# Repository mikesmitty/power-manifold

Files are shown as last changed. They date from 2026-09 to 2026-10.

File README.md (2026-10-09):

# Power Manifold

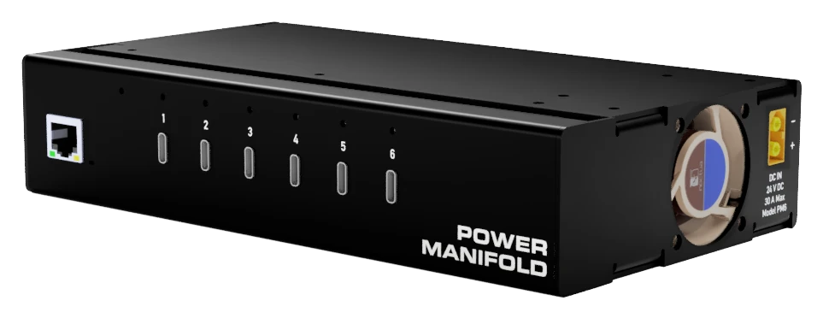
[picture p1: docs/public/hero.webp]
Power Manifold chassis from the front right


A six-port USB-C power supply: up to 100 W per port from one 24 V supply,
with per-port control, priority-based power sharing and Home Assistant
support. This repository holds the hardware (KiCad), the firmware and the
documentation site.

**Documentation:** <https://docs.powermanifold.io/>

- [First-time setup](https://docs.powermanifold.io/setup/first-time-setup/)
- [User guide](https://docs.powermanifold.io/guide/front-panel/)
- [Integrations](https://docs.powermanifold.io/integrations/mqtt/): MQTT,
  Home Assistant and the HTTP API
- [Hardware architecture](https://docs.powermanifold.io/developers/architecture/)

## Repository layout

| Path | Contents |
| --- | --- |
| `hardware/backplane` | Backplane KiCad project |
| `hardware/backplane-backer` | Insulating FR4 backer plate between the backplane and the rear wall |
| `hardware/charger-module` | Charger blade KiCad project |
| `hardware/controller` | Management controller card KiCad project |
| `hardware/left-side-plate` | Left chassis side plate, fabricated as a bare PCB |
| `hardware/pcie-breakout` | Pico 2 W development carrier for the management slot |
| `hardware/status-strip` | Front-panel status LED strip |
| `hardware/libraries` | Shared KiCad symbols and footprints |
| `hardware/CAD` | STEP exports of the boards |
| `firmware/controller` | Management controller firmware (RP2350) and its host tests |
| `firmware/charger-module` | Charger blade firmware (STM32G071) and its host tests |
| `firmware/update-proxy` | Cloudflare Worker that serves controller update images |
| `docs` | The documentation site (Astro and Starlight) |

Each firmware directory has a short README with build commands. Its full
developer documentation is in its `docs/` directory and is published on the
documentation site.

CI exports KiCad fabrication outputs when a board changes, and
release-please cuts a release for each component.

## License

Copyright 2024-2026 Michael Smith.

| Part | License |
| --- | --- |
| Hardware designs in `hardware/` | CERN-OHL-P-2.0 ([LICENSE-hardware](LICENSE-hardware)) |
| Documentation: Markdown files (`.md`, `.mdx`), the screenshots in `docs/src/assets/` and the site icon `docs/public/favicon.svg` | CC BY 4.0 ([LICENSE-docs](LICENSE-docs)) |
| Product renders: the images in `img/` and `docs/public/hero.webp` | None, all rights reserved |
| Everything else, including the firmware, the web page, the tools and the code of the documentation site | MIT ([LICENSE](LICENSE)) |

Third-party material keeps its own terms:

- `hardware/libraries/`: symbols, footprints and 3D models, most of them
  from the KiCad libraries, EasyEDA and part makers.
- Third-party 3D models inside the board exports in `hardware/CAD/`.
- `firmware/controller/lib/monocypher/`: CC0 or BSD-2-Clause, see its
  `LICENCE.md`.

Libraries that the firmware builds download, such as the Pico SDK and ST's
USB-PD stack, are not part of this repository. Each firmware release lists them and
their licenses in its SBOM (`.cdx.json`).

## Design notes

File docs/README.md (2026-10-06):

# Power Manifold docs

Documentation site for Power Manifold, built with [Astro](https://astro.build)
and [Starlight](https://starlight.astro.build). Published to
<https://docs.powermanifold.io/> by the `Docs` GitHub Actions
workflow on every push to `main` that touches `docs/` or `firmware/*/docs/`.

```sh
npm install
npm run dev      # http://localhost:4321/
npm run build    # static output in dist/
```

## Where pages come from

- **User guide** (`setup/`, `guide/`, `integrations/`) and the hardware
  architecture (`developers/architecture.md`) are written here, under
  `src/content/docs/`. Every page needs a `title` in its frontmatter.
- **Firmware developer pages** are written next to the firmware, in
  `firmware/controller/docs/` and `firmware/charger-module/docs/`, as plain
  GitHub Markdown. `scripts/sync-firmware-docs.mjs` copies them into
  `src/content/docs/developers/` before every `dev` and `build` (`npm run
  sync` on its own). Those copies are ignored by git; edit the source files.
  A new file needs an entry in the script's `PAGES` list.

The sidebar is generated from the directories (see `astro.config.mjs`).

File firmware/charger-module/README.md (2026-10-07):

# Power Manifold Charger Module Firmware

Firmware for the STM32G071 on the gen-3 charger blade (`hardware/charger-module`
from release 0.15.0 on). It runs the blade's USB-C port with ST's USB-PD
stack, a TPS55288 converter and a TCPP02-M18 port protector, and serves a
register file to the controller over the backplane.

## Quick start

```sh
cmake -S . -B build -G Ninja
ninja -C build                      # build/charger-module.elf, .bin, .hex
```

```sh
cmake -S test -B test/build && cmake --build test/build
ctest --test-dir test/build --output-on-failure
```

The controller's build bundles `build/charger-module.bin` and programs blades
with it over the backplane.

## Documentation

Developer documentation lives in [`docs/`](docs/) and is published on the
[documentation site](https://docs.powermanifold.io/) under
*For developers*:

- [Overview](docs/overview.md): what the blade is, its protection, how the
  port runs, pin map, source layout, ST's stack and its license, building,
  flashing and the console.
- [Register map and updates](docs/register-map.md): the backplane register
  map and how the controller programs the blade through the ROM bootloader.

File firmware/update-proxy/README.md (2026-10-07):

# Update proxy

A Cloudflare Worker that serves the controller's signed release images over
plain HTTP. The controller's update pull has no TLS, and GitHub release
downloads are HTTPS-only behind a redirect; this sits between the two.

| Path | Answer |
|---|---|
| `/controller/<x.y.z>/<board>/controller.signed.bin` | the signed image of release `controller-firmware-v<x.y.z>` for a board: `pwrman_controller_card`, or `pico2_w` while that stand-in is still built |
| `/controller/<board>/latest.json` | `{"version":"x.y.z","url":"http://fw.powermanifold.io/controller/<x.y.z>/<board>/controller.signed.bin"}`: the newest release, once its signed image for the board exists |

Nothing else is served. The newest version is read from this repository's
`.release-please-manifest.json`; images are fetched from GitHub once and
answered from Cloudflare's cache after that, the pointer for ten minutes at a
time. The Worker does not need to be trusted: a controller installs an image
only when its signature checks out and it is no older than what it runs (see
"Signed updates" in the controller README).

## Deploying

1. The hostname is `fw.powermanifold.io` (`routes` in `wrangler.toml`); the
   `powermanifold.io` zone has to be in the Cloudflare account that deploys.
2. Let plain HTTP through for that hostname: a Configuration Rule that turns
   **Always Use HTTPS** off for it. Otherwise Cloudflare answers port 80 with
   a redirect, which the controller cannot follow.
3. `npx wrangler deploy`
4. Check what a controller will see — a `200` with a `Content-Length`, over
   HTTP:

   ```
   curl -si http://fw.powermanifold.io/controller/pwrman_controller_card/latest.json
   curl -sI http://fw.powermanifold.io/controller/<x.y.z>/pwrman_controller_card/controller.signed.bin
   ```

A firewall rule in front of the Worker has to let both path shapes through:
those under `/controller/` ending in `/controller.signed.bin` or
`/latest.json`.

On the Workers Free plan the Worker stops answering past the daily request
limit rather than billing; updates are then unavailable until the limit
resets.

## Using it

A controller asks `latest.json` once a day by itself (its `update_url`
setting is this host by default) and offers the release it names in Home
Assistant and on its console, where `update latest` installs it. A specific
release can be pulled by URL:

```
update http://fw.powermanifold.io/controller/0.12.0/pwrman_controller_card/controller.signed.bin
```

The controller's limits on the URL: 63 characters of host, 159 of path.

## Local run

`npx wrangler dev`, then `curl -si http://127.0.0.1:8787/controller/pwrman_controller_card/latest.json`.

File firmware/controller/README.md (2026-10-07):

# Power Manifold Controller Firmware

Native pico-sdk firmware for the management controller: an RP2350 that
supervises up to six charger blades through the backplane's I2C mux and GPIO
expander, shares the chassis power budget between them, drives the port
lights, and serves the web page, the HTTP API, MQTT with Home Assistant
discovery, and a serial console.

The production target is the `hardware/controller` card in the backplane's
management socket: an RP2350A with a WIZnet W6100 for wired Ethernet and a
Raspberry Pi RM2 for Wi-Fi.

## Quick start

```sh
export PICO_SDK_PATH=~/.pico-sdk/sdk/2.2.0   # with lib/btstack and lib/mbedtls checked out
cmake -B build -G Ninja
ninja -C build
```

```sh
cmake -S test -B test/build && cmake --build test/build
ctest --test-dir test/build --output-on-failure
```

## Documentation

Developer documentation lives in [`docs/`](docs/) and is published on the
[documentation site](https://docs.powermanifold.io/) under
*For developers*:

- [Building](docs/building.md): toolchain, board targets, network options,
  the fake-blade simulator, host tests.
- [Internals](docs/internals.md): the two cores, GPIO map, blade
  generations, warm starts and keeping ports powered, bus voltage, wired
  Ethernet, the UPS link, the fan and the logs.
- [Flash layout and updates](docs/flash-and-updates.md): partitions, first
  programming, OTA, signed images, try-before-you-buy and blade firmware
  updates.
- [Serial console](docs/console.md): every console command.

What an owner sees (setup, the web page, port settings, Home Assistant, the
MQTT topics and the HTTP API) is in the
[user guide](https://docs.powermanifold.io/).

Signing keys are covered in [`keys/README.md`](keys/README.md).

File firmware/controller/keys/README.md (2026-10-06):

# Update signing keys

Every `*.pem` in this directory is an Ed25519 **public** key that the
firmware trusts: an image installs over the network only when one of them
signed it (see "Signed updates" in the controller README). The build turns
them into `update_keys.h` (`tools/update_keys.py`); with no keys here, a
build accepts unsigned images and says so.

Private keys never belong in this repository.

## Adding a key

Export the public key as PEM (`-----BEGIN PUBLIC KEY-----`) and commit it
under a name that says where the private half lives:

```
gcloud kms keys versions get-public-key <version> --key <key> \
    --keyring <keyring> --location <location> --output-file keys/kms-primary.pem
```

```
ykman piv keys generate --algorithm ed25519 --pin-policy always \
    --touch-policy always 9c keys/yubikey-backup.pem
```

Keep two: the one the release workflow signs with, and an offline backup
used only to sign the release that replaces a lost or leaked primary.

## Retiring a key

Delete its file and release. That release has to be signed by a key the
fielded firmware still trusts, which is what the backup is for. A controller
that never takes the release keeps trusting the old key.

## Signing

The release workflow signs both released builds (the Pico 2 W's
`controller.bin` and the controller card's) with Cloud KMS
(`.github/workflows/release-please.yml`) and checks the result against the
keys here before publishing it. It reads two variables from the
`firmware-signing` environment:

| Variable | Value |
|---|---|
| `UPDATE_SIGNING_KMS_KEY` | `projects/…/locations/…/keyRings/…/cryptoKeys/…/cryptoKeyVersions/…` |
| `GCP_WORKLOAD_IDENTITY_PROVIDER` | `projects/…/locations/global/workloadIdentityPools/…/providers/…` |

There is no service account and no stored credential. The provider accepts
GitHub's OIDC tokens for this repository only (by repository ID), and the
key's `roles/cloudkms.signer` is granted to the pool's
`attribute.environment/firmware-signing` principal set: a job signs only by
running in that environment, so the environment's protection rules are what
guard the key.

Until `UPDATE_SIGNING_KMS_KEY` is set, releases are published unsigned.

With the backup key, which lives in a YubiKey's PIV signature slot (9c,
generated on the key, PIN and touch required for every signature) and has no
copy anywhere else:

```
tools/sign_image.py sign build/controller.bin --board pwrman_controller_card --yubikey
test/build/verify_image build/controller.signed.bin pwrman_controller_card
```

That needs YubiKey Manager (`ykman`) and firmware 5.7 or later on the key.

By hand, with any other signer that produces a plain (not prehashed) Ed25519
signature:

```
tools/sign_image.py tbs build/controller.bin --board pwrman_controller_card      # -> controller.tbs, 112 bytes
<sign controller.tbs, giving a 64-byte signature, raw or base64>
tools/sign_image.py attach build/controller.bin --board pwrman_controller_card --signature controller.sig
test/build/verify_image build/controller.signed.bin pwrman_controller_card       # the firmware's check, these keys
```

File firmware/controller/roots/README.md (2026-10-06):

# Let's Encrypt roots

The CA certificates in this directory are built into the controller image by
`tools/letsencrypt_roots.py`, which CMake runs for every build. A verified TLS
link to a broker configured by name trusts them when no certificate is
installed in the settings; a broker configured by address, or one whose
certificate did not come from Let's Encrypt, needs its certificate installed
instead. The TLS section of the controller README has the whole rule.

They are the four roots published at <https://letsencrypt.org/certificates/>
as of 2026-10-04: the two current ones and the two of the next generation,
which Let's Encrypt cross-signs from the current ones until the root programs
carry them.

| File | Subject | Key | Valid to | SHA-256 fingerprint |
| --- | --- | --- | --- | --- |
| `isrg-root-x1.pem` | ISRG Root X1 | RSA 4096 | 2035-06-04 | `96:BC:EC:06:26:49:76:F3:74:60:77:9A:CF:28:C5:A7:CF:E8:A3:C0:AA:E1:1A:8F:FC:EE:05:C0:BD:DF:08:C6` |
| `isrg-root-x2.pem` | ISRG Root X2 | ECDSA P-384 | 2040-09-17 | `69:72:9B:8E:15:A8:6E:FC:17:7A:57:AF:B7:17:1D:FC:64:AD:D2:8C:2F:CA:8C:F1:50:7E:34:45:3C:CB:14:70` |
| `isrg-root-ye.pem` | Root YE | ECDSA P-384 | 2045-09-02 | `E1:4F:FC:AD:5B:00:25:73:10:06:CA:A4:3A:12:1A:22:D8:E9:70:0F:4F:B9:CF:85:2F:02:A7:08:AA:5D:56:66` |
| `isrg-root-yr.pem` | Root YR | RSA 4096 | 2045-09-02 | `E5:7B:7E:6F:15:0C:41:91:02:E8:D5:C0:55:72:9F:F9:67:B9:D1:A8:29:BF:00:CE:C8:9C:A6:04:EB:F4:A8:6F` |

Limit this directory to the roots the firmware should trust by default.
Anyone can get a certificate from a public CA for a name they control, so
every root here widens who could stand in for a broker whose name they also
control. Let's Encrypt is included because it issued the certificates of
most brokers that have one. To add or replace a root, download its
PEM from the page above, check the fingerprint printed by

```sh
openssl x509 -in roots/<file>.pem -noout -fingerprint -sha256
```

against the page, drop the file here and rebuild. An expired root uses only
flash space and can be removed at the next cleanup.

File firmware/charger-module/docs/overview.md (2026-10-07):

# Charger blade firmware

Firmware for the gen-3 charger blade (`hardware/charger-module` from release
0.15.0 on): an STM32G071C8 as the USB-PD source controller, in place of the
MPQ4242 that negotiated on its own in the gen-2 blade.

## What the blade is

| Part | Role | Bus |
| --- | --- | --- |
| U1 STM32G071C8T6 | PD controller (UCPD1), supervisor, backplane I2C slave | |
| U3 TPS55288 | buck-boost converter, 0.8–21 V in 20 mV steps, current limit in 50 mA steps | private I2C, 0x74 |
| U5 TCPP02-M18 | CC switches and protection, VCONN switch, VBUS switch gate driver (Q3/Q4), over-current trip across R27, VBUS discharge, current monitor | private I2C, 0x34 |
| U4 TLV7022 | VBUS over-voltage comparators on TCPP_EN | |
| U2 LP2985A-33 | 3.3 V from the slot's 5 V, always on | |

The MCU runs from the slot's 5 V rail, so it runs and answers the
controller whenever the blade is seated. The slot's EN line is the
TPS55288's EN/UVLO pin: with EN low the converter is in shutdown whatever the
firmware does, and its registers return to their defaults.

### Protection that does not depend on the firmware

- **Over-voltage:** comparator half A trips at the DAC-set threshold
  (`ovp.h`, 1.2 × the contract voltage), half B at a fixed 23.0 V. Either
  pulls TCPP_EN low, which puts the TCPP02 in its OFF state and opens the
  VBUS switch.
- **Over-current:** the TCPP02 trips at 42 mV across R27 (7 mΩ), about 6 A,
  and latches until the firmware writes its control register again.
- **Reset state:** PA15 does not drive TCPP_EN and R9 holds it low; the DAC
  pin floats and R2 holds the threshold at 0 V. A blank, halted or crashed
  MCU leaves the switch open. The watchdog restarts a stuck one.

The firmware's share is the order of operations (`power.c`):

- the threshold covers the higher of the two voltages for as long as the
  output moves between them: up, the threshold goes first; down, it follows
  once VBUS has arrived;
- the converter's output is enabled only behind the closed VBUS switch, and
  ramps VBUS up from 0 V;
- the converter runs forced PWM while its output has to come down. The board
  straps it for PFM (R22 75k), where it blocks reverse current and cannot
  pull its own output down: an unloaded 20 V would stay 20 V. The mode
  register overrides the strap for the duration, in one write that keeps VCC
  on the slot's 5 V;
- after any fault TCPP_EN is taken low, and everything is set up afresh when
  the controller clears the fault.

## How the port runs

The port is **armed** while the slot's EN is high and the converter has
answered since it rose, the controller has enabled the port and given it a
current ceiling, and no fault that pulls ALERT# is latched. Otherwise it is
dark: the TCPP02 in hibernate with its CC switches open, so a sink sees no
source at all.

Armed, ST's stack detects the sink, reads the cable's e-marker, advertises
the table `pdo.c` builds from the controller's limits and the cable, and
hands each accepted request to the power path. New limits from the
controller reach an attached sink as fresh Source_Capabilities.

Any of these latches a fault, takes the port down and pulls ALERT#:

| Fault | Source |
| --- | --- |
| `OVP` | TCPP_EN went low against the drive, however briefly |
| `OCP_VBUS`, `OCP_VCONN`, `OVP_CC`, `OTP_PORT` | TCPP02 flags |
| `CONV_SCP`, `CONV_OVP` | TPS55288 status |
| `OT_CONV`, `OT_PLUG` | an NTC past its limit (100 °C / 70 °C) for 50 ms, or reading open or shorted |
| `BUS` | TPS55288 or TCPP02 not answering |
| `VBUS` | VBUS did not reach vSafe5V or vSafe0V in time |
| `PD` | the stack did not start |

Below the two temperature trips sit two warning levels, 85 °C at the
converter and 60 °C at the receptacle. When a reading stays at or above a
warning level for 50 ms, the blade sends the sink one PD Alert with the
over-temperature bit (PD 3 sinks only; PD 2 has no Alert message). Its
Get_Status reply then reports *Warning* with the over-temperature event
flag until the reading falls 5 °C below the level. It reports *Over
temperature* once a trip has latched, and *Normal* otherwise. The port
keeps running on a warning. The specification only requires the sink to
fetch Status in response. All four temperatures are provisional until
the blade has been measured in the closed chassis.

## Pin map

From the KiCad netlist of release 0.16.1; `src/board.h` carries the same
table with the component references.

| Pin | Net | Function |
| --- | --- | --- |
| PA0 | VBUS_SENSE | ADC_IN0, receptacle VBUS through 100k / 10k |
| PA1 | IANA | ADC_IN1, TCPP02 current monitor, 294 mV/A |
| PA2 / PA3 | USART_TX / USART_RX | USART2 console on test pads J1 / J6 |
| PA4 | OVP_REF | DAC_OUT1, tracking over-voltage threshold |
| PA8 / PB15 | UCPD_CC1 / UCPD_CC2 | UCPD1, through the TCPP02 |
| PA9, PA10 | GND | UCPD1 dead-battery pins, grounded for a source |
| PA13 / PA14 | SWDIO / SWCLK | Tag-Connect J2 |
| PA15 | TCPP_EN drive | through 4.7k; the comparators can pull the line low |
| PB0 / PB2 | NTC_CONV / NTC_PLUG | ADC_IN8 / ADC_IN10, 10k B3380 under 10k |
| PB1 | VOUT_SENSE | ADC_IN9, converter output through 100k / 10k |
| PB3 | LED | green, low = lit |
| PB4 | TCPP_EN sense | low while an over-voltage comparator holds the line |
| PB5 | ALERT# | slot B15, open drain |
| PB6 / PB7 | SCL / SDA | I2C1 slave, slot A14 / B14 |
| PB8 | EN | slot B16, input |
| PB10 / PB11 | USB_SCL / USB_SDA | I2C2 master, private bus |
| PB12 | CONVERTER_FLT | TPS55288 FB/INT, low = fault |
| PB13 | FLG# | TCPP02 FLGn, low = fault |

No crystal: HSI16 runs the core, and the UCPD is clocked from it by design.

## Source layout

Everything outside `src/hw/` and `src/usbpd/` is hardware-free and runs in
the host tests.

| File | What it holds |
| --- | --- |
| `include/blade_regs.h` | the backplane register map, shared with the controller's driver |
| `src/board.h` | pin map, addresses, analog scaling |
| `src/supervisor.c` | the blade's loop: EN, the controller's registers, faults, telemetry, arming |
| `src/port.c` | what the port offers and what it has agreed to |
| `src/power.c` | the power path and the order it is operated in |
| `src/pdo.c` | Source_Capabilities table from the limits; Request checking |
| `src/regmap.c` | the register file behind the I2C slave |
| `src/ovp.c` | over-voltage threshold and its DAC code |
| `src/sense.c` | ADC counts to mV, mA and degrees |
| `src/tps55288.c`, `src/tcpp02.c` | part drivers over `src/bus.h` |
| `src/usbpd/` | the glue ST's stack expects, under ST's file and function names: settings, policy callbacks, power interface, board power functions |
| `src/hw/` | pins, tick, watchdog, ADC, DAC, console, both I2C peripherals; register level on the CMSIS device header |
| `src/main.c` | start-up; hands the main loop to the stack |

### ST's stack

Fetched at configure time, none of it kept in this repository
(`cmake/st_usbpd.cmake`), at the versions X-CUBE-TCPP 4.2.0 ships together:

| Component | Version | License |
| --- | --- | --- |
| `stm32-mw-usbpd-core`, the policy engine and protocol layer, a binary library | 5.3.0, `PD3_CONFIG_SPR` | SLA0044: ST microcontrollers only |
| `stm32-mw-usbpd-device-g0`, the UCPD device layer | 3.5.2 | SLA0044 |
| `stm32g0xx_hal_driver`, of which only the LL drivers are built | 1.4.5 | BSD-3-Clause |

`PD3_CONFIG_SPR` is the smallest build of the core with both PPS and the
structured VDMs that read a cable's e-marker. The stack runs without an RTOS:
`USBPD_DPM_Run` is the main loop and calls the supervisor once per turn.
It uses UCPD1, DMA1 channels 2 and 4, and TIM1.

The stack identifies itself with vendor ID 0xFFFF, the value the
specification gives to vendors without one from the USB-IF.

A built image contains ST's library. SLA0044 allows passing it on in binary
form for ST microcontrollers, with ST's copyright notice, conditions and
disclaimer in what accompanies it.

## Building

Needs CMake 3.18, Ninja and the GNU Arm toolchain (`arm-none-eabi-gcc`) on
the path, and network access at configure time for the CMSIS headers and
ST's stack.

```sh
cmake -S . -B build -G Ninja
ninja -C build
```

produces `build/charger-module.elf`, `.bin` and `.hex`: 44 KB of the 64 KB
of flash. `-DBLADE_WATCHDOG=OFF` builds without the independent watchdog.
The controller's build picks `build/charger-module.bin` up from here as the
image it bundles (its `BLADE_IMAGE` option).

### Host tests

```sh
cmake -S test -B test/build && cmake --build test/build
ctest --test-dir test/build --output-on-failure
```

## Flashing

SWD on the Tag-Connect footprint J2 (TC2030: 1 = 3.3 V, 2 = SWDIO, 3 = NRST,
4 = SWCLK, 5 = GND), with any CMSIS-DAP probe. The blade needs its 5 V: seat
it in a powered backplane, or feed 5 V to the slot's 5 V fingers.

```sh
openocd -f interface/cmsis-dap.cfg -f target/stm32g0x.cfg \
    -c "program build/charger-module.elf verify reset exit"
```

A factory-fresh chip starts its ROM bootloader until it has been programmed
and power-cycled once — or, seated in a chassis whose controller carries an
image, until the controller programs it over the backplane.

## Console

USART2 on the test pads J1 (TX) and J6 (RX), 115200 8N1, 3.3 V. Transmit
only. One line a second, and a line for every change of EN and of the
controller's configuration:

```
en=1 armed=1 st=8b vdda=3301 vout=9012 vbus=8987 iout=1480 contract=9000/2000 conv=41.8 plug=33.1 fault=0000
```

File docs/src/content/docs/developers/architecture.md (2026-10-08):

---
title: Hardware architecture
description: "Architecture of the six-blade managed USB-PD chassis, its interconnects, and the supervisory firmware model."
sidebar:
  order: 1
---

Power Manifold is a six-port managed USB Power Delivery (USB-PD) power supply. Six charger blades and a management card plug into a backplane. Each blade runs its own USB-C port. A Raspberry Pi RP2350 on the management card supervises all six through an I2C multiplexer, divides the chassis power budget between them by priority, drives the status lights, and serves the network interfaces.

The [user guide](/guide/web-interface/) and [integrations](/integrations/http-api/) pages are the reference for every operator-facing surface. [Controller internals](/developers/controller/internals/) and the [charger blade firmware](/developers/charger-module/overview/) pages cover the firmware in more depth.

## 1. Overview

> * **Measurement at the point of load:** Every blade meters its own port and reports numbers over I2C. No analog sense line crosses the backplane. The blade's STM32G071 measures VBUS, the port current and three temperatures and serves them from a register file.
> * **One I2C segment per blade:** An 8-channel I2C switch (TCA9548A) on the backplane gives every blade its own bus segment. This isolates the trace capacitance and lets identical blades share one address (0x3A). Six channels serve the blades; two are spare.
> * **A fixed-function controller on each blade:** The blade's STM32G071 runs ST's USB-PD stack over a TPS55288 buck-boost converter and a TCPP02-M18 port protector. An over-voltage comparator and an over-current trip open the port's VBUS switch independently of the firmware. The blade MCU carries no network, settings or user interface; the management controller configures it over the backplane.
> * **Central supervision:** A single dual-core RP2350 supervises all six ports, enforces the chassis power budget and drives the status lights. The production controller is the `hardware/controller` card: an RP2350A with a WIZnet W6100 wired-Ethernet controller and a Raspberry Pi RM2 radio (§4.3). For development, a Raspberry Pi Pico 2 W can sit in the same slot on a breakout carrier (§4.2).
> * **Status lights on a separate strip:** The status lights are one serial chain of addressable LEDs on a strip behind the faceplate, fed from the backplane. Lights stay with their slots whether or not a blade is seated, and no LED data line runs through a blade's card edge.

## 2. Component selection

| Subsystem / Function | IC / Part | Location | Key Features & Justification |
| :---- | :---- | :---- | :---- |
| **PD Controller & Supervisor** | ST STM32G071C8 | Charger Blade (x6) | Cortex-M0+ with the UCPD PD PHY, running ST's USB-PD stack as the port's policy engine plus the blade's supervisor, power sequencing and the backplane register file (I2C target at 0x3A, [map](/developers/charger-module/register-map/#backplane-register-map)). Runs from the slot's 5 V, so it answers with EN low; its watchdog restarts a stuck port. |
| **Buck-Boost Converter** | TI TPS55288 | Charger Blade (x6) | 0.8–21 V output in 20 mV steps and a current limit in 50 mA steps over the blade's private I2C. The slot's EN line is its EN/UVLO pin, so EN low is shutdown whatever the firmware does. Forced PWM while the output has to come down. |
| **Port Protector** | ST TCPP02-M18 + TI TLV7022 | Charger Blade (x6) | CC over-voltage/ESD protection, VCONN switch, VBUS N-FET gate driver with a fixed-threshold over-current trip (≈6 A across 7 mΩ), VBUS discharge and a current monitor for the MCU's ADC. The dual comparator opens the switch above 1.2 × the contract voltage (DAC-set) or a fixed 23 V, independently of the firmware; a blank or crashed MCU leaves the switch open. |
| **I2C Multiplexer** | TI TCA9548A | Backplane | 8-channel bidirectional I2C switch with hardware reset (MUX_RST#). Isolates bus capacitance and allows identical I2C addresses on all blades. Channel N carries slot N+1; channels 6–7 spare. 4.7 kΩ pull-up pairs per downstream segment. |
| **GPIO Expander** | TI TCA9539 | Backplane | 16-bit I2C GPIO expander with interrupt output and hardware reset (EXP_RST#). P00–P05 = blade EN1–6 (active high), P06 = fan switch, P10–P15 = PRES#1–6 (active low); P07/P16/P17 grounded spares. All pins through 330 Ω series networks. |
| **Main Supervisor MCU** | Raspberry Pi RP2350 | Management slot | Dual Cortex-M33 @ 150 MHz, 520 KB SRAM, PIO state machines. Production: RP2350A on the controller card (§4.3). Development: Pico 2 W (adds the CYW43439 radio) on the pcie-breakout carrier (§4.2). |
| **Ethernet Controller** | WIZnet W6100-L | Controller card (§4.3) | Hardwired dual-stack IPv4/IPv6 TCP/IP + 10/100 MAC/PHY over SPI, into a MagJack whose link and activity LEDs it drives directly. SPI0 GP16–19 + RSTn GP20 + INTn GP21, matching WIZnet's EVB-Pico2 boards. |
| **Radio Module** | Raspberry Pi RM2 | Controller card (§4.3) | CYW43439, the same silicon as the Pico 2 W, on the same GPIOs (GP23 power enable, GP24 data, GP25 CS, GP29 clock), so one WiFi stack and Improv Wi-Fi setup serve both boards. |
| **Status Lights** | WS2812C-2020-V6 | Status strip (x7) | Addressable RGB LEDs in a single serial chain behind the faceplate: D1 is the chassis light, D2–D7 are ports 1–6. The strip plugs into the backplane at J9 (to its J1), which carries the backplane's 5 V rail and LED_DATA from the management socket through the 220 Ω series resistor R1; DIN comes from the controller's 3.3 V GPIO. |
| **Backplane Power Path** | LM74800-Q1 + 2 × BSC014N06NS, 40 A SMD fuse (Reomax STS2400, 63 V DC), SMCJ33CA | Backplane | Back-to-back FETs in common drain behind the fuse at the XT60 input. The first is the ideal diode for reverse-polarity and reverse-current blocking. The second is a load switch that cuts the bus above ≈34 V (100 kΩ / 3.74 kΩ on OV, fed through the SW disconnect so the ladder draws nothing in shutdown) and below ≈17.7 V (100 kΩ / 6.81 kΩ on EN/UVLO from the common-drain mid-point, re-closing at ≈19.3 V, §7.4), and ramps the bus up at power-on (1 kΩ + 220 nF on HGATE, ≈0.5 A inrush). TVS-clamped (§7.4). The clamp's 33 V stand-off and the ≈34 V cut-off set the bus ceiling. The cut-off disconnects the bus; it does not clamp it. Everything ahead of the second FET (U2, Q1/Q2, the OV ladder, the raw-side capacitors) is protected by its own 60–100 V ratings. |
| **Logic Rail** | TI TPS16416 eFuse + Diodes AP64352 | Backplane | VIN → TPS16416 eFuse (0.40 A active current limit, ≈11.2 W ceiling at 28 V, UL 2367 recognized and IEC 62368-1 CB certified) → 5 V buck (5.6 µH, 2 × 22 µF out) feeding the mux and expander, every pull-up, the LED chain, the fan and the 5 V fingers of all seven slots. The eFuse makes the buck and the whole 5 V domain a PS1 circuit (§7.4). The buck's enable divider (100 kΩ / 7.5 kΩ from the eFuse output: on ≈16.8 V, off ≈15.1 V) is the low-bus backstop behind the LM74800's cut-out. The blades run their logic from it and the controller card regulates its own 3.3 V from it; there is no 3.3 V rail on the backplane. |
| **Fan Switch** | AO3400A | Backplane | Low-side MOSFET driven from expander P06 (100 kΩ gate pull-down, SS34 flyback across the fan). The fan runs from the 5 V rail, which keeps the 30 V part off the bus. |

## 3. Blade card edge (slots 1–6)

The standard 36-pin PCIe x1 card-edge form factor provides high current capacity, mechanical keying, and staggered presence-detection pins (a seating check; the system is not serviced live, see §7.5). The high-current DC rails (pins 1–11) and the low-voltage digital signals (pins 12–18) sit on opposite sides of the key notch.

| Pin | Side A (Component Side) | Side B (Solder Side) | Pin | Functional Description & Electrical Requirements |
| :---: | :---- | :---- | :---: | :---- |
| **A1** | **PRSNT1#** *(Short Pin)* | **PGND** | **B1** | Presence sense loop lead (A1, short pin; see §7.5). B1 joins the main power return and serves as the pin-1-end sacrificial ground. |
| **A2** | **VIN** | **PGND** | **B2** | Main DC input (24 V nominal, +20 %/−15 %; the hardware tolerates 32 V, with the clamp and the LM74800 cut-off setting that ceiling under the TPS55288's 36 V input limit) and high-current power return; fused again on the blade. The opposed pairs keep the inductive loop area small. Total 6-pin continuous capacity: ~6.6 A; worst-case draw ~5.3 A at 100 W from a 20 V bus. |
| **A3** | **VIN** | **PGND** | **B3** |  |
| **A4** | **VIN** | **PGND** | **B4** |  |
| **A5** | **VIN** | **PGND** | **B5** |  |
| **A6** | **VIN** | **PGND** | **B6** |  |
| **A7** | **VIN** | **PGND** | **B7** |  |
| **A8** | **PGND** | **PGND** | **B8** | Power ground plane extension and thermal dissipation fingers. |
| **A9** | **PGND** | **PGND** | **B9** | (B9 carries EXP_RST# at the management slot only; grounded at charger slots.) |
| **A10** | **PGND** | **GND** | **B10** | Power-to-signal ground transition boundary. (B10 carries LED_DATA at the management slot only.) |
| **A11** | **GND** *(Shield Guard)* | **GND** *(Shield Guard)* | **B11** | Guard pins flanking the key notch. |
| **--- MECHANICAL KEY / POLARIZING NOTCH ---** |  |  |  |  |
| **A12** | **5V** | **5V** | **B12** | Regulated 5 V logic supply from the backplane's AP64352 buck, powering the STM32 and the TCPP02 through an LP2985 3.3 V regulator. The blade carries no I2C or ALERT# pull-ups: the segment I2C pull-ups are on the backplane, the ALERT# pull-up on the controller. |
| **A13** | **GND** | **GND** | **B13** | Dedicated quiet logic ground reference plane. |
| **A14** | **SCL** | **SDA** | **B14** | I2C clock (A14) and data (B14) from the TCA9548A mux channel. SDA/SCL pull-ups to the 5 V rail are on the backplane (one 4.7 kΩ pair per downstream segment). |
| **A15** | **GND** *(Shield Guard)* | **ALERT#** | **B15** | Active-low open-drain line, held low by the STM32 while a fault is latched, wire-OR'd across all blades into GLOBAL_ALERT#; shielded by A15. Neither the blades nor the backplane pull it up; the controller does. |
| **A16** | **GND** | **EN** | **B16** | Hardware enable driven by the backplane GPIO expander; a 100 kΩ pull-down on the blade holds it off. It is the TPS55288's EN/UVLO, while the STM32 stays up on the 5 V finger and reports the line's state. |
| **A17** | **GND** *(Shield Guard)* | **PRSNT2#** *(Short Pin)* | **B17** | Presence sense loop return (B17). The shorter pin asserts PRSNT# only at full seating. |
| **A18** | **GND** *(End Guard)* | **GND** *(End Guard)* | **B18** | Outer edge ESD guard and termination reference. |

### 3.1. Slot numbering

Ports are numbered 1–6 by the backplane silkscreen, and every per-slot resource follows that number: the firmware's port index *n*−1 selects TCA9548A channel *n*−1, drives EN from expander pin P0(*n*−1), reads PRSNT# on P1(*n*−1) and renders pixel *n* of the light chain, whose pixel 0 is the chassis light ahead of port 1. The socket reference designators do not run in slot order, hence the table.

| Slot | Socket | I²C segment | Mux channel (pins) | EN | PRSNT# | Pixel | Position |
| :---: | :---: | :---: | :---: | :---: | :---: | :---: | :---- |
| 1 | J3 | SCL1/SDA1 | 0 (SC0/SD0) | P00 | P10 | D2 (after the chassis light D1) | leftmost, next to the management socket J2 |
| 2 | J5 | SCL2/SDA2 | 1 | P01 | P11 | D3 | |
| 3 | J7 | SCL3/SDA3 | 2 | P02 | P12 | D4 | |
| 4 | J4 | SCL4/SDA4 | 3 | P03 | P13 | D5 | |
| 5 | J6 | SCL5/SDA5 | 4 | P04 | P14 | D6 | |
| 6 | J8 | SCL6/SDA6 | 5 | P05 | P15 | D7 (last) | rightmost, at the fuse and XT60 end |

EN and PRSNT# reach the expander through 330 Ω arrays (RN4/RN5 and RN6/RN7) whose elements are pinned 1–8, 2–7, 3–6, 4–5; the fan sits on P06 through RN5's third element. Seen from the front, the backplane has the management socket at the left, the six charger sockets 17.75 mm apart to its right, and the power input at the far right. Facing the faceplate, port 1 is on the left and port 6 on the right. The status strip puts each port's light above it and the chassis light to the left of port 1. The power-up sweep runs left to right, chassis light first.

## 4. Management slot

The controller rides a card in a seventh card-edge socket on the backplane, beside the six charger slots. There are no internal cables, the card uses the same guides as the blades, and the connector family is the same.

### 4.1. Management slot pinout

The management socket reuses the blade connector and pin geography: power half before the key notch, logic half after it. Management-only signals occupy pins that are grounded at the charger slots, so the two socket types stay drop-in compatible at the PCB level.

| Pin | Side A (Component Side) | Side B (Solder Side) | Pin | Management Slot Functionality |
| :---: | :---- | :---- | :---: | :---- |
| **A1** | **GND** | **GND** | **B1** | No presence circuit on the management slot (see §7.5). |
| **A2–A7** | **VIN** | **PGND** | **B2–B7** | Main DC bus, available to the management card for its own regulation if needed; neither controller board uses it. |
| **A8–A9** | **PGND** | **PGND / EXP_RST#** | **B8–B9** | B9 = TCA9539 hardware reset line, 10 kΩ to the 5 V rail on the backplane; the controller pulls it low open-drain. |
| **A10** | **PGND** | **LED_DATA** | **B10** | Single-wire WS2812C chain data into the backplane (220 Ω series). |
| **A11** | **GND** *(Shield Guard)* | **GND** *(Shield Guard)* | **B11** | Notch guard ground shield. |
| **--- MECHANICAL KEY / POLARIZING NOTCH ---** |  |  |  |  |
| **A12** | **5V** | **5V** | **B12** | Backplane-sourced 5 V (AP64352). The controller card makes its own 3.3 V from it (§4.3); the dev carrier leaves it unused. |
| **A13** | **GND** | **GND** | **B13** | Quiet digital ground plane reference. |
| **A14** | **SCL** | **SDA** | **B14** | Upstream I2C bus to the TCA9548A mux and TCA9539 expander. |
| **A15** | **EXP_INT#** | **GLOBAL_ALERT#** | **B15** | Expander interrupt (blade insertion/removal) and the wire-OR'd blade ALERT# line. Both open-drain with no backplane pull-up; the controller pulls them up to its 3.3 V. |
| **A16** | **GND** | **MUX_RST#** | **B16** | TCA9548A hardware reset, which clears a hung downstream I2C segment without a power cycle. 10 kΩ to the 5 V rail on the backplane; the controller pulls it low open-drain. |
| **A17** | **GND** | **GND** | **B17** | Grounded (no presence loop). |
| **A18** | **GND** *(End Guard)* | **GND** *(End Guard)* | **B18** | Outer edge ESD ground guard. |

Cross-insertion: the sockets are mechanically identical. A charger blade seated in the management slot stays dark, because its port never arms until a controller has configured it, and nothing on the management slot's bus will.

### 4.2. Development carrier: pcie-breakout + Pico 2 W

`hardware/pcie-breakout` is a passive adapter from the management-slot card edge to a 2.54 mm 1x10 header, wired point-to-point to a Raspberry Pi Pico 2 W per the firmware's GPIO map for that board:

| Header Pin | Signal | Pico 2 W GPIO |
| :---: | :---- | :---- |
| 1 | VIN | — (unused) |
| 2 | 5V | — (unused; the Pico is USB-powered) |
| 3 | GND | GND |
| 4 | SCL | GP5 (I2C0) |
| 5 | SDA | GP4 (I2C0) |
| 6 | EXP_INT# | GP6 |
| 7 | EXP_RST# | GP8 |
| 8 | MUX_RST# | GP7 |
| 9 | LED_DATA | GP2 (PIO) |
| 10 | GLOBAL_ALERT# | GP3 |

GP16–21 stay reserved for the wired-Ethernet path (W6100 per the EVB-Pico2 mapping), matching the controller card.

### 4.3. Controller card: hardware/controller

`hardware/controller` is the production management card. It carries an RP2350A (QFN-60, 12 MHz crystal) with the flash described below; a WIZnet W6100-L on SPI0 (GP16–19, RSTn GP20, INTn GP21, the EVB-Pico2 map) with its own 25 MHz crystal and a Hanrun HR913550A MagJack whose link and activity LEDs the W6100 drives directly; and a Raspberry Pi RM2 radio module on the Pico 2 W's CYW43439 pin map (GP23 power enable, GP24 data, GP25 CS, GP29 clock). An AP7361C LDO makes the card's 3.3 V from the 5 V rail, which the slot fingers feed in the chassis and the unpopulated USB header feeds on the bench. SWD is on a 3-pin JST-SH header; BOOTSEL and RUN are push buttons; a 3-pin JST SH header (J5) carries a 3.3 V UART (UART0 on GP12/GP13, 1 kΩ series) for a Mean Well LAD-xxxBU UPS supply, whose serial ground is its V−, common with the chassis VIN−.

The backplane signals land on GP1 (EXP_RST#) and GP8 (MUX_RST#) through 2N7002 open-drain drivers working against the backplane's 10 kΩ pull-ups, GP2 (LED_DATA), GP4/GP5 (SDA/SCL, 4.7 kΩ to 3.3 V on the card), GP6 (EXP_INT#, internal pull-up only) and GP7 (ALERT#, 4.7 kΩ to 3.3 V). ALERT# and both resets sit on different pins than the dev carrier's §4.2 map, and the FET drivers invert the resets (GPIO high asserts reset), so the firmware carries a board header for the card (`firmware/controller/boards/pwrman_controller_card.h`, built with `PICO_BOARD=pwrman_controller_card`) that selects the card's pin map, the inverted reset drive, the 16 MB flash and its partition layout. The front-panel button is on GP22, and a 120 kΩ / 10 kΩ divider brings VIN to GP28/ADC2 for bus-voltage measurement. GPIO 3, 9–15, 26 and 27 are free. Because the mux and expander run from the backplane's 5 V, the card drives the two reset lines through N-channel FETs (the backplane's 10 kΩ pull-ups set the high level, and the RP2350's boot-time pull-down leaves the FETs off, so a controller reboot never resets the expander) and pulls EXP_INT# and GLOBAL_ALERT# up to 3.3 V itself.

**Flash: RP2350A + external W25Q128 (16 MB) on the primary QSPI chip-select.** The RP2354's 2 MB in-package flash would leave about 960 KB per image slot under A/B updates, and the CYW43439 WiFi firmware alone takes 220 KB of that; in-package flash cannot be enlarged. A second chip on QMI CS1 beside an RP2354 does not help either: the RP2354 shares its QSPI pads with the stacked die, the SDK has no CS1 flash driver, and the image slots stay capped at 2 MB. Because the RP2350A and RP2354A share the QFN-60 footprint, the layout keeps a lean assembly variant open: populate the RP2354A and leave the external flash unpopulated (never both: they share a chip-select). QMI CS1 (GPIO0 on this package) stays free for possible PSRAM.

## 5. Mechanical and thermal

> * **Status lights:** The status strip sits behind the faceplate with each port's light above its USB-C port, so a slot's light shows whether or not a blade is seated.
> * **Management card at the faceplate:** The controller card's RJ45 MagJack aligns flush with the front faceplate to the left of ports 1–6.
> * **Ethernet grounding and ESD:** The RJ45 shield bonds to the chassis through its EMI spring fingers; the magnetics' center taps terminate Bob-Smith style into the chassis-bonded ground region (§7.3).
> * **Thermal distribution:** Each blade uses copper pours with thermal via arrays under the TPS55288 and the output FET's drain to carry heat into the card-edge ground planes (PGND pins A8–A10, B2–B9). Two NTCs, at the converter and at the receptacle, are read out by the controller, and the blade trips its own port on them (100 °C / 70 °C, held for 50 ms).

## 6. Firmware architecture and supervisory state machine

Implemented in `firmware/controller` (native pico-sdk C).

### 6.1. Dual-core RP2350 execution model

The firmware runs on two cores. **Only core 1 accesses the backplane.**

> * **Core 1, engine (real-time power supervision):**
>   * 100 Hz supervisory tick: round-robins the TCA9548A channels reading each blade's register file in one burst read, runs the per-port state machine and the budget arbiter.
>   * Sole owner of the I2C bus and the TCA9539 (blade EN, presence, fan). Presence is re-read every 100 ms and on EXP_INT#.
>   * Services GLOBAL_ALERT# (edge interrupt + level check every tick): sweeps powered ports and switches off offenders via EN.
>   * Renders the WS2812C chain via PIO and publishes a seqlock telemetry snapshot plus a heartbeat.
> * **Core 0, management plane:**
>   * lwIP over CYW43 WiFi and/or the W6100 wired netif (DHCP or static addressing; the wired link holds the default route when both are up): MQTT client (optionally over TLS) with Home Assistant discovery and LWT availability, mDNS, SNTP, embedded web UI + JSON REST API (optionally over HTTPS), Prometheus `/metrics`, a console log ring with UDP syslog forwarding, USB CDC (and RTT) maintenance CLI, Improv Wi-Fi setup over the same CYW43 radio.
>   * Owns settings (ping-pong flash sectors, CRC-protected) and feeds the hardware watchdog, but only while the core-1 heartbeat stays fresh, so either core stalling reboots the system.
> * **Between them:** a command queue (core 0 → 1), an event queue (1 → 0), and the telemetry seqlock. Every management surface is a thin transport over the same command/telemetry interface.

### 6.2. Per-port state machine

The blade negotiates PD contracts on its own, so there is no in-line "negotiating" state: the engine constrains the advertised PDO set ahead of time (a current ceiling and a voltage cap) and reacts to the contracts it observes.

| State | Entry Condition / Trigger | Actions & Hardware Control | LED Indication | Next State Transitions |
| :---- | :---- | :---- | :---- | :---- |
| **ABSENT** | PRES# high (no blade in slot). | EN low, mux channel unused, budget released. | Dim Amber | → PROBE on PRES# low (→ DISABLED if administratively off). |
| **PROBE** | Blade seated (at boot, the seated blades are released into PROBE one at a time, 250 ms apart, in priority order). | One attempt per tick: select the mux channel, read the blade's register file at 0x3A, clear its latched faults, write the current ceiling and voltage cap, enable the port, assert EN. 3 failures → FAULT. | Blinking Cyan (2 Hz) | → IDLE on success. → FAULT on repeated probe failure. |
| **IDLE** | Powered, advertising, no sink. | 15 W base budget reservation held. Poll the blade each tick. | Solid White | → ACTIVE on sink attach. → ABSENT on removal. |
| **ACTIVE** | Sink attached, contract in place. | Full contract wattage reserved. Telemetry at tick rate; contract changes tracked against the budget. Measured draw under `charged_mw` for `charged_min` marks the port *charged* (a like period of draw clears it again); the *off when charged* policy and the per-port sleep timer end in DISABLED from here. | Solid Green (<11 V) / Solid Blue (≥11 V); Solid White, as IDLE, once *charged* | → IDLE on detach. → THROTTLED on budget denial. → FAULT on alert. → DISABLED by auto-off. |
| **THROTTLED** | Contract would exceed the chassis budget. | Advertisement clamped to the granted wattage (never below 15 W); the refused ask is remembered for recovery (§6.3). | Pulsing (1 Hz) in the port's active color (Solid White once *charged*) | → ACTIVE when freed budget covers the original ask. → IDLE on detach. → FAULT on alert. |
| **FAULT** | Any fault the blade latched: its own OVP/OCP trips, converter faults, an NTC over its limit, a part or the PD stack failing. | EN low immediately, budget released, fault latched for diagnostics, 5 s cooldown; the blade is told the fault has been recorded so its latch (and ALERT#) clear. | Blinking Red (5 Hz) | → PROBE after cooldown (auto-retry; a fault whose cause persists comes straight back and repeats the cycle). → ABSENT on removal. |
| **DISABLED** | Administrative off (CLI/MQTT/REST/web), an auto-off policy, or a power-up policy of `off` (or `last` with the port last switched off). | EN low, budget released. | Off | → PROBE on enable. → ABSENT on removal. |

> * **Chassis light and chain-wide indications:** the chassis light, first in the chain and left of port 1, blinks red at 5 Hz while the DC bus is past its low (19 V) or high (29 V) flag, the same as a faulted port, and keeps blinking at the fault floor when the lights are at 0. Otherwise it breathes on a 2 s cycle while a management condition needs attention: blue while the Wi-Fi setup window is open, amber while settings are open for first-time setup, red while no link holds an address (slower than the bus-fault blink, so the two red states differ by speed). For the first 15 s after power-up (`NET_START_GRACE_MS`) having no address is not shown and does not open Wi-Fi setup, so a boot that is still waiting for DHCP or a Wi-Fi join flashes neither red nor blue. With nothing to report it glows green at the master brightness capped at 32, so it is dim on a bright chain and dims no further than the other lights on a dimmed one. The power-up sweep lights all seven pixels in chain order, chassis light first (white or rainbow, `led boot`), and doubles as a chain-order check. Improv *identify* alternates every other pixel in blue at 2 Hz and outranks everything. Master brightness (`led`, the web *Settings* panel, or the Home Assistant number) scales all of it; at 0 the chain is dark except a faulted port, which keeps blinking at a floor level. Two schedules dim the whole chain to `led_dim` (default 4): a night window in local time (SNTP plus a fixed `tz` offset) and idle dimming after a period with no port event; any port event restores full brightness.

### 6.3. Power budget and priority allocation

To stay within a fixed supply rating (default budget 360 W, i.e. 15 A at 24 V; six 100 W ports = 600 W aggregate peak capacity), the supervisor accounts for power by contract:

> * **Reserved budget, not measured draw:** When a device negotiates a contract, the supervisor reserves the full contract wattage; measured draw is telemetry, not accounting. Every powered port also holds a 15 W base reservation (5 V @ 3 A):
>   P_headroom = P_chassis_max − SUM(P_reserved[i])
> * **Priority shedding:** Each port carries a priority (0 = highest; default = port number; `port <n> priority` in the CLI). When a new contract would exceed the budget, strictly lower-priority powered ports are renegotiated downward first (worst priority first, largest reservation breaking ties, never below the 15 W floor) by lowering the blade's current ceiling, after which the blade re-advertises without dropping VBUS. Equal priority is never shed: first come, first served among peers.
> * **Warm start:** A gen-3 blade with a sink attached keeps the limits it holds when they are within the settings, including a ceiling the budget had lowered (that port carries on throttled). Its contract is then reserved like any new one and is clamped only if it does not fit. Recovery waits until every adopted port's sink is in the budget.
> * **Hard-reset reporting:** A gen-3 blade counts the PD hard resets it sends and receives (HR_SENT / HR_RECEIVED). The controller turns each new count into an `EVT_PD_RESET` fault-log record and MQTT event, with the milliseconds since the sink was last sent new capabilities.
> * **Self-clamp fallback:** If shedding lower-priority ports cannot free enough, the requesting port itself is clamped to whatever headroom remains.
> * **Recovery:** A throttled port remembers the ask that was refused. When the whole refused amount fits the freed budget (detach, renegotiation, shed elsewhere), the reservation is claimed first, then the full advertisement is restored and the sink renegotiates upward. When only part of it fits, the clamp steps up by the available headroom in ≥5 W increments, at most one step per second per port, so partially freed power is allocated immediately. Freed headroom is allocated in priority order: a lower-priority throttled port waits while any higher-priority throttled port exists, since that port can also take headroom partially (EVT_THROTTLE codes: 0 clamped, 1 restored, 2 partial step).

### 6.4. Implementation notes

> * **Blade interface:** The blade's register file (`firmware/charger-module/include/blade_regs.h`, shared verbatim with the blade firmware and versioned by a `PROTO` register) is a snapshot the controller reads in one burst (status flags, the PD contract, VBUS, port current, converter output and three temperatures), plus a control register, a command register (re-advertise, hard reset, clear faults) and the two limits. Configuration writes take effect together at the end of the transfer, limits ahead of the enable, so the port never arms on limits it has not been given. Out of reset the port is off until configured; a blade whose MCU restarts (watchdog, a brown-out on the slot's 5 V) reports its configuration gone, and the port goes back through PROBE with no EN cut and no fault recorded. Faults latch on the blade with ALERT# low until the controller clears them, so nothing is missed while the controller is away; the controller maps them onto its port fault codes, and the blade's raw word travels with the fault event. The converter and receptacle temperatures surface in the status table, the JSON, `/metrics` and two Home Assistant sensors per port, and feed the fan policy.
> * **Blade firmware:** The controller manages the blade's firmware. The STM32G0 ROM bootloader answers on the same bus at 0x51, the controller image carries the blade firmware it was built with, and a blade found in its bootloader (blank, reset into it, or set to boot through it, the option the controller programs once) is checked against that image, written when it differs and started. A running blade on another version is sent to the bootloader only when the port is not in use: before its port is first powered, after the port has had nothing attached for ten seconds, or once its device is switched off (its draw under the charged threshold for the charged time). It is never updated while its device is on (`port <n> update` overrides this) or while the controller's own image is on trial, and this cannot be turned off. While an update waits, the port's light flashes amber every 3 s, the problem list names the port, and Home Assistant shows a *Blade firmware* update whose Install runs the waiting updates at once. The blade's watch timeout (the `WATCH_S` register) recovers a blade whose firmware has stopped responding: with EN low and no controller access for that period, the blade resets into its bootloader. With EN high it never does, so the ports keep running while the controller is restarting, updating or absent.
> * **TCA9539 initialization order (critical):** The expander's Output Port registers power up as **0xFF (all high)** while every pin defaults to input (hi-Z); the blades' 100 kΩ EN pull-downs hold all ports off in that state. Firmware MUST write the Output Port registers to **0x0000 first**, and only then write the Configuration registers (P0 = 0x80: EN1–6 + fan as outputs, P07 input; P1 = 0xFF: all inputs) to make the EN pins outputs. Reversing the order drives every EN high the instant the config write lands, enabling all blades at once and bypassing the per-port probe/budget sequence. The same rule applies after any EXP_RST# assertion or brown-out re-init.
> * **Expander/bus failure recovery:** Five consecutive expander read failures trigger a MUX_RST# hardware reset (frees a hung downstream segment) and a TCA9539 re-init, which drops every EN. This fails safe: the ports re-probe and renegotiate from scratch.
> * **Flash layout (partition table):** An RP2350 partition table (per-board JSON in `partitions/`, compiled to `partition_table.uf2` and flashed once) divides the flash into A/B image slots plus a `data` partition; the 16 MB production map adds an `assets` partition, and the 4 MB Pico 2 W map has 2 × 1536 KB slots and 1016 KB of data. The firmware never hardcodes offsets: partitions are located **by 64-bit ID** through the bootrom at boot, so one binary spans every layout, and raw-offset reads go through the untranslated XIP alias (0x1C000000) so they stay correct when the bootrom maps slot B at the XIP base. Each image carries an IMAGE_DEF version derived from FW_VERSION (major, minor×256+patch), so the bootrom boots the newer slot and BOOTSEL drag-drop updates land in the inactive slot. A TBYB-flagged image boots as a *trial* and self-commits (bootrom explicit-buy) only after 10 s of an unbroken engine heartbeat and, with WiFi configured, once the network has come up at least once since boot. Otherwise any reboot, watchdog reset, or the 10-minute deadline reverts to the previous image.
> * **OTA:** `POST /api/v1/update` streams a firmware image (the signed .bin; a UF2 or an unsigned .bin only from the console, auto-detected; picotool's E10 marker block skipped) into the A/B slot the running image did not boot from. (The bootrom's `rom_pick_ab_partition_during_update` is not used: it refuses whenever slot B holds no image, which is how a board programmed with the factory image starts.) Writes go sector-by-sector through `flash_safe_execute`; the image's first sector, the only place the bootrom looks for an IMAGE_DEF, is erased up front and written last with the TBYB flag patched in (refused for hashed/signed images, which the flag edit would invalidate), so an interrupted transfer never leaves a bootable half-image. After CRC/read-back verification the controller reboots via a bootrom flash-update boot (the only path that boots a TBYB image), handing off to the trial/commit flow above. One transfer at a time; a stalled client is dropped after 30 s; an uncommitted trial refuses updates so the known-good fallback slot is never overwritten. Before the first sector is written the image must carry a valid Ed25519 signature from one of the public keys built into the firmware (a 176-byte trailer on the raw .bin: length, board, SHA-512, signature), be built for this board, and be no older than the running image; only the console's `update --unsigned` / `--downgrade` waive those, since reaching it takes the USB header or a debug probe. The controller also checks for a newer release itself: shortly after the network comes up and daily after that it fetches a version pointer from the update source (a setting; `http://fw.powermanifold.io` by default, a plain-HTTP proxy in front of the GitHub releases; empty turns the check off). A newer release is reported to Home Assistant's update entity and on the console. It installs when requested, or by itself 1 to 7 days (random per controller) after it is first seen, between 03:00 and 05:00 local time, unless the `update_auto` setting is off, the owner postponed automatic installs or skipped that version, or that version was rolled back before.
> * **Settings:** Ping-pong pair of 4 KB sectors with sequence numbers and CRC32 (a power failure mid-write leaves the previous copy intact), in the first two sectors of the `data` partition. Records carry a layout version; an older record loads with explicit defaults for the fields it predates, so a firmware update never wipes settings. `GET /api/v1/settings/export` and `POST /api/v1/settings` round-trip the whole set as JSON for backup and restore.
> * **Boot reason:** deliberate reboots and the HardFault handler stamp the watchdog scratch registers before resetting, every boot leaves a sentinel there, and the rest comes from the chip's reset-cause bits (which a SYSRESETREQ does not update, hence the sentinel). The banner, `info`, the status JSON, Home Assistant and a fault-log record name the cause of every start: power-on, brown-out, RUN pin, debugger, watchdog, requested reboot, firmware update, trial revert, warm reset, or a HardFault with core, PC, LR and CFSR.
> * **Warm start:** a controller reboot (update, requested, watchdog, HardFault) never cuts port power. The expander runs from the backplane's 5 V and neither controller board asserts its reset when the RP2350 resets, so it keeps its registers. The engine reads the expander before touching it: one still holding this firmware's configuration is adopted as it stands (a *warm start*); only the power-on state (a *cold start*) gets the reset-and-configure sequence, outputs low first. Powered blades are then re-supervised in priority order without an EN cut: identify the blade, treat any fault latched meanwhile as a fault now, and rewrite the blade's limits only where what it holds differs from the settings. The boot policy still switches off what it would at a cold boot. A powered blade that does not answer, then or later, keeps its power: it is shown as silent and polled until it does, and only a fault, a removal or the operator takes a port down. There is no budget arbitration or firmware fault response for the seconds the controller is away; the blades' own limits cover that window.

### 6.5. Management plane

Every surface is a thin transport over the same command queue and telemetry snapshot. The [HTTP API](/integrations/http-api/), [MQTT](/integrations/mqtt/) and [Home Assistant](/guide/home-assistant/) pages carry the full reference (endpoint, topic, entity and console tables); this section is the architectural summary.

> * **MQTT (primary remote surface):** `pwrman/<name>/status` (retained chassis status) and `.../port/<n>/telemetry` at 1 Hz, engine events on `.../event` (each with a `kind` in Home Assistant's event vocabulary and a human-readable `text` for faults and auto-off), availability via LWT. Commands: `.../port/<n>/set` (ON/OFF/hard_reset/src_cap) plus per-port `priority`, `limit`, `volt`, `boot`, `autooff` and `sleep` setters, chassis `budget`, `fan` (auto/on/off), `led`, `charged_mw`/`charged_min`, `improv` (open a Wi-Fi setup window), `update` (install the retained `.../update/latest` pointer) and `blades` (update the blades whose update is waiting, now). Settings changed remotely persist via a debounced save.
> * **Home Assistant discovery**, per port: power/voltage/current/state/energy sensors (energy `total_increasing`, usable in the energy dashboard; the state sensor carries the last fault as attributes), converter and receptacle temperatures, an enable switch, hard-reset/re-announce buttons, priority and current-limit numbers, a voltage-cap select (5–20 V), a power-up select (on/off/last), an off-when-charged switch and a sleep-timer number, a *charging* binary sensor, and an *events* entity fed from the event topic. Chassis: power/headroom/energy sensors, budget and LED-brightness numbers, the fan select, charge-complete threshold numbers, diagnostic sensors for boot reason and LED mode, a *Problem* binary sensor, an *Open Wi-Fi setup* button, a firmware `update` entity whose Install pulls the pointer's URL over plain HTTP into the OTA core, an *Automatic updates* switch, *Postpone update 7 days* / *Skip this update* buttons, and a *Blade firmware* `update` entity that shows an update while a blade's update waits on a port in use, its Install running those updates at once. Entity names carry the port's label; ids stay put across renames.
> * **Web UI + REST:** broker-independent local surface: live status page with per-port graphs, fault-log and console panels, and a settings panel covering every setting (unlocked by the API token, or, while no token exists, for ten minutes after Improv provisioning succeeds or for the first hour after power-up for a request arriving over Ethernet, an hour a short button press restarts). `GET /api/v1/status`, `/faults`, `/log`, `/settings`, `/settings/export`; `POST /api/v1/settings` (import), `/port/<n>`, `/fan`, `/budget`, `/faults/clear`, `/reboot`, `/update` (OTA push), `/update/check`, `/update/latest` (OTA pull of the known release), `/update/postpone`, `/update/skip`, `/improv`, `/tls` and `/tls/remove` (the HTTPS certificate, with `GET /api/v1/tls`), and `/console` with `GET /api/v1/console` for the page's console; `GET /metrics` for Prometheus. With the `https` setting on and a certificate installed, the same server listens on 443 and port 80 only redirects; see [controller internals](/developers/controller/internals/#https). Changes take a Bearer token; with none stored they are refused until first-time setup saves one. Every request must name the controller in `Host` (its address, its name, `<name>.local` or the `hostnames` setting) against DNS rebinding, and a settings POST through a setup door must be `application/json` against cross-site form posts; see [controller internals](/developers/controller/internals/#web-server-request-checks).
> * **USB CLI:** provisioning (WiFi/MQTT credentials, device name, token, addressing, DNS, syslog), status/info, budget, per-port control/priority/name/limit/power-up policy/auto-off/sleep, charge thresholds, fan policy, LED brightness and schedule, timezone, fault log, settings export, `update <http-url>` OTA pull, `sim` fault injection on fake-blade builds, `bootsel`. The same commands run from the web page behind the API token, except `token`, `defaults`, `bootsel`, unsigned or older updates, `vin cal`, and the bench tools `stack`, `i2c`, `sim` and `button`.
> * **Addressing:** DHCP on every link by default; a static address goes on the wired link when a W6100 is present, else on WiFi (never both). A configured DNS server always wins over DHCP's.
> * **Console log:** everything printed is mirrored into a 4 KB ring, readable over the API and the page, and optionally forwarded line by line to a UDP syslog host as RFC 5424, including the boot messages printed before the network came up. Each console command is logged once with its passwords and token masked.
> * **Health:** an aggregate *problem* flag (any port faulted, engine stalled, trial firmware uncommitted, wired link down while WiFi carries the traffic) with a text description, on every surface. The MQTT client drops and reconnects a link that stops acknowledging publishes, so a stalled broker path cannot hold lwIP's buffers.
> * **Fan policy:** auto mode (default) follows total chassis power with hysteresis (settings `fan_on_w`/`fan_off_w`, defaults 80/60 W) and a 30 s anti-flap hold. It also runs while any port holds a contract over `fan_on_ma` (default 3 A), and while any blade's converter reads 65 °C or more or any receptacle 55 °C or more, until every converter reads below 55 °C and every receptacle below 45 °C. Manual on/off overrides from any surface drop it out of auto; manual off still runs the fan for the temperature rule.
> * **Fault log:** faults, probe failures and boot reasons persist in the data partition right after the settings pair: a 64 KB ring of one-record 256 B flash pages (~256 records, oldest sector recycled), each carrying event, port power/contract at that instant, uptime and SNTP wall-clock time. CLI `faults` / `faults clear`, `GET /api/v1/faults`, the page's panel, and the newest per port as Home Assistant attributes.
> * **Provisioning:** an unprovisioned controller (or one off the network for five minutes) advertises the Improv Wi-Fi setup service; the hosted provisioner on this site, the Home Assistant app or any Improv client hands it credentials, and the settings then stay open for an hour so any phone or computer can set the first token (the Home Assistant app's own Improv prompt does not open the redirect link); a wired-only controller instead has its settings open for the first hour after power-up. The chassis light breathing amber shows that settings are open. Outside a window the radio's setup link is powered down.

### 6.6. Verification

The engine core (state machine + budget arbiter) is hardware-free and runs host-side against simulated drivers (`test/`, in CI on every firmware change): probe/fault/recovery paths, contract accounting, priority shedding and recovery ordering, power-up policy and staggering, charge-complete and auto-off, plus the hardware-free management pieces: the settings JSON round trip, the log ring, LED scheduling, event naming, IPv4 text, and the W6100 driver against an emulated chip. The same simulated backplane compiles into the firmware (`-DFAKE_BLADES=ON`) and loops a scripted demo (attaches, budget contention, an over-current fault), so the full management plane runs on a bare board with no backplane. The console's `sim` command pauses the script and injects seats, attaches, loads, blade faults and restarts, pinned thermometer readings, silent chips and mux/expander failures by hand, so the fault log, problem sensor and event entities can be exercised end to end. See [Building](/developers/controller/building/#fake-blade-mode-no-backplane-needed).

## 7. Grounding, chassis bonding and ESD protection

### 7.1. Two-tier grounding model

A three-domain, star-grounded topology is not physically realizable in this architecture: every blade and the backplane's buck regulator join the logic-rail return to the DC bus return, so the system contains seven or more domain ties and no single star point can exist. Splitting copper planes anyway would force every I2C, EN, ALERT#, and PRSNT# trace to cross a plane slit with a broken return path. The design therefore uses two tiers:

* **Circuit Ground (GND):** One electrically continuous ground net per board and across the card-edge interconnect. "PGND" is layout geography (named copper zones that confine high-current switching returns to defined regions, §7.2), not a separate net. All GND and PGND card-edge fingers land on the same net.
* **Chassis (CHGND):** The metal enclosure, faceplate, card guides, and connector shells, deliberately multipoint-bonded to circuit ground (§7.3). Chassis is an ESD/EMI spreading structure, never an intentional current path.

Measurement integrity comes from the architecture rather than plane splits: each blade measures its own port locally and reports numbers over I2C, so ground offset between boards never enters a measurement, and I2C noise margins are far larger than any achievable inter-board ground offset.

### 7.2. Board-level ground-zone layout

**Charger blade (4-layer, 1 oz outer / 0.5 oz inner):**

* **L2: solid, unbroken ground plane.** No slots, no splits. It is the power return, the logic reference, and the thermal spreader that carries converter heat to the card-edge fingers (§5). Every ground via from every zone lands on it. L3 carries the 5 V and 3.3 V logic pours.
* **L1 power spine ("PGND" zone):** VIN entry from fingers A2–A7/B2–B7 → input filter and capacitors → TPS55288 power stage and inductor → output capacitors → current-sense shunt → VBUS switch → USB-C receptacle. Both hot loops (input-capacitor and output-capacitor) are minimum-area and strictly local.
* **L1 logic ("GND" zones):** Logic routing from the logic-half fingers (5V, SCL/SDA, ALERT#, EN) stays off the power spine. No logic trace passes under the inductor or switch-node copper.
* **Kelvin sense routing:** Shunt sense lines run as a tight differential pair over solid ground, laterally clear of the inductor and switch node.

Zones are drawn as separate outlines on the *same net* (multiple zones, one net). They connect through the L2 plane rather than by touching on L1, so pours cannot silently merge across the geographic boundary, and a stray trace over the wrong zone keeps its return path.

**Backplane:** One solid ground plane under the entire board; all seven sockets' GND and PGND fingers land on it. VIN distributes on dedicated copper pours on the outer layers only (4-layer, 2 oz outer / 0.5 oz inner; the VIN corridor is pour-based). The DC input (−) terminal lands on the plane next to a chassis-bonded mounting hole, so the heavy-current corridor runs between the DC entry and the slots' power-half fingers; the TCA9548A / TCA9539 / LED / management-slot region is placed outside that corridor. I2C, EN, ALERT#, and PRSNT# route over the unbroken plane, with no split for them to cross.

### 7.3. Chassis bonding and enclosure

The chassis and circuit ground form one deliberately multipoint-bonded ground system (the PC-chassis model):

* **Bonded standoffs:** Plated, unmasked mounting holes (annular ring stitched with vias) on the backplane, fastened with star washers into conductive metal standoffs.
* **USB-C shells:** Each receptacle's four through-hole shell tabs solder into the blade ground pour with multiple vias; shell contact with the faceplate cutouts provides additional chassis bonds by design.
* **RJ45 MagJack (controller card):** 360° EMI spring fingers against the enclosure cutout are the shield's chassis bond. The magnetics' center taps terminate Bob-Smith style: 75 Ω per pair into a common node, then 1 nF / 2 kV into the chassis-bonded ground region at the jack.
* **DC entry:** The input (−) terminal, a bonded standoff, and the ground plane meet in one corner of the backplane, so the highest-current cable entry references chassis at its point of entry.
* **No isolation barrier:** With shells, spring fingers, and card guides bonding the chassis at many points, a capacitive CHGND-to-GND barrier could not exist in practice, so the design has none. An ESD strike to any shell or panel spreads through the chassis and returns via many bonds, with only a small fraction crossing any single board.

### 7.4. Port ESD and DC input transient suppression

* **CC lines (each blade):** The TCPP02-M18 provides CC over-voltage and ESD protection at the receptacle.
* **Data line (each blade):** A USBLC6-2SC6 array on the receptacle's data line.
* **VBUS clamp (each blade):** An ESDA25P35-1U1M TVS between VBUS and ground at the connector. USB cables are hot-plugged, and abrupt disconnection of a 100 W load produces an inductive load dump.
* **DC bus clamp (backplane input):** Bidirectional SMCJ33CA TVS across VIN and ground, behind the 40 A fuse and ahead of the LM74800 FET stage: 33 V stand-off above the 28.8 V declared maximum (the hardware tolerates 32 V), breakdown from ~36.7 V. It is bidirectional so a reversed cord meets the ideal diode's block rather than a forward-biased clamp behind the fuse. The 32 V hardware ceiling above the declared range is this stand-off and the LM74800's ≈34 V over-voltage cut-off (the 40 A SMD fuse is rated 63 V DC, so it does not set the limit); the fan switch is on the 5 V rail, so its 30 V MOSFET is off the bus. The TPS55288's 36 V input limit is the hard constraint that keeps the bus in the 24 V class (48 V operation is not feasible), so the clamp's job is holding realistic supply-side transients within the converter's absolute-maximum headroom: connection ring when the DC cord meets ~2 mF of aggregate chassis capacitance, and inductive kick if the cord or supply drops out under load. Switch the external supply on *after* the DC cord is connected (or fit an anti-spark/NTC element at the entry) to limit connection inrush.
* **DC bus undervoltage cut-out (backplane input stage):** The LM74800's EN/UVLO pin sits on a 100 kΩ / 6.81 kΩ divider (R7 / R8) from the common-drain mid-point of the FET pair. Below ≈17.7 V falling (16.8–18.5 V over the 1.091–1.159 V reference spread and 1 % resistors) it opens the second FET and disconnects the entire bus from the input; above ≈19.3 V rising (18.4–20.25 V) it re-closes through the inrush ramp. The divider keeps the worst-case turn-on under 20.4 V, the lowest voltage at which IEC 62368-1 B.2.3 tests a 24 V DC mains input. Because the whole bus goes, not just the logic rail, the blades lose VIN outright, the bulk capacitors stop being topped up, and the draw on a sagging supply falls to the LM74800's 2.87 µA shutdown current plus the divider (≈0.2 mA; the OV ladder hangs off the SW disconnect and draws nothing). Sensing the mid-point rather than the raw input is deliberate: the bus capacitors hold the mid-point up through the second FET while the ideal diode blocks, so a brief input dropout never reaches the pin and the bus rides through it (VSNS, which only feeds the OV ladder, is on the raw input as the datasheet draws it). Behind that cut, the AP64352 buck's own EN divider (100 kΩ / 7.5 kΩ from the eFuse output: on ≈16.8 V, off ≈15.1 V, 14.3–16.0 V over tolerance) is the backstop. When the bus decays through it, the TCA9539 loses VCC and its port pins go high-impedance, and each blade's EN (B16) is held low by the blade's own 100 kΩ pull-down, which shuts the converter down. The management card reboots with the rail, and on recovery the expander powers up with its ports as inputs, so no blade re-enables until firmware applies the boot policy. This hardware cut-out, not the budget engine, is the final low-bus failsafe: a sagging supply cannot be dragged below ~17.7 V with the ports still loaded, which bounds the worst bus current at roughly 36 A (six ports at 100 W just before the cut), under the 40 A fuse and within the XT60's burst rating. A supply that cannot hold 20 V under load causes a disconnect-and-restart loop, not a hazard. The controller firmware reduces the chance of that loop: under 20 V it caps every port at 3 A (60 W, 22 A worst case at the cut), its 19 V low flag fires ahead of the cut and is written to the fault log, and a chassis that restarts on a marginal bus comes up capped and staggered.
* **Logic-rail power limit (PS1, backplane):** A TI TPS16416 eFuse (U5) sits between VIN and the AP64352's input. Its active current limit is set to ≈0.40 A (24.9 kΩ on ILIM), so the power it can deliver is ≈11.2 W at 28 V (≈12 W with the limit at its tolerance ceiling, ≈13.8 W if the bus were run at the 32 V hardware limit) and ≈8.6 W at 20 V, under the 15 W that IEC 62368-1 clause 6.2.2 allows a PS1 source measured 3 s after the worst-case load. The part is UL 2367 recognized (file E169910) and IEC 62368-1 CB certified, so it is evaluated as the overcurrent protective device rather than faulted internally, and every programming pin fails toward FET-off: ILIM or IOCP open or shorted turns the FET off, OVP is tied to ground, the enable pin sits on a 1 MΩ / 120 kΩ divider from VIN, IDLY is open so the limit engages without blanking, and 10 nF on dVdT holds start-up inrush into the buck's 10 µF input capacitor to ≈0.1 A. IOCP is 0.80 A (20.5 kΩ); a sustained overload is limited for 155 ms and then auto-retried after 620 ms. Everything downstream of its OUT pin (the buck, the 5 V fingers of all seven slots, each blade's logic, the pixel chain and the fan) is therefore a PS1 circuit; the buck's enable divider is referenced to the eFuse output so the buck waits for its input before it starts switching.

### 7.5. Card-edge guarding and presence detection

The system is **not hot-pluggable**: installed USB-C cables prevent removing the front plate in service, so blades are only inserted or removed with the chassis de-energized. The presence circuit is therefore a population and seating check, not a hot-swap mechanism. It needs no precharge path, no extra finger stagger beyond the standard PCIe scheme, and no extraction-race firmware.

* **Finger heights:** Standard PCIe CEM two-length geometry. All power, ground, and signal fingers are full height; only A1 and B17 are short (CEM short-pin height per the connector drawing). Because the loop closes last, PRSNT# asserts only at *full* seating; a half-inserted blade reads absent and is never enabled.
* **Presence loop (A1 → B17):** The blade connects A1 to B17 with a plain trace: no components, no power dependency. The backplane grounds A1 at every charger slot. The loop closes only when both ends of the connector are seated, so an angled or partial insertion cannot read as present. B17 has a 10 kΩ pull-up to the 5 V rail and enters a TCA9539 input through a 330 Ω series resistor; the expander INT output provides EXP_INT#.
* **Management slot:** No presence circuit; A1 and B17 are grounded (§4.1). The management card is installed with the chassis de-energized. The firmware, not the backplane, detects whether a controller is present.
* **Firmware use:** Presence is read at boot and re-read every 100 ms plus on EXP_INT#. Empty slots are never probed and their EN lines never assert. As a further safeguard (not a hot-plug feature), any runtime PRSNT# deassertion, from a seating or vibration fault, immediately drives that slot's EN low.
* **Edge guards:** A18/B18 remain full-height sacrificial grounds at the outer end, discharging handling static before signal fingers seat during assembly; A11/B11 guard the key notch. A16 is tied to GND (no floating reserved finger next to EN), and B1 joins the main power return, so both ends of the connector row terminate in solid ground.

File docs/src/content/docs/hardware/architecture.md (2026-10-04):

---
title: Architecture specification (V2)
description: As-built architecture of the six-blade managed USB-PD chassis, its interconnects, and the supervisory firmware model.
---

This technical specification details the architecture for a six-port managed USB Power Delivery (USB-PD) power supply. The design consolidates control from distributed per-blade microcontrollers into a centralized Raspberry Pi RP2350 management controller. The architecture incorporates localized I2C sensing on each blade, centralized I2C channel multiplexing, backplane-mounted status LEDs with front-panel light pipes, a dedicated card-edge management slot, and a dual-core firmware supervisory state machine with dynamic, priority-aware power budgeting.

*Updated 2026-09-05 to match the as-built hardware (backplane v0.8.x, charger module v0.13.x, pcie-breakout) and the implemented controller firmware (`firmware/controller`; the [firmware guide](../../firmware/controller/) is the operator-facing reference for every surface), and 2026-09-30 for the gen-3 charger blade (charger module 0.15, [its firmware](../../firmware/charger-module/)), which the controller supervises alongside the gen-2 blade described throughout. Early drafts described an 8-blade chassis; the built V2 chassis carries six charger blades plus the management slot.*

## 1. Executive Summary & Architectural Overview

The original architecture utilized an RP2040 microcontroller, dedicated QSPI flash memory, crystal oscillator, boot/reset buttons, and a NeoPixel on each individual charger blade. While functional, this introduced firmware maintenance overhead, higher per-port BOM costs, and severe signal integrity challenges when measuring analog sense signals across long PCB traces.
The consolidated V2 architecture decouples power delivery from supervisory management:

> * **Digitization at the Point of Load:** Every blade meters its own port and hands the controller numbers over I2C, never analog sense lines across the backplane. On the gen-2 blade a dedicated digital current/power monitor (INA226) measures shunt voltage and bus voltage directly via Kelvin connections; on the gen-3 blade the port's own STM32G071 meters VBUS, the port current and three temperatures and serves them from a register file.
> * **Backplane Channel Isolation:** An 8-channel I2C switch (TCA9548A) on the backplane isolates capacitive trace loading and eliminates I2C address conflicts among identical blades — every gen-2 blade answers at 0x40 / 0x61, every gen-3 blade at 0x3A. Six channels serve the blades; two are spare.
> * **Two Blade Generations, One Slot:** The gen-2 blade (charger module up to 0.14) is an MPQ4242 all-in-one buck-boost PD source that negotiates on its own, with the INA226 beside it. The gen-3 blade (0.15 on) puts a microcontroller back on the blade — an STM32G071 running ST's USB-PD stack over a TPS55288 buck-boost and a TCPP02-M18 port protector — because the all-in-one part could not meet the fault-voltage and fault-current caps of IEC 62368-3 (§5.4.1 / §5.3.2) on its own. Unlike the original per-blade MCUs, this one is a fixed-function peripheral to the controller: it carries no network, settings or user interface, and the controller tells the generations apart at seating by what answers on the slot's mux channel.
> * **Centralized Intelligence:** A single dual-core RP2350 management controller supervises all six ports, enforces dynamic chassis power budgeting, and drives the status LEDs. During development the controller is a Raspberry Pi Pico 2 W (WiFi) seated in the management slot via a breakout carrier; the production controller is the `hardware/controller` card for the same slot: an RP2350A with a WIZnet W6100 wired-Ethernet controller and a Raspberry Pi RM2 radio (§4.4).
> * **Backplane LED Array & Light Pipes:** Moving the status LEDs to the backplane converts per-port LED data lines into a single serial daisy chain, freeing card-edge pins and eliminating phantom-power risks during blade insertion.

## 2. Component Selection (As Built)

| Subsystem / Function | IC / Part | Location | Key Features & Justification |
| :---- | :---- | :---- | :---- |
| **Buck-Boost Controller (gen 2)** | MPS MPQ4242 (GVE-0000, all-OTP-defaults variant) | Charger Blade (x6) | Integrated 4-switch buck-boost with I2C programmability, 100W PD output capability, programmable current limit and VOUT. Negotiates PD autonomously; the controller constrains its advertised PDO set. |
| **Power & Current Monitor (gen 2)** | TI INA226 | Charger Blade (x6) | 16-bit ΔΣ digital power monitor with hardware alert thresholding and built-in averaging. Shares the blade's 10 mΩ shunt via Kelvin taps. |
| **PD Controller & Supervisor (gen 3)** | ST STM32G071C8 | Charger Blade (x6) | Cortex-M0+ with the UCPD PD PHY, running ST's USB-PD stack as the port's policy engine plus the blade's supervisor, power sequencing and the backplane register file (I2C slave at 0x3A, [map](../../firmware/charger-module/#backplane-register-map)). Runs from the slot's 5 V, so it answers with EN low; its watchdog restarts a stuck port. |
| **Buck-Boost Converter (gen 3)** | TI TPS55288 | Charger Blade (x6) | 0.8–21 V output in 20 mV steps and a current limit in 50 mA steps over the blade's private I2C; the slot's EN line is its EN/UVLO pin, so EN low is shutdown whatever the firmware does. Forced PWM while the output has to come down. |
| **Port Protector (gen 3)** | ST TCPP02-M18 + TI TLV7022 | Charger Blade (x6) | CC over-voltage/ESD protection, VCONN switch, VBUS N-FET gate driver with a fixed-threshold over-current trip (≈6 A across 7 mΩ), VBUS discharge and a current monitor for the MCU's ADC. The dual comparator opens the switch above 1.2 × the contract voltage (DAC-set) or a fixed 23 V, independently of the firmware; a blank or crashed MCU leaves the switch open. |
| **I2C Multiplexer** | TI TCA9548A | Backplane | 8-channel bidirectional I2C switch with hardware reset (MUX_RST#). Isolates bus capacitance and allows identical I2C addresses on all blades. Channel N carries slot N+1; channels 6–7 spare. 4.7 kΩ pull-up pairs per downstream segment. |
| **GPIO Expander** | TI TCA9539 | Backplane | 16-bit I2C GPIO expander with interrupt output and hardware reset (EXP_RST#). P00–P05 = blade EN1–6 (active high), P06 = fan switch, P10–P15 = PRES#1–6 (active low); P07/P16/P17 grounded spares. All pins through 330 Ω series networks. |
| **Main Supervisor MCU** | Raspberry Pi RP2350 | Management slot | Dual Cortex-M33 @ 150 MHz, 520 KB SRAM, PIO state machines. Dev vehicle: Pico 2 W (adds CYW43439 WiFi/BT) on the pcie-breakout carrier; production: RP2350A on the controller card (§4.4). |
| **Ethernet Controller** | WIZnet W6100-L | Controller card (§4.4) | Hardwired dual-stack IPv4/IPv6 TCP/IP + 10/100 MAC/PHY over SPI, into a MagJack whose link and activity LEDs it drives directly. SPI0 GP16–19 + RSTn GP20 + INTn GP21, matching WIZnet's EVB-Pico2 boards so firmware carries over unchanged. |
| **Radio Module** | Raspberry Pi RM2 | Controller card (§4.4) | CYW43439 — the same silicon as the Pico 2 W, on the same GPIOs (GP23 WL_ON/BT_ON, GP24 data, GP25 CS, GP29 clock) — so the WiFi stack and Improv BLE provisioning carry over unchanged. |
| **Port Status Indicator** | WS2812C-2020-V6 | Backplane (x6) | Addressable RGB LEDs in a single serial chain (220 Ω series into the first pixel), paired with front-panel rigid light pipes. Powered from the backplane's 5 V rail; DIN comes from the controller's 3.3 V GPIO through the series resistor. |
| **Backplane Power Path** | LM74800-Q1 + 2 × BSC014N06NS, 40 A SMD fuse (Reomax STS2400, 63 V DC), SMCJ33CA | Backplane | Back-to-back FETs in common drain behind the fuse at the XT60 input (committed 2026-09-16): the first is the ideal diode for reverse-polarity and reverse-current blocking, the second is a load switch that cuts the bus above ≈34 V (100 kΩ / 3.74 kΩ on OV, fed through the SW disconnect so the ladder draws nothing in shutdown) and below ≈17.7 V (100 kΩ / 6.81 kΩ on EN/UVLO from the common-drain mid-point, re-closing at ≈19.3 V, §8.4), and ramps it up at power-on (1 kΩ + 220 nF on HGATE, ≈0.5 A inrush). TVS-clamped (§8.4). The clamp's 33 V stand-off and the ≈34 V cut-off set the bus ceiling; the cut-off disconnects the bus rather than clamping it, and everything ahead of the second FET (U2, Q1/Q2, the OV ladder, the raw-side capacitors) rides on its own 60–100 V ratings. |
| **Logic Rail** | TI TPS16416 eFuse + Diodes AP64352 | Backplane | VIN → TPS16416 eFuse (0.40 A active current limit, ≈11.2 W ceiling at 28 V, UL 2367 recognised and IEC 62368-1 CB certified) → 5 V buck (5.6 µH, 2 × 22 µF out) feeding the mux and expander, every pull-up, the LED chain, and the 5 V fingers of all seven slots. The eFuse makes the buck and the whole 5 V domain a PS1 circuit (§8.4). The buck's enable divider (100 kΩ / 7.5 kΩ from the eFuse output: on ≈16.8 V, off ≈15.1 V) is the low-bus backstop behind the LM74800's cut-out. The blades run their INA226 from it and the controller card regulates its own 3.3 V from it; there is no 3.3 V rail on the backplane. |
| **Fan Switch** | AO3400A | Backplane | Low-side MOSFET driven from expander P06 (100 kΩ gate pull-down, SS34 flyback across the fan). The fan runs from the 5 V rail (moved off VIN 2026-09-09), which keeps the 30 V part well clear of the bus. |

## 3. PCIe x1 Card-Edge Interconnect Pinout (Charger Blades 1–6)

The standard 36-pin PCIe x1 card-edge form factor provides high current capacity, mechanical key isolation, and staggered presence-detection pins (a seating check — the system is not serviced live; see §8.5). The layout places high-current DC rails (Pins 1–11) and low-voltage digital signals (Pins 12–18) on opposite sides of the mechanical key notch.

| Pin | Side A (Component Side) | Side B (Solder Side) | Pin | Functional Description & Electrical Requirements |
| :---: | :---- | :---- | :---: | :---- |
| **A1** | **PRSNT1#** *(Short Pin)* | **PGND** | **B1** | Presence sense loop lead (A1, short pin; see §8.5). B1 joins the main power return and serves as the pin-1-end sacrificial ground. |
| **A2** | **VIN** | **PGND** | **B2** | Main DC input power rail (24V nominal, 20V–28V declared operating range; the hardware tolerates 32V, with the clamp and the LM74800 cut-off setting that ceiling under the MPQ4242's 36V VIN limit) and high-current power return; fused again on the blade. Parallel opposed pair placement minimizes inductive loop area (EMI reduction). Total 6-pin continuous capacity: ~6.6A; worst-case draw ~5.3A at 100W from the 20V floor. |
| **A3** | **VIN** | **PGND** | **B3** |  |
| **A4** | **VIN** | **PGND** | **B4** |  |
| **A5** | **VIN** | **PGND** | **B5** |  |
| **A6** | **VIN** | **PGND** | **B6** |  |
| **A7** | **VIN** | **PGND** | **B7** |  |
| **A8** | **PGND** | **PGND** | **B8** | Power ground plane extension and thermal dissipation fingers. |
| **A9** | **PGND** | **PGND** | **B9** | (B9 carries EXP_RST# at the management slot only; grounded at charger slots.) |
| **A10** | **PGND** | **GND** | **B10** | Power-to-signal ground transition boundary. (B10 carries LED_DATA at the management slot only.) |
| **A11** | **GND** *(Shield Guard)* | **GND** *(Shield Guard)* | **B11** | High-isolation guard pins flanking the mechanical key notch. |
| **--- MECHANICAL KEY / POLARIZING NOTCH ---** |  |  |  |  |
| **A12** | **5V** | **5V** | **B12** | Regulated 5 V logic supply from the backplane's AP64352 buck, powering the INA226 on a gen-2 blade (the MPQ4242 biases its own logic from VIN) and, through an LP2985 3.3 V regulator, the STM32 and the TCPP02 on a gen-3 one. The blade carries no I2C or ALERT# pull-ups: the segment I2C pull-ups are on the backplane, the ALERT# pull-up on the controller. |
| **A13** | **GND** | **GND** | **B13** | Dedicated quiet logic ground reference plane. |
| **A14** | **SCL** | **SDA** | **B14** | Dedicated I2C Clock (A14) and Data (B14) from the TCA9548A mux channel. SDA/SCL pull-ups to the 5 V rail reside on the backplane (one 4.7 kΩ pair per downstream segment); blades carry no I2C pull-ups. |
| **A15** | **GND** *(Shield Guard)* | **ALERT#** | **B15** | Active-low open-drain fault/interrupt line — from the INA226 and MPQ4242 on a gen-2 blade, from the STM32 while a fault is latched on a gen-3 one — wire-OR'd across all blades into GLOBAL_ALERT#; shielded by A15. Neither the blades nor the backplane pull it up; the controller does. |
| **A16** | **GND** | **EN** | **B16** | Hardware enable/shutdown signal (B16) driven by the backplane GPIO expander; 100 kΩ pull-down on the blade holds it off. On a gen-2 blade it is the MPQ4242's EN; on a gen-3 blade the TPS55288's EN/UVLO, while the STM32 stays up on the 5 V finger and reports the line's state. |
| **A17** | **GND** *(Shield Guard)* | **PRSNT2#** *(Short Pin)* | **B17** | Presence sense loop return (B17). Shorter pin length ensures PRSNT# asserts only at full seating. |
| **A18** | **GND** *(End Guard)* | **GND** *(End Guard)* | **B18** | Outer edge ESD guard and termination reference. |

### 3.1. Slot Numbering (Verified Against the Netlist, 2026-09-09)

Ports are numbered 1–6 by the backplane silkscreen, and every per-slot resource follows that number in step: the firmware's port index *n*−1 selects TCA9548A channel *n*−1, drives EN from expander pin P0(*n*−1), reads PRSNT# on P1(*n*−1) and renders WS2812 pixel *n*−1. The sockets were re-annotated so the refs no longer run in slot order, hence the table.

| Slot | Socket | I²C segment | Mux channel (pins) | EN | PRSNT# | Pixel | Position |
| :---: | :---: | :---: | :---: | :---: | :---: | :---: | :---- |
| 1 | J3 | SCL1/SDA1 | 0 (SC0/SD0) | P00 | P10 | D4 (first in the chain) | leftmost, next to the management socket J2 |
| 2 | J5 | SCL2/SDA2 | 1 | P01 | P11 | D5 | |
| 3 | J7 | SCL3/SDA3 | 2 | P02 | P12 | D6 | |
| 4 | J4 | SCL4/SDA4 | 3 | P03 | P13 | D7 | |
| 5 | J6 | SCL5/SDA5 | 4 | P04 | P14 | D8 | |
| 6 | J8 | SCL6/SDA6 | 5 | P05 | P15 | D9 (last) | rightmost, at the fuse and XT60 end |

EN and PRSNT# reach the expander through 330 Ω arrays (RN4/RN5 and RN6/RN7 after the 2026-09-15 re-annotation) whose elements are pinned 1–8, 2–7, 3–6, 4–5; the fan sits on P06 through RN5's third element. The backplane sits in the chassis the way the layout draws it, seen from the front: the management socket at the left, the six charger sockets 17.75 mm apart to its right, the power input at the far right. Facing the faceplate, port 1 is therefore on the left and port 6 on the right, and each slot's pixel sits 5.7 mm to the blade's component side and just past its lower edge, so its light pipe reaches the faceplate below and to the right of the port. The power-up sweep runs left to right.

## 4. Management Interconnect Architecture

### 4.1. The Decision: Management Slot vs. Detached Controller

Two interconnect options were evaluated for joining the RP2350 controller to the backplane:

> * **Option A (rejected): detached controller.** The management PCB mounts to the rear/side chassis panel and a ~10-conductor ribbon or FFC carries the upstream bus (I2C, LED_DATA, GLOBAL_ALERT#, EXP_INT#, the reset lines, and power) from the backplane. Rejected: an internal cable assembly, a second mounting system, and no mechanical commonality with the blades.
> * **Option B (chosen, 2026-08-28): front-access management slot.** The controller rides a card that slides into a seventh card-edge socket on the backplane, alongside the six charger slots — the "Slot 9" of the original 8-blade draft. No internal cables, uniform card-guide alignment, and the same connector family as the blades.

The 10-signal interconnect set from Option A survives as the development carrier's breakout header (§4.3).

### 4.2. Management Slot Pinout (As Built)

The management socket reuses the blade connector and pin geography: power half before the key notch, logic half after it. Management-only signals occupy pins that are grounded at the charger slots, so the two socket types stay drop-in compatible at the PCB level. Netlist-verified:

| Pin | Side A (Component Side) | Side B (Solder Side) | Pin | Management Slot Functionality |
| :---: | :---- | :---- | :---: | :---- |
| **A1** | **GND** | **GND** | **B1** | No presence circuit on the management slot (see §8.5). |
| **A2–A7** | **VIN** | **PGND** | **B2–B7** | Main DC bus (24V nominal, 20V–28V operating) available to the management card for its own regulation if desired; the dev carrier leaves it unused. |
| **A8–A9** | **PGND** | **PGND / EXP_RST#** | **B8–B9** | B9 = TCA9539 hardware reset line, 10 kΩ to the 5 V rail on the backplane; the controller pulls it low open-drain. |
| **A10** | **PGND** | **LED_DATA** | **B10** | Single-wire WS2812C chain data into the backplane (220 Ω series). |
| **A11** | **GND** *(Shield Guard)* | **GND** *(Shield Guard)* | **B11** | Notch guard ground shield. |
| **--- MECHANICAL KEY / POLARIZING NOTCH ---** |  |  |  |  |
| **A12** | **5V** | **5V** | **B12** | Backplane-sourced 5 V (AP64352). The controller card makes its own 3.3 V from it (§4.4); the dev carrier leaves it unused. |
| **A13** | **GND** | **GND** | **B13** | Quiet digital ground plane reference. |
| **A14** | **SCL** | **SDA** | **B14** | Upstream I2C master bus to the TCA9548A mux and TCA9539 expander. |
| **A15** | **EXP_INT#** | **GLOBAL_ALERT#** | **B15** | Expander interrupt (blade insertion/removal) and the wire-OR'd blade ALERT# line. Both open-drain with no backplane pull-up (the EXP_INT# pull-up was removed 2026-09-07); the controller pulls them up to its 3.3 V. |
| **A16** | **GND** | **MUX_RST#** | **B16** | TCA9548A hardware reset — clears a hung downstream I2C segment without power cycling. 10 kΩ to the 5 V rail on the backplane; the controller pulls it low open-drain. |
| **A17** | **GND** | **GND** | **B17** | Grounded (no presence loop). |
| **A18** | **GND** *(End Guard)* | **GND** *(End Guard)* | **B18** | Outer edge ESD ground guard. |

Cross-insertion note: the sockets are mechanically identical. A gen-2 charger blade seated in the management slot finds MUX_RST# (idle high) on its EN finger and will run unmanaged on its MPQ4242 OTP defaults — not hazardous, but label the chassis so it doesn't surprise anyone. A gen-3 blade there stays dark: its port never arms until a controller has configured it, and nothing on the management slot's bus will.

### 4.3. Development Carrier: pcie-breakout + Pico 2 W

`hardware/pcie-breakout` is the current management card: a passive adapter from the management-slot card edge to a 2.54 mm 1x10 header, wired point-to-point to a Raspberry Pi Pico 2 W per the firmware GPIO map:

| Header Pin | Signal | Pico 2 W GPIO |
| :---: | :---- | :---- |
| 1 | VIN | — (unused) |
| 2 | 5V | — (unused; the Pico is USB-powered during dev) |
| 3 | GND | GND |
| 4 | SCL | GP5 (I2C0) |
| 5 | SDA | GP4 (I2C0) |
| 6 | EXP_INT# | GP6 |
| 7 | EXP_RST# | GP8 |
| 8 | MUX_RST# | GP7 |
| 9 | LED_DATA | GP2 (PIO) |
| 10 | GLOBAL_ALERT# | GP3 |

GP16–21 stay reserved for the wired-Ethernet path (W6100 per the EVB-Pico2 mapping), so the same firmware image spans the dev carrier and the controller card.

### 4.4. Controller Card: hardware/controller

`hardware/controller` is the production management card for the same slot, through its first pass of schematic and layout and not yet fabricated. It carries an RP2350A (QFN-60, 12 MHz crystal) with the flash described below; a WIZnet W6100-L on SPI0 (GP16–19, RSTn GP20, INTn GP21 — the EVB-Pico2 map the firmware already uses) with its own 25 MHz crystal and a Hanrun HR913550A MagJack whose link and activity LEDs the W6100 drives directly; and a Raspberry Pi RM2 radio module on the Pico 2 W's CYW43439 pin map (GP23 WL_ON/BT_ON, GP24 data, GP25 CS, GP29 clock), so WiFi, Bluetooth and the Improv BLE provisioning already running on the dev carrier carry over unchanged. An AP7361C LDO makes the card's 3.3 V from the 5 V rail, which the slot fingers feed in the chassis and the USB header feeds on the bench. SWD is on a 3-pin JST-SH header; BOOTSEL and RUN are push buttons; a 3-pin JST SH header (J5) carries a 3.3 V UART (UART0 on GP12/GP13, 1 kΩ series) for a Mean Well LAD-xxxU UPS supply, whose serial ground is its V−, common with the chassis VIN−. The backplane signals land on GP1 (EXP_RST#) and GP8 (MUX_RST#) through 2N7002 open-drain drivers working against the backplane's 10 kΩ pull-ups, GP2 (LED_DATA), GP4/GP5 (SDA/SCL, 4.7 kΩ to 3.3 V on the card), GP6 (EXP_INT#, internal pull-up only) and GP7 (ALERT#, 4.7 kΩ to 3.3 V). ALERT# and both resets sit on different pins than the dev carrier's §4.3 map, and the FET drivers invert the resets (GPIO high asserts reset), so the firmware carries a board header for the card (`firmware/controller/boards/pwrman_controller_card.h`, built with `PICO_BOARD=pwrman_controller_card`) that selects the card's pin map, the inverted reset drive, the 16 MB flash and its partition layout. A front-panel button is on GP22, and a 120 kΩ / 10 kΩ divider brings VIN to GP28/ADC2 for bus-voltage measurement. GPIO 3, 9–15, 26 and 27 are free. Because the mux and expander run from the backplane's 5 V, the card drives the two reset lines through N-channel FETs (the backplane's 10 kΩ pull-ups set the high level, and the RP2350's boot-time pull-down leaves the FETs off, so a controller reboot never resets the expander) and pulls EXP_INT# and GLOBAL_ALERT# up to 3.3 V itself.

**Flash (decided 2026-08-30): RP2350A + external W25Q128 (16 MB) on the primary QSPI chip-select.** The RP2354's 2 MB in-package flash was rejected: under A/B OTA it leaves ~960 KB per image slot, and the CYW43439 WiFi blob alone is 220 KB of the current 448 KB build — BLE and web-UI assets would crowd the ceiling, permanently, since in-package flash can't be upsized. A hybrid (RP2354 + second chip on QMI CS1) was also rejected: the RP2354 shares its QSPI pads with the stacked die, so a second chip puts the bus on the board anyway, while the SDK has no CS1 flash driver and the app slots stay capped at 2 MB. Because RP2350A and RP2354A share the QFN-60 footprint, the layout keeps a lean assembly variant open — populate RP2354A and DNP the external flash (never both: same chip-select). QMI CS1 (GPIO0 on this package) stays free for possible PSRAM.
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

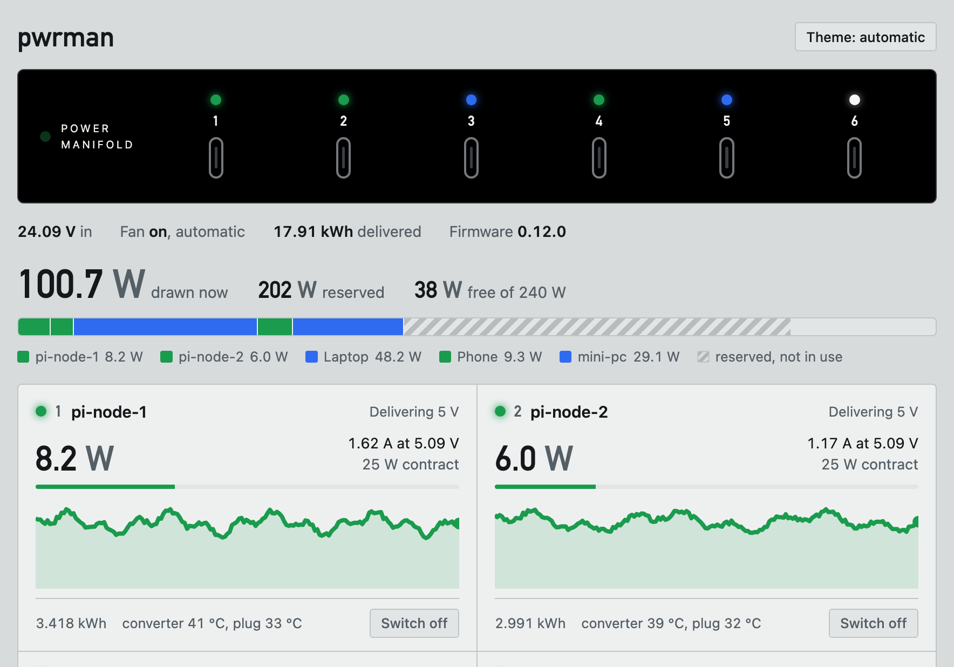
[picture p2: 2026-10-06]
docs/src/assets/web-page/overview-light.png

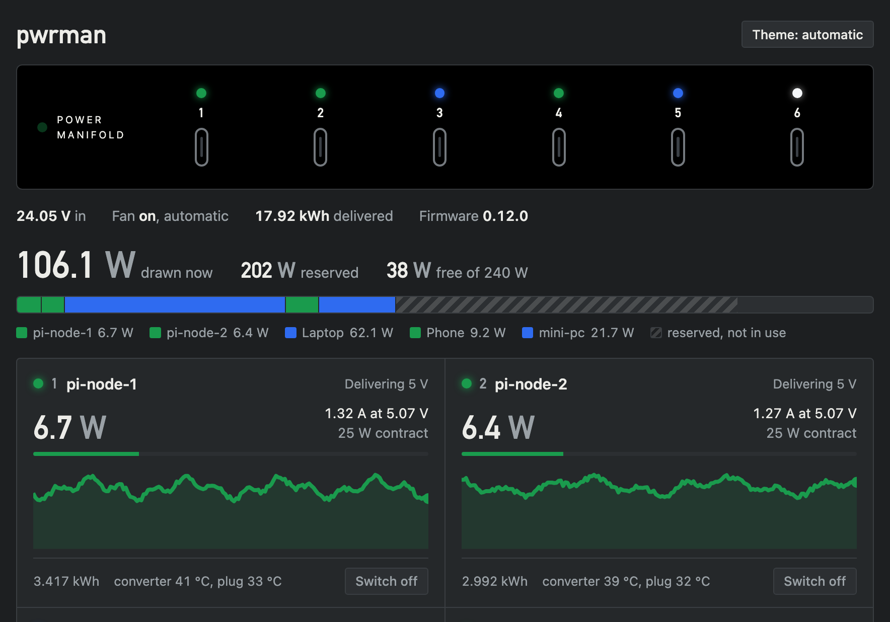
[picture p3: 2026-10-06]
docs/src/assets/web-page/overview-dark.png

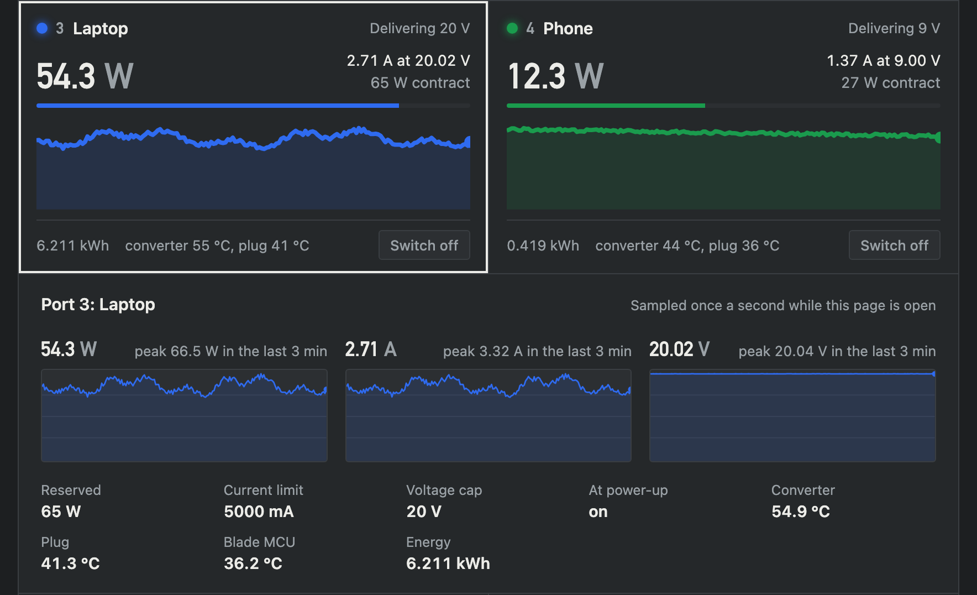
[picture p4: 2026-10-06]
docs/src/assets/web-page/port-detail-dark.png

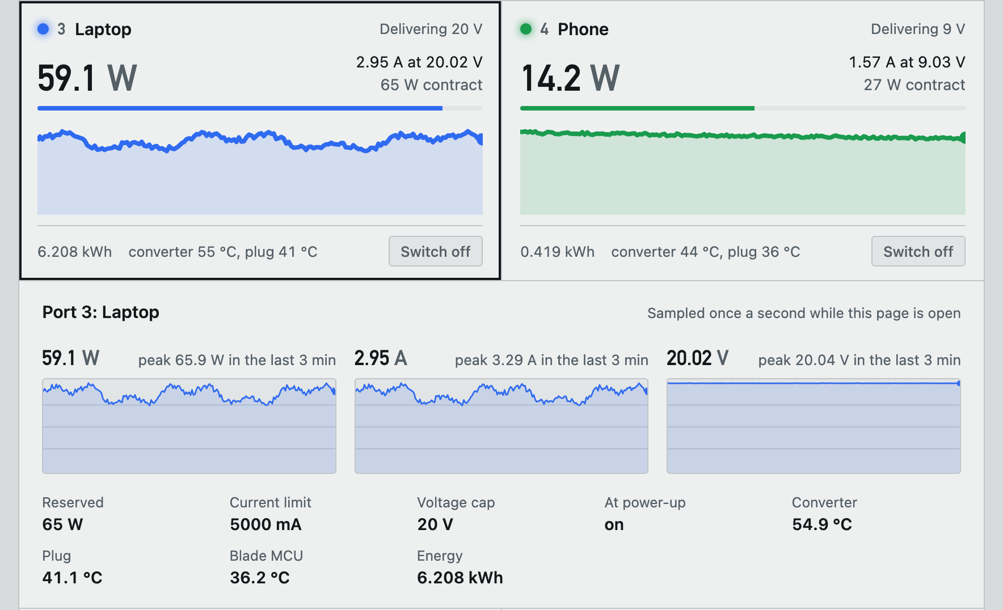
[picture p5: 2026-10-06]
docs/src/assets/web-page/port-detail-light.png

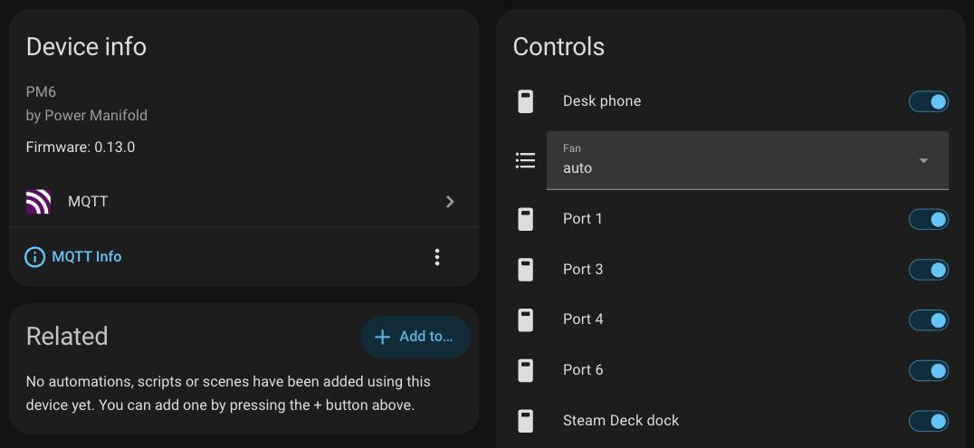
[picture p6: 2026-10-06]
docs/src/assets/home-assistant/device.png

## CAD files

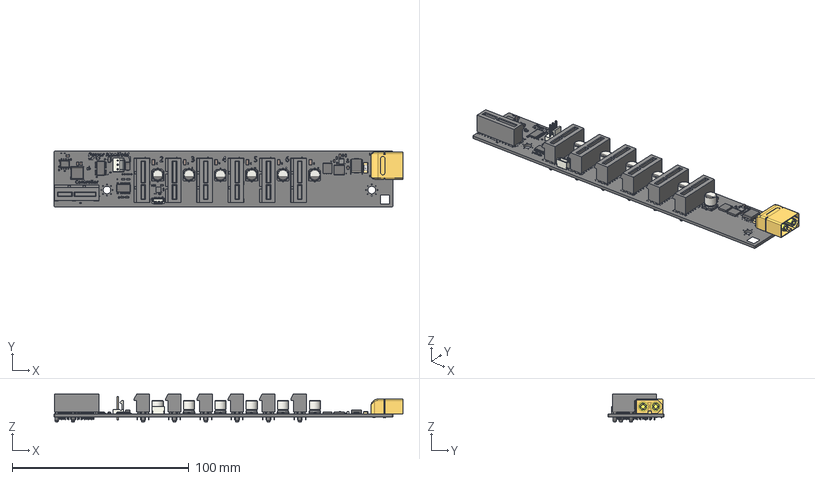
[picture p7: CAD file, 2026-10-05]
hardware/CAD/backplane.step
197.7 x 31.5 x 15.8 mm
R_0402_1005Metric x 19
WSON-12_L3.0-W3.0-P0.50-TL-EP-2
C_0402_1005Metric x 12
a71ba5e0-8551-11ed-a139-00155d22e2d7_part
a71ba716-8551-11ed-a139-00155d22e2d7_part
a71ba78e-8551-11ed-a139-00155d22e2d7_part
1001878310110TLF x 7
C_1206_3216Metric x 6
R_Array_Concave_4x0402 x 4
TSSOP-24_4.4x7.8mm_P0.65mm x 2
CP_Elec_63x77 x 6
R_0603_1608Metric x 6
XT60PW-M
Fan_Pin_Header_Straight_1x03
TDSON_8_1 x 2
LED_0603_1608Metric
D_SMA
FUSE-SMD_L6.1-W2.5-H2.5
C_0805_2012Metric x 5
SOT-23
D_SMC
SO-8_L4.9-W3.9-H1.5-LS5.9-P1.27
C_0603_1608Metric x 2
VSON-10_L3.0-W3.0-H0.6-P0.50
JST_SH_BM05B-SRSS-TB_1x05-1MP_P1.00mm_Vertical
kibot_x7yn7czr_silkscreen
kibot_x7yn7czr_PCB

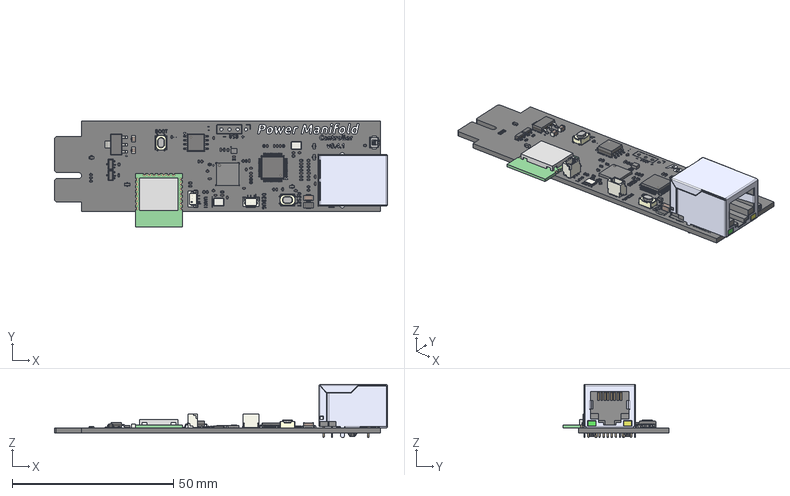
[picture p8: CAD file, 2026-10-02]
hardware/CAD/controller.step
103.3 x 32.8 x 16.6 mm
C_0402_1005Metric x 37
R_0402_1005Metric x 31
L_0603_1608Metric x 4
HR911105A_yellow_led
HR911105A_pin_001
HR911105A_pin_002
HR911105A_pin_003
HR911105A_pin_004
HR911105A_pin_005
HR911105A_pin_006
HR911105A_pin_007
HR911105A_pin_008
HR911105A_pin_009
HR911105A_pin_010
HR911105A_contact_004
HR911105A_contact_003
HR911105A_contact_002
HR911105A_contact_001
HR911105A_red_led
HR911105A_pin_011
HR911105A_pin_012
HR911105A_contact_005
HR911105A_contact_006
HR911105A_contact_007
HR911105A_contact_008
HR911105A_outer_shield
HR911105A_inner_023
JST_SH_BM03B-SRSS-TB_1x03-1MP_P1.00mm_Vertical x 2
R_0603_1608Metric
SW_SPST_B3U-3000P
SOIC-8_5.3x5.3mm_P1.27mm
C_1206_3216Metric
SOT-23 x 2
RPI-RM2-R3
C_0805_2012Metric x 2
IND-SMD_L2.0-W1.6_AOTA-B201610S3R3-101-T
Crystal_SMD_3225-4Pin_3.2x2.5mm x 2
SW-SMD_4P-L4.2-W3.2-P2.15-LS4.6 x 2
R_1206_3216Metric
LQFP-48_7x7mm_P0.5mm
SOT-223
RP2350A-QFN60
kibot_tuugralc_silkscreen x 2
kibot_tuugralc_PCB

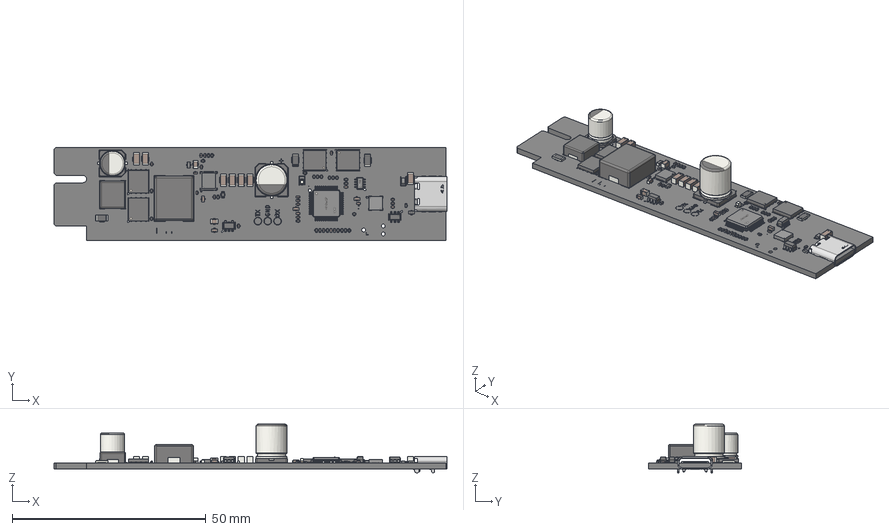
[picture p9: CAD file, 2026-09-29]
hardware/CAD/charger-module.step
101.5 x 24.0 x 12.6 mm
C_0402_1005Metric x 22
USB-C-SMD_GT-USB-7004
C_0603_1608Metric x 4
DFN1610-2_L1.6-W1.0-P1.05-RD
R_0402_1005Metric x 25
C_1206_3216Metric x 7
TDSON_8_1 x 4
SOT-23-6
a71ba5e0-8551-11ed-a139-00155d22e2d7_part
a71ba716-8551-11ed-a139-00155d22e2d7_part
a71ba78e-8551-11ed-a139-00155d22e2d7_part
SOT-23-8_L2.9-W1.6-H1.5-LS2.8-P0.65
VQFN-HR-26_L4.0-W3.5_TPS55288RPMR
CP_Elec_63x77
QFN-18_L3.5-W3.5-P0.50-TL-EP2.2
LQFP-48_L7.0-W7.0-H1.4-LS9.0-P0.50
R_1206_3216Metric x 2
C_0805_2012Metric x 2
LED_0603_1608Metric
Fuse_1206_3216Metric
L_0603_1608Metric
SOT-23-5
a75427c6-8551-11ed-a139-00155d22e2d7_part
a75428e8-8551-11ed-a139-00155d22e2d7_part
a7542960-8551-11ed-a139-00155d22e2d7_part
CP_Elec_8x10
R_0603_1608Metric x 2
kibot_qr3137r0_silkscreen x 2
kibot_qr3137r0_PCB

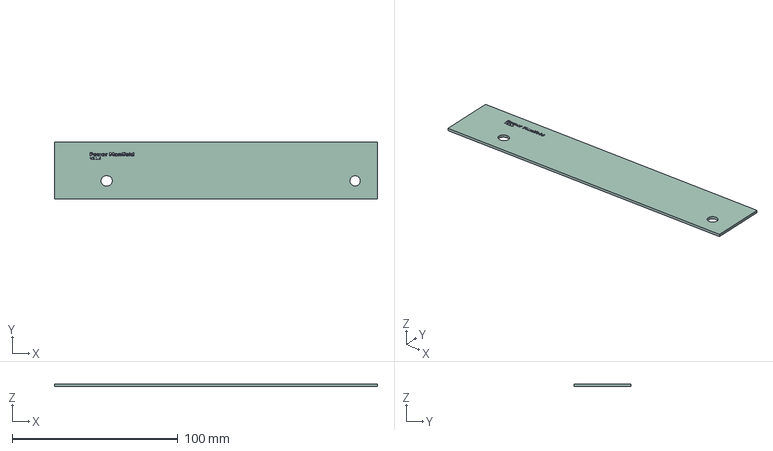
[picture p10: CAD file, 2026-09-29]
hardware/CAD/backplane-backer.step
195.0 x 34.5 x 1.58 mm
backplane-backer_silkscreen
backplane-backer_PCB

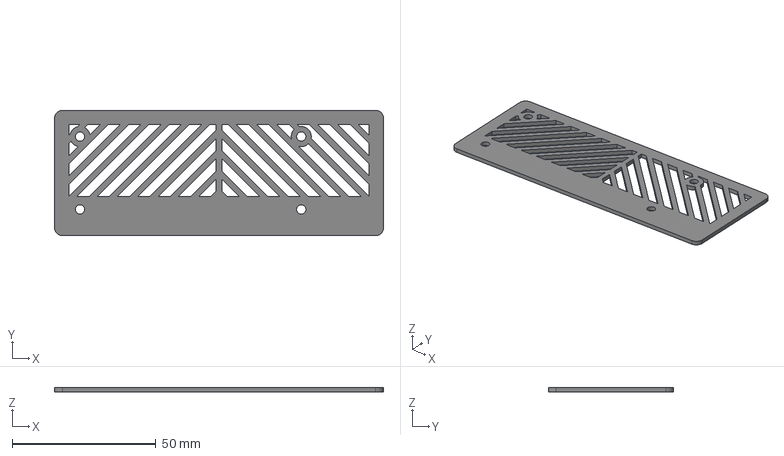
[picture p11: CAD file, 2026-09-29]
hardware/CAD/left-side-plate.step
114.5 x 43.6 x 1.63 mm
left-side-plate_silkscreen
left-side-plate_PCB

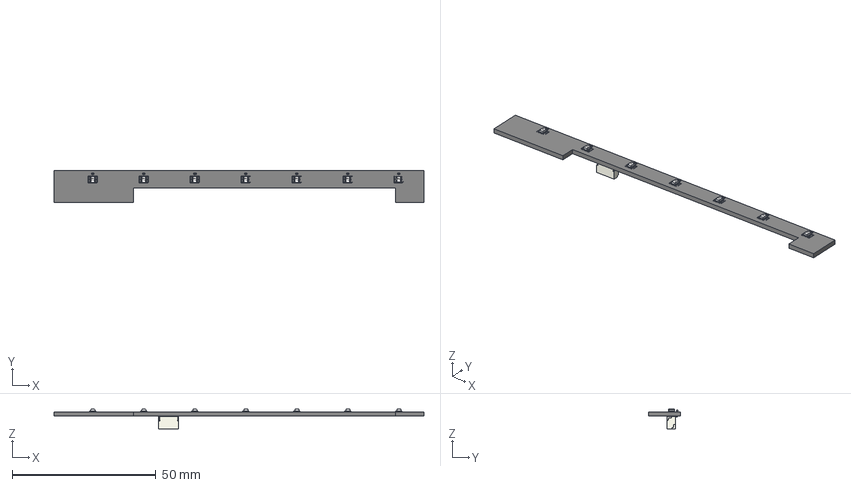
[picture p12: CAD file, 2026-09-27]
hardware/CAD/status-strip.step
128.8 x 11.0 x 6.85 mm
C_0402_1005Metric x 7
LED_WS2812_2020 v3 x 7
JST_SH_BM05B-SRSS-TB_1x05-1MP_P1.00mm_Vertical
kibot_0775n4pz_silkscreen x 2
kibot_0775n4pz_PCB

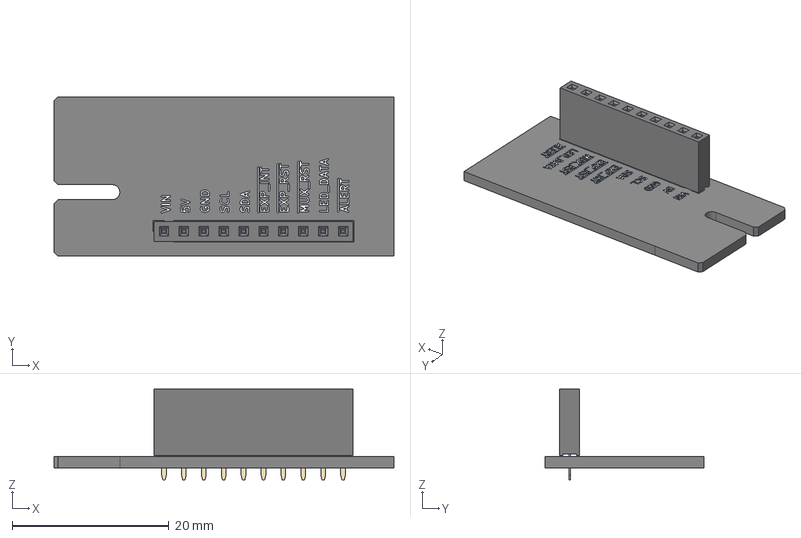
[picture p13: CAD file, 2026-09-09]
hardware/CAD/pcie-breakout.step
43.4 x 20.3 x 11.6 mm
PinSocket_1x10_P2.54mm_Vertical
kibot_1xwv2r1r_silkscreen
kibot_1xwv2r1r_PCB

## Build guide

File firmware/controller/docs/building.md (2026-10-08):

# Building the controller firmware

How to build the controller firmware for each board, run it without a backplane, and run the host-side tests. The source is in [`firmware/controller`](../).

## Building

Requires the [pico-sdk](https://github.com/raspberrypi/pico-sdk) (2.x) with
its `lib/btstack` (Wi-Fi setup) and `lib/mbedtls` (MQTT TLS) submodules
checked out, an `arm-none-eabi` toolchain, and Python 3 (BTstack's
`compile_gatt.py` turns `src/net/improv_profile.gatt` into a header at build
time).

```sh
export PICO_SDK_PATH=~/.pico-sdk/sdk/2.2.0   # or wherever the SDK lives
cmake -B build -G Ninja
ninja -C build
```

A new board takes `build/controller-factory.bin` over SWD, or
`partition_table.uf2` and `controller.uf2` over BOOTSEL: see
[First programming](flash-and-updates.md#first-programming). After that, updates go into the
inactive image slot.

The image carries the gen-3 blade firmware it programs blades with (see
[Blade firmware updates](flash-and-updates.md#blade-firmware-updates)): `-DBLADE_IMAGE=<path>`
names the `charger-module.bin` to bundle, and without it the build takes a
sibling `../charger-module/build/charger-module.bin` when one is there
(build `firmware/charger-module` first). A build with neither still starts
blades that hold a good image, but cannot program a blank one, and says so
at configure time.

## Boards

| `PICO_BOARD` | Board | Flash | Partition layout |
| --- | --- | --- | --- |
| `pwrman_controller_card` (default) | the production controller card, `hardware/controller` | 16 MB | `prod-16mb.json` |
| `pico2_w` | Pico 2 W on the pcie-breakout: a development stand-in until the card exists | 4 MB | `pico2w-4mb.json` |
| `wiznet_w6100_evb_pico2` | WIZnet W6100-EVB-Pico2 in the breakout's socket, no radio | 2 MB | none (runs unpartitioned) |

The pico-sdk knows the Pico 2 W; `boards/` carries the other two. The EVB's
header mostly exists to declare its 2 MB flash so the settings and
fault-log sectors land inside the chip. The card's header declares its
16 MB W25Q128, the RM2 radio on the Pico 2 W's CYW43 pins, and defines
`PWRMAN_CONTROLLER_CARD`, which switches `src/pins.h` to the card's
[GPIO map](internals.md#gpio-map) and the inverted reset drivers; the build picks the
16 MB partition layout for it.

```sh
cmake -B build-pico2w -G Ninja -DPICO_BOARD=pico2_w
ninja -C build-pico2w
```

Bench shortcut for the Pico 2 W carrier: `-DCARRIER_INTERNAL_PULLUPS=ON`
swaps the three 4.7 kΩ resistors the breakout needs on SDA, SCL and
ALERT# for the RP2350's own pad pull-ups (50–80 kΩ) and slows the bus to
100 kHz so their slow edges fit inside the clock's low period. Once a mux
channel is open, that blade segment's 4.7 kΩ pull-ups on the backplane
pass through the switch and stiffen the upstream bus too. It is a
one-or-two-blade bench build: at 100 kHz six powered blades' per-tick
reads no longer fit the 10 ms engine tick. Refused for the controller
card, which carries the resistors.

```sh
cmake -B build-pull -G Ninja -DPICO_BOARD=pico2_w -DCARRIER_INTERNAL_PULLUPS=ON
ninja -C build-pull
```

## Network options

| Option | Default | Effect |
| --- | --- | --- |
| `NET_WIFI` | ON | CYW43 WiFi + Improv Wi-Fi setup; needs a CYW43 board (`pico2_w`, the card) |
| `NET_ETH` | ON | W6100 wired Ethernet on SPI0 GP16–21, probed once at boot |

Both on is the production shape (RM2 radio + W6100). A Pico 2 W with nothing
on GP16–21 logs `eth: no W6100 answering` at boot and runs WiFi-only. For a
board with no radio, such as the W6100-EVB-Pico2, build a wired-only image
(no cyw43 or BTstack blobs, about 230 KB):

```sh
cmake -B build-eth -G Ninja -DPICO_BOARD=wiznet_w6100_evb_pico2 -DNET_WIFI=OFF
ninja -C build-eth
```

With 2 MB there is no room for the A/B partition layout, so the EVB runs the
image unpartitioned (`boot: slot raw`) and OTA is unavailable on it; flash it
over SWD or BOOTSEL. The W6100 needs time after reset: the driver waits
100 ms before the first register read, because the chip does not answer at
10 ms.

## Fake-blade mode (no backplane needed)

`-DFAKE_BLADES=ON` swaps the five I2C drivers for a simulated backplane
(`src/engine/sim/`) and drives it through a repeating 60-second demo script —
attaches, budget contention with priority shedding, an over-current fault and
recovery, blade insertion/removal, with gen-3 blades in ports 4 and 5 and
gen-2 ones elsewhere (a fake-blade build bundles no blade firmware: its
simulated gen-3 blades take the boot-option trip through their bootloader
and are started on what they hold). Everything above the driver seam (state
machine, budget arbiter, MQTT/HA, web UI, CLI) is the real code, so the whole
management plane can be exercised on a bare Pico 2 W:

```sh
cmake -B build-fake -G Ninja -DPICO_BOARD=pico2_w -DFAKE_BLADES=ON
ninja -C build-fake
```

The console's `sim` command drives the simulated backplane by hand, so the
fault paths — the fault log, the *Problem* sensor, events, auto-recovery,
charge-complete — can be exercised on a bare board instead of only in the
host tests. Run `sim pause` first: the demo script would otherwise
overwrite injected state within seconds. `sim` alone prints the list; on a
real-blade build the command says so and does nothing.

| Command | Effect |
| --- | --- |
| `sim pause` / `sim run` | stop the demo script; restart it from its baseline |
| `sim seat <n>` / `sim unseat <n>` | seat or pull a blade |
| `sim gen <n> 2\|3` | which blade generation the slot holds, set before seating it |
| `sim attach <n> <mV> <mA>` / `sim detach <n>` | attach a sink with that contract, or detach it |
| `sim load <n> <pct>` | measured draw as a percentage of the contract current; `sim load 3 1` with `charged 20000 1` shows a charge-complete within a minute |
| `sim fault <n> ocp` | an over-current trip: the INA226 on a gen-2 blade, the VBUS switch on a gen-3 one |
| `sim fault <n> otw1\|ntc1\|cc\|...\|clear` | MPQ4242 fault bits, sticky until cleared |
| `sim fault <n> ovp\|conv-ocp\|plug-hot\|pd\|...\|clear` | a gen-3 blade's faults, held as a condition that re-latches until cleared |
| `sim restart <n>` | a gen-3 blade's MCU restarts and loses its configuration |
| `sim temp <n> <conv> <plug>` / `sim temp <n> auto` | pin a gen-3 blade's thermometers in °C, or hand them back to the model that warms them with the load |
| `sim probe <n> ina\|mpq\|blade\|ok` | the next probes find a silent chip |
| `sim mux fail\|ok` / `sim expander fail\|ok` | bus-level failures the engine recovers from by resetting the mux and expander |

## Host-side tests

The engine core (state machine + budget arbiter) is hardware-free and runs
natively against the same simulated drivers, and so does everything else
with a seam under it (the settings store against a flash in RAM, the bus
monitor against an emulated ADC, the button, the UPS protocol):

```sh
cmake -S test -B test/build
cmake --build test/build
ctest --test-dir test/build --output-on-failure
```

The same run checks `docs/openapi.yaml` against the web server's routes and
fields (the `openapi` test; see
[API description](internals.md#api-description)). A change to the HTTP API
fails it until the description matches.

CI runs these on every push/PR touching the firmware.

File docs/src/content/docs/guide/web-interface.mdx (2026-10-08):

---
title: Web interface
description: Watch live power for every port, read the fault log, change settings, and back up or restore your configuration.
sidebar:
  order: 2
---

import { Aside } from '@astrojs/starlight/components';
import Screenshot from '../../../components/Screenshot.astro';
import overviewLight from '../../../assets/web-page/overview-light.png';
import overviewDark from '../../../assets/web-page/overview-dark.png';
import detailLight from '../../../assets/web-page/port-detail-light.png';
import detailDark from '../../../assets/web-page/port-detail-dark.png';

Every Power Manifold has its own web interface. Open `http://pwrman.local/`, or
`http://<name>.local/` if you changed the device name. If `.local` names
don't work on your network, use the IP address your router gave it.

The page works without Home Assistant and without internet access.

<Screenshot
	light={overviewLight}
	dark={overviewDark}
	alt="The top of the web interface: the front panel drawing with six port lights, a status line, the power budget bar and the first port cards with power graphs"
	caption="The top of the page, with five ports delivering power and port 6 ready for a device."
/>

## At the top

The page refreshes every second. At the top:

- **The front panel.** A drawing of the chassis front shows each port's
  light in the color it has on the real chassis, blinking or breathing the
  same way, plus the chassis light. See
  [Front panel and lights](/guide/front-panel/). Click a port
  to open its graphs.
- **A status line:** the input voltage, the fan, the energy delivered since
  the controller started, and the firmware version.
- **A red line**, only when something needs attention. It says what. See
  [Troubleshooting](/guide/troubleshooting/).
- **The power budget.** How much power the chassis is drawing now, how much
  is set aside for the ports, and how much is free. The bar below splits the
  drawn power by port, in each port's color, and hatches the part that is
  set aside but not in use. See
  [Sharing power](/guide/sharing-power/).

The page follows your device's light or dark setting. The **Theme** button
at the top right switches between automatic, light and dark. Your choice is
remembered in that browser only.

## The port cards

Each port has a card. A port that is delivering power shows:

- the power the device is drawing right now, in large type;
- the current and voltage, and the power set aside for the port (its
  *contract*), with a bar showing how much of it is in use;
- a graph of the last three minutes;
- the energy delivered since the controller last started, and the blade's
  converter and plug temperatures.

A port that isn't delivering says why: nothing plugged in, switched off,
no blade in the slot, or a fault. A port with nothing plugged in still holds
15 W for the next device, and its card says so.

A port whose [blade firmware update](/guide/updates/#blade-firmware) is
waiting says so at the top of its card, with how to let it run.

Click a card to see graphs of its power, current and voltage, with the
port's settings and temperatures. The graphs start when you open the page
and cover the last ten minutes. Home Assistant keeps the long-term history.

<Screenshot
	light={detailLight}
	dark={detailDark}
	alt="Port 3, a laptop, opened below its card: power, current and voltage graphs over three minutes, then its reserved power, current limit, voltage cap, power-up state, temperatures and energy"
	caption="A port opened to its graphs and settings."
/>

The **Switch off** button at the bottom of each card turns the port off, and
**Switch on** turns it back on. Switching off asks you to confirm on the card
first, because the device plugged into it loses power. Both need your API
token: unlock **Settings** once and the buttons work for as long as the tab
is open. A port you turn off stays off
until you turn it on again. After a restart it follows its
[power-up setting](/guide/port-settings/#on-or-off-at-power-up).

## Fault log and console log

The **Fault log** tab lists the most recent faults, newest first, with the
time and how much power the port was drawing at that moment. It also records each
restart and why it happened. It keeps about 256 entries.

The **Console** tab shows the controller's recent messages. It needs your API
token because it names your networks and servers.

Type a command in the box under the messages and press Enter to run it, or
paste several lines and run them together; Shift+Enter starts a new line,
and the up and down arrows bring back earlier commands. `help` lists them.
The reply appears under the messages. Passwords and the token show as
`********` there and in the log. A few commands are refused there:
`token`, `defaults`, `bootsel`, updates that are unsigned or older than the
running firmware, the input voltage trim `vin cal`, and the bench tools
`stack`, `i2c`, `sim` and `button`.

## Settings

Open the **Settings** tab below the port cards. Its first row, which shows
without the token, is about the unit itself: the controller firmware and the
slot it runs from, the blade firmware, how long it has been running, why it
last started, whether the lights are dimmed, whether an update is out, and
the MQTT broker connection if one is set up. **Check for updates** asks for
the newest release now, and **Install** appears when one is available.
While a release waits to install automatically, **Postpone 7 days** and
**Skip this version** appear too (see [Updates](/guide/updates/)). These
buttons need the token. Enter your API token to
unlock the rest. The settings are grouped into Device, Network, MQTT, Power and
fan, Status lights, and a Ports table with one row per port. Change what you need and press **Save**.

A new controller has no token yet. During
[first-time setup](/setup/first-time-setup/) the tab opens
by itself and asks you to choose one. Until you do, nothing can be changed
from the network, and the tab says what to do if setup has closed.

Most changes apply at once. The device name, Wi-Fi, MQTT broker and
addressing apply after you press **Reboot**. A reboot does not interrupt
power to any port.

The settings and the pages that describe them:

- **Device name** and **MQTT broker**: see
  [Home Assistant](/guide/home-assistant/).
- **Chassis budget** and **fan**: see
  [Sharing power](/guide/sharing-power/).
- **Port names, current limits, voltage caps, state at power-up, switch off
  once charged, sleep timer**: see
  [Port settings](/guide/port-settings/).
- **Status light brightness, night window, idle dimming, UTC offset**: see
  [Front panel and lights](/guide/front-panel/#brightness-and-dimming).
- **Addressing, DNS, time server, syslog, MQTT security, update source**:
  see [Network settings](/integrations/network/).
- **HTTPS** and **Install certificate…**: see [HTTPS](/integrations/https/).
  With HTTPS on, the page is at `https://` and the name on the
  certificate, and asks for the API token once more there.
- **Automatic updates**: see
  [Firmware updates](/guide/updates/#automatic-updates).

## Backing up your settings

At the bottom of **Settings**:

- **Export** downloads every setting as a JSON file. Your Wi-Fi password,
  MQTT password and API token are left out unless you tick the box to
  include them. The input voltage calibration is never included, because
  it is specific to the controller card.
  Nor are the HTTPS certificate and the HTTPS setting.
- **Import…** loads a file you exported earlier.

If the file leaves out the passwords, importing it keeps the passwords
already on the controller. You can import a file exported from an older or
newer firmware: settings it doesn't recognize are skipped. If any value in
the file is invalid, nothing is imported.

<Aside type="tip">
Export your settings before a factory reset or before moving the controller
card to another chassis.
</Aside>

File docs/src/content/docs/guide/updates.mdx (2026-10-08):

---
title: Firmware updates
description: How Power Manifold finds new firmware, how to install it, and what happens to your ports while it updates.
sidebar:
  order: 6
---

import { Aside, Steps } from '@astrojs/starlight/components';
import Flow from '../../../components/Flow.astro';
import UpdateTimeline from '../../../components/UpdateTimeline.astro';

Power Manifold checks for new firmware once a day and installs new
releases by itself. You can also install a release yourself as soon as it
is out, put automatic installs off, or turn them off.

## Automatic updates

When the controller finds a new release, it waits a random 1 to 7 days and
then installs it between 03:00 and 05:00 local time. The wait spreads each
release over a week, so a release with a problem can be withdrawn before it
reaches most controllers. Set the local time with **UTC offset** in the web
interface's **Settings**. Until the controller has the time from its time
server, it installs a release once the wait is over, at any hour.

**Your ports stay on** during an automatic update, the same as during one
you start. See [What happens during an update](#what-happens-during-an-update).

While a release is waiting, the web interface's **Settings** shows when it
will install, with two buttons:

- **Postpone 7 days** holds back automatic installs for a week. Press it
  again to postpone further.
- **Skip this version** stops this release from installing by itself. The
  next release installs as usual.

Home Assistant has the same two buttons, **Postpone update 7 days** and
**Skip this update**. **Install** works in either case. The **Skip** on
Home Assistant's update card only hides the update in Home Assistant; see
[Skipping an update](/guide/home-assistant/#skipping-an-update).

If an update fails its trial and the controller goes back to the previous
firmware, that release is not installed automatically again. You can still
install it yourself.

### Turning automatic updates off

Set **Automatic updates** to **Off** in the web interface's **Settings**, or
turn off the **Automatic updates** switch in Home Assistant. The controller
still checks once a day and shows new releases, and installs one only when
you start it. The setting is `update_auto` in the
[HTTP API](/integrations/http-api/#settings-keys), and `update auto off`
followed by `save` at the console.

## Installing an update yourself

When a new release is out, Home Assistant's **Firmware update** entity
shows *update available*. Press **Install**.

The web interface shows it too, on the status line and in the first row of
**Settings**. Press **Install** there. **Check for updates** asks right
away instead of waiting for the daily check.

You can also install with the
[HTTP API](/integrations/http-api/#installing-an-update).

## What happens during an update

<Steps>

1. **The new firmware downloads** next to the one that's running. The
   running firmware is kept.

2. **The controller restarts** into the new firmware. **Your ports stay
   on.** Devices keep their power while the controller restarts.

3. **The new firmware is on trial.** It must run properly for ten seconds
   and connect to the network. Then it becomes the installed version.

4. **If it doesn't,** the controller goes back to the previous firmware by
   itself, with your settings as they were. If it fails within ten minutes
   or restarts unexpectedly, it reverts too.

</Steps>

While the controller restarts, the blades keep running with the limits they
had and their own protection. Power sharing and fault handling resume once
the controller is back, after a few seconds. Devices that are plugged in
keep the power they had: the controller sends them no new offer unless the
budget no longer covers them.

<UpdateTimeline />

## Blade firmware

The blades have their own firmware, and the controller carries the version
that goes with it. After a controller update the controller brings each
blade up to date by itself, at a moment when its port is not in use:

- when the chassis is switched on, or the port is switched on, before the
  port powers up;
- when its port has had nothing plugged in for ten seconds;
- when the device plugged into it is switched off. The controller knows a
  device is off when it draws less than the
  [**Charged below**](/guide/port-settings/#switching-off-when-charged)
  threshold for the **…for** time: 500 mW for 10 minutes, by default.

Updating a blade takes a few seconds. Its light is off while it happens, and
its state shows `updating` with a percentage. A device that was plugged in
reconnects once the port comes back.

A port powering a device that is on, such as a running Raspberry Pi, is not
interrupted. Its update waits until the device is unplugged or switched off,
or until the port is switched off and on again. If **Charged below** is set
to 0, the controller can't tell that a device is off, and only unplugging or
switching the port off and on lets the update run.

While an update waits, Power Manifold makes it hard to miss:

- the port's light flashes amber briefly every 3 seconds;
- the web interface's status line says *blade update waiting* with the
  port's name, and the port's card says how to let the update run;
- in Home Assistant, the **Problem** sensor turns on, and a **Blade
  firmware** update appears under **Settings** › **Updates**. Its
  **Install** button updates the waiting blades at once. Their devices lose
  power for a few seconds, so shut them down first.

Blades always take the firmware the controller carries. This can't be
turned off, because a controller and blades on different versions may not
work together.

## Security

Every release is signed. The controller only installs firmware that is
signed by this project, built for this hardware, and not older than what
it is running. Updates come from `fw.powermanifold.io`, which serves the
project's GitHub releases.

Updates are downloaded over HTTP, not HTTPS. The controller refuses an
update address that starts with `https://`, so a server of your own that
hosts the files must serve them over plain HTTP. The signature check is
what protects the download.

<Flow
	nodes={[
		{ title: 'GitHub releases', detail: 'Signed by the project' },
		{ title: 'fw.powermanifold.io', detail: 'Passes them on' },
		{ title: 'Power Manifold', detail: 'Checks daily, installs automatically or when you say', highlight: true },
	]}
	links={[{ label: 'HTTPS' }, { label: ['HTTP', 'signature checked'] }]}
/>

<Aside type="note">
To stop the daily check, clear **Update source** in the web interface's
**Settings**. Nothing then installs automatically. You can still install an
update file yourself with the HTTP API.
</Aside>

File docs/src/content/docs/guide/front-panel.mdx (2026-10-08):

---
title: Front panel and lights
description: Port numbering, what each port light color means, and what the front-panel button does.
sidebar:
  order: 1
---

import { Aside } from '@astrojs/starlight/components';
import FrontPanel from '../../../components/FrontPanel.astro';

## Ports

<FrontPanel />

Facing the front, the Ethernet port and the button are on the far left. The
six USB-C ports follow, numbered **1 to 6 from left to right**. Each port
has a status light above its number. The chassis light, to the left of
port 1, shows the status of the controller.

Each light is mounted on the chassis at its slot, so it also shows when a
slot is empty.

## Port lights

<FrontPanel
	lights={['green dim', 'blue', 'green', 'white', 'blue pulse', 'red fast', 'amber dim']}
	title="Front panel with ports showing different states"
	caption="For example: port 1 powering a laptop, port 2 a phone, port 3 idle, port 4 turned down for the budget, port 5 faulted and no port installed at 6."
/>

| Light | Meaning |
| --- | --- |
| <span class="led" style="--led:#3b82f6"></span>Blue | Powering a device at 12 V or more, such as a monitor, a game console or a laptop. |
| <span class="led" style="--led:#22c55e"></span>Green | Powering a device at 5 or 9 V, such as a phone or a Raspberry Pi. |
| <span class="led" style="--led:#e8e8e8"></span>White | Nothing to deliver: no device is plugged in, or the device has finished charging and is only trickling. |
| <span class="led blink" style="--led:#22d3ee"></span>Cyan, blinking | The blade is starting up. |
| <span class="led pulse" style="--led:#3b82f6"></span>Slow pulse (blue or green) | Powering a device, but turned down because the chassis is at its power budget. See [Sharing power](/guide/sharing-power/). |
| <span class="led blink" style="--led:#ef4444"></span>Red, fast blink | The port shut itself off because of a fault. It tries again after 5 seconds. See [Troubleshooting](/guide/troubleshooting/#a-port-blinks-red). |
| <span class="led flag" style="--led:#22c55e"></span>Short amber flash every 3 seconds | The blade's firmware update is waiting for the device to be unplugged or switched off. The light shows the port's usual color in between. See [Blade firmware](/guide/updates/#blade-firmware). |
| <span class="led" style="--led:#f59e0b;--lvl:.4"></span>Dim amber | No port installed in this position. |
| Off | The port is switched off. |

## The chassis light

The chassis light is dim green during normal operation. If more than one of
these applies, it shows the first in this table:

| Light | Meaning |
| --- | --- |
| <span class="led" style="--led:#22c55e;--lvl:.4"></span>Dim green | Normal operation. |
| <span class="led pulse" style="--led:#3b82f6;animation-duration:2s"></span>Blue, breathing | The controller is waiting for [Wi-Fi setup](/setup/wifi-provisioning/). |
| <span class="led pulse" style="--led:#f59e0b;animation-duration:2s"></span>Amber, breathing | The controller has no API token yet and its settings are open for [first-time setup](/setup/first-time-setup/). It stops when you save a token. |
| <span class="led pulse" style="--led:#ef4444;animation-duration:2s"></span>Red, breathing | The controller has no network connection. See [Troubleshooting](/guide/troubleshooting/#no-network). |
| <span class="led blink" style="--led:#ef4444"></span>Red, fast blink | The input voltage from your power supply is out of range. See [Troubleshooting](/guide/troubleshooting/#bus-voltage-out-of-range). |

## Lights across the whole row

Some patterns run across all seven lights.

**A sweep from left to right** at power-up, starting with the chassis
light. It also confirms that every light is working.

<FrontPanel
	sequence="boot"
	lights={['green dim', 'white', 'white', 'white', 'white', 'white', 'white']}
	title="Power-up sweep across the front panel lights"
/>

**Every other light flashing blue**: someone pressed **Identify** during
Wi-Fi setup to find this unit. It lasts ten seconds.

<FrontPanel sequence="identify" title="Identify pattern: every other light flashing blue" />

## Brightness and dimming

You can set the light brightness in the web interface's **Settings** or in Home
Assistant. At 0 the lights are off, except that a faulted port, or the
chassis light during an input voltage fault, still blinks dimly.

Two schedules can dim the lights to a low level. The default low level is
just visible in a dark room:

- **Night window**: dim between two times of day, for example 22:00 to
  07:00. This needs the clock, so set your UTC offset in **Settings**. The
  offset does not follow daylight saving time, so change it when the clocks
  change.
- **Idle dimming**: dim after a period with nothing plugged in, unplugged or
  faulted. Any change at a port brings the lights back to full.

A short press of the button brings the lights to full brightness for 30
seconds.

## The button

The button on the controller card does three things, depending on how long
you hold it:

| Press | What happens |
| --- | --- |
| **Short press** (under 3 seconds) | Flashes all lights white, then shows them at full brightness for 30 seconds. Useful when the lights are dimmed or off. On a controller with no API token yet, it also gives you another hour to [set one over Ethernet](/setup/first-time-setup/#steps). |
| **Hold 3 seconds**, then let go | Opens Wi-Fi setup for ten minutes so you can [change Wi-Fi](/setup/wifi-provisioning/#changing-wi-fi-later). |
| **Hold 10 seconds** | **Factory reset.** Erases all settings and the fault log, then restarts. |

<FrontPanel
	sequence="hold"
	lights={['green dim', 'blue', 'green', 'white', 'white', 'white', 'white']}
	title="Holding the button down to a factory reset"
/>

From 3 seconds on, the lights fill up in blue from left to right, one
light at a time, as a warning. If you let go while they are filling, you
get the Wi-Fi setup window and nothing is erased. When all seven are lit they
turn red, and the reset happens without waiting for you to let go.

<Aside type="caution">
A factory reset erases your Wi-Fi details, API token, port names and every
other setting. You'll need to do
[first-time setup](/setup/first-time-setup/) again. You can
[export your settings](/guide/web-interface/#backing-up-your-settings)
first.
</Aside>

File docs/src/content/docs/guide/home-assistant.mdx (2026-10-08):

---
title: Home Assistant
description: Connect Power Manifold to Home Assistant through MQTT. Every port appears automatically with its power, a switch and its settings.
sidebar:
  order: 5
---

import { Aside, Steps } from '@astrojs/starlight/components';
import Flow from '../../../components/Flow.astro';
import Screenshot from '../../../components/Screenshot.astro';
import deviceShot from '../../../assets/home-assistant/device.png';

Power Manifold connects to Home Assistant through an MQTT broker. Once
connected, it appears as one device with every port and setting. No YAML
configuration is required.

## Connect it

<Flow
	nodes={[
		{ title: 'Power Manifold', detail: 'Reports every port', highlight: true },
		{ title: 'MQTT broker', detail: 'Mosquitto add-on or any other' },
		{ title: 'Home Assistant', detail: 'One device, every port' },
	]}
	links={[{ label: ['MQTT', '1883, or 8883 with TLS'], dir: 'both' }, { label: 'MQTT', dir: 'both' }]}
/>

<Steps>

1. **Have an MQTT broker.** If you don't have one, install the **Mosquitto
   broker** add-on in Home Assistant, then add the **MQTT** integration.
   Create a Home Assistant user for Power Manifold to log in with.

2. **Point Power Manifold at it.** In the web interface's **Settings**, fill in
   the **MQTT broker** (your Home Assistant's address), the port (usually
   1883) and the user and password. Press **Save**, then **Reboot**.

3. **Find the device.** In Home Assistant, go to **Settings → Devices &
   services → MQTT**. Power Manifold appears as a device named after it.

</Steps>

<Screenshot
	light={deviceShot}
	scale={1.5}
	alt="The Power Manifold device page in Home Assistant: device info showing firmware 0.13.0, and a Controls card with a switch for each port and the fan mode."
	caption="The device page. Ports you have named, like Desk phone, appear under their names."
/>

If you use more than one Power Manifold, give each a different device name
before connecting it.

To encrypt the connection to the broker, see
[MQTT security](/integrations/network/#mqtt-security).

## What you get

### For each port

Entities are named after the port, so renaming a port renames them. Their
entity IDs don't change.

| Entity | What it does |
| --- | --- |
| **Switch** | Turns the port on or off. |
| **Power**, **voltage**, **current** | Live readings, once a second. |
| **Energy** | Energy delivered since the controller started. Works with the Energy dashboard. |
| **State** | `idle`, `active`, `throttled`, `fault` and so on. Its attributes include the most recent fault and when it happened. |
| **Charging** | On while a device is plugged in and still charging. |
| **Converter temperature**, **plug temperature** | Blade temperatures. They read *unknown* while the port is off. |
| **Priority**, **current limit**, **voltage cap**, **power-up state**, **switch off when charged**, **sleep timer** | The [port settings](/guide/port-settings/). |
| **Hard reset** | Briefly cuts the port so the device starts its connection over. |
| **Re-announce** | Sends the device the port's offer again. |
| **Events** | Fires on plug-in, unplug, charged, faults and more. See below. |

### For the whole chassis

| Entity | What it does |
| --- | --- |
| **Total power**, **budget headroom**, **total energy** | How much is being used and how much room is left. |
| **Power budget** | The [chassis budget](/guide/sharing-power/). |
| **Fan** | `auto`, `on` or `off`. |
| **LED brightness** | Port light brightness. |
| **Charged below**, **charged after** | When a device counts as [charged](/guide/port-settings/#switching-off-when-charged). |
| **Problem** | On when something needs attention. Its `detail` attribute says what. |
| **Bus voltage** | The input voltage from your power supply. |
| **Open Wi-Fi setup** | Opens Wi-Fi setup for ten minutes to [change Wi-Fi](/setup/wifi-provisioning/#changing-wi-fi-later). |
| **Firmware update** | Shows when a new release is out. Press **Install** to update. See [Updates](/guide/updates/). |
| **Blade firmware** | Shows an update while a blade's firmware update waits for its device to be unplugged or switched off. **Install** updates those blades now, and their devices lose power for a few seconds. See [Blade firmware](/guide/updates/#blade-firmware). |
| **Automatic updates** | On: new releases install by themselves. See [Automatic updates](/guide/updates/#automatic-updates). |
| **Postpone update 7 days**, **Skip this update** | Hold back automatic installs for a week, or for the release now offered. The card's own **Skip** does not reach the controller; see [Skipping an update](#skipping-an-update). |
| **UPS** sensors | Only with a [UPS power supply](/integrations/ups/) connected, which is unofficial. |

## Skipping an update

The **Firmware update** card has its own **Skip** button. That Skip stays
inside Home Assistant: it hides the update, but the controller is not told,
and still [installs the release automatically](/guide/updates/#automatic-updates)
a few days later. To stop a release from installing, press the
controller's **Skip this update** button instead.

To make the card's **Skip** do the same, add this automation. It presses
**Skip this update** whenever a version is skipped on the card. Replace
`pwrman` with your device name.

```yaml
alias: Pass Power Manifold update skips to the controller
triggers:
  - trigger: state
    entity_id: update.pwrman_firmware
    attribute: skipped_version
conditions:
  - condition: template
    value_template: "{{ trigger.to_state.attributes.skipped_version is not none }}"
actions:
  - action: button.press
    target:
      entity_id: button.pwrman_skip_this_update
```

**Clear skipped** on the card does not undo the controller's skip. The
skipped release can still be installed with **Install**, and the next
release installs automatically as usual.

## Automations

Each port has an **events** entity for use as an automation trigger.
Its event types are:

| Event | When |
| --- | --- |
| `attached` / `detached` | A device is plugged in or unplugged. |
| `charged` / `charging` | A device finished charging, or started again. |
| `enabled` / `disabled` | The port was switched on or off. |
| `auto_off` | *Switch off once charged* or the sleep timer turned the port off. |
| `throttled` / `restored` | The port was turned down for the budget, or got its power back. |
| `fault` | The port shut itself off. The `text` attribute says why. |
| `inserted` / `removed` / `ready` | The controller found a port, lost contact with it, or the port finished starting up. |
| `contract` | The device switched to a different voltage or current. |
| `probe_failed` | A blade didn't respond while starting up. |
| `pd_reset` | The port or the device reset the USB-C connection, which briefly cuts the device's power. The `text` attribute says which side did it and, if the port's offer had changed since the device was plugged in, how long before. |
| `updated` | The blade's firmware was updated. |

**Example: get a notification when a port faults.**

```yaml
triggers:
  - trigger: state
    entity_id: event.desk_phone_events
    not_from: unavailable
conditions:
  - condition: state
    entity_id: event.desk_phone_events
    attribute: event_type
    state: fault
actions:
  - action: notify.notify
    data:
      message: "Desk phone port: {{ trigger.to_state.attributes.text }}"
```

**Example: power-cycle an unresponsive Raspberry Pi** by turning its port's
switch off, waiting ten seconds, and turning it back on. This uses the
port's **Switch** entity, so a script or a dashboard button can do it.

<Aside type="tip">
For a phone or tablet that stays plugged into a port, turn on **switch off
when charged** and use a time-based automation to turn the port back on in
the morning.
</Aside>

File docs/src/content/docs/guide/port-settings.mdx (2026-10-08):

---
title: Port settings
description: Name your ports, choose which come on at power-up, limit voltage and current, and switch ports off when a device has finished charging.
sidebar:
  order: 3
---

import { Aside } from '@astrojs/starlight/components';
import PortOffer from '../../../components/PortOffer.astro';
import ChargeTimeline from '../../../components/ChargeTimeline.astro';

Each port has its own settings. You can change them in the web interface's
**Settings**, in [Home Assistant](/guide/home-assistant/), over
[MQTT](/integrations/mqtt/) or with the
[HTTP API](/integrations/http-api/). Changes apply at once,
even to a device that is already plugged in.

## Name

Give each port a name, such as `pi-cluster-1` or `Desk phone`, up to 23
characters. The name shows in the web interface and in Home Assistant, where
the entities are renamed to match: *Port 3 power* becomes *Desk phone
power*. Renaming doesn't change any entity IDs, so your automations keep
working.

Leave the name blank to go back to `Port 1`, `Port 2` and so on.

## On or off at power-up

Choose what each port does when Power Manifold is switched on, for example
after a power cut:

- **on** (the default): the port powers up.
- **off**: the port stays off until you switch it on.
- **last**: the port comes back the way you last left it.

When the chassis powers up, the ports come on one at a time, a quarter of a
second apart, in [priority](/guide/sharing-power/#priorities)
order. This stops six devices from starting all at once.

## Voltage cap

The voltage cap is the highest voltage a port offers. Choose 5, 9, 12, 15
or 20 V. The default is 20 V, which offers everything.

The cap applies to PPS (Programmable Power Supply) as well. A port offers
two PPS ranges, 3.3–11 V and 3.3–21 V, and offers a range only when all of
it fits under the cap:

| Cap | PPS ranges offered |
|---|---|
| 5 V or 9 V | none |
| 12 V or 15 V | 3.3–11 V |
| 20 V | 3.3–11 V and 3.3–21 V |

The 20 V cap is the one exception: it still offers the 3.3–21 V range,
which goes slightly above 20 V.

Use a lower cap to protect a device that shouldn't get a high voltage. For
example:

- **5 V** for a device with a USB-C trigger board or adapter that you don't
  fully trust.
- **9 V** to limit the charging power of a phone.

## Current limit

The current limit is the most current a port offers at any voltage, from
500 to 5000 mA. Power scales with the voltage the device picks: a 3000 mA
limit means 15 W at 5 V and 60 W at 20 V.

The limit only sets what the port offers. A device that requests more
receives the limited amount and is not switched off.

Try a cap, a limit and a cable to see what a port offers:

<PortOffer />

<Aside type="note" title="Cables limit current too">
Above 3 A the cable must have a 5 A e-marker chip. The port checks the cable
and offers 5 A only on a cable that can carry it. With an ordinary cable a
port stops at 3 A (60 W at 20 V), whatever the limit says.
</Aside>

## Switching off when charged

The controller decides a device has finished charging when it draws less
than **500 mW** for **10 minutes**. The port light then turns white, as if
nothing were plugged in, and the port shows *charged*. If the device starts
drawing again for that long, it counts as charging again.

Both numbers can be changed in **Settings**, as **Charged below** and
**…for**. To turn this off, set the power threshold to 0: no device is ever
marked charged, and **Switch off once charged** never turns a port off.

The same threshold tells the controller that a device has been switched
off, which lets a waiting [blade firmware update](/guide/updates/#blade-firmware)
run.

Two per-port options build on this:

- **Switch off once charged** turns the port off as soon as the device is
  charged. Use it to stop phones and tablets from staying at 100 %
  overnight.
- **Sleep timer** turns the port off a set number of minutes after you plug
  a device in, whether it has finished charging or not, up to 24 hours.

<ChargeTimeline />

When either one switches a port off, it stays off until you switch it on
again. A port set to **last** at power-up remembers that it was off.

<Aside type="tip">
**Switch off once charged** and the sleep timer are meant for devices with a
battery. Leave them off on ports that power a Raspberry Pi or another
computer that doesn't expect to abruptly lose power.
</Aside>

## Priority

Each port also has a priority, which decides which ports are turned down
first when devices ask for more power than the supply can give. A port with
priority 0 is never turned down to make room for another port, which suits
devices that could be harmed by potential power loss during renegotiation.
See [Sharing power between ports](/guide/sharing-power/).

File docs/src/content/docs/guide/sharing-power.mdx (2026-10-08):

---
title: Sharing power between ports
description: How the power budget and port priorities decide which devices get full power when the supply can't cover everyone.
sidebar:
  order: 4
---

import PowerSharing from '../../../components/PowerSharing.astro';

Six ports at 100 W would need a 600 W supply. Most setups never draw that
much at once, so Power Manifold can run from a smaller supply and divide its
power between the ports. You tell it how much power the supply has (the **budget**) and which
ports matter most (their **priority**).

## The budget

Set the **Chassis budget** in the web interface's **Settings** or in Home
Assistant. Use your power supply's rating in watts, or a little less. The
default is 360 W.

When a device plugs in, it agrees on a voltage and current with its port,
for example 20 V at 3 A. Power Manifold sets that much power aside, 60 W in
this example, even if the device draws less at the moment. Laptops and other
devices can jump to their full power at any time, so setting aside the full
amount is what keeps the supply from being overloaded.

A port with a blade but nothing plugged in sets aside 15 W, enough for a
device to plug in and start at 5 V.

The web interface shows both numbers on each port's card: the large figure is
what the device uses right now, and the contract under it is what is set
aside for it. The budget bar at the top adds them up for the whole chassis.

## When there isn't enough

If a newly plugged-in device would take the total over the budget, Power
Manifold makes room:

1. It turns down lower-priority ports, starting with the lowest. It never
   takes a port below 15 W, and never turns down a port with the same or a
   higher priority than the new device.
2. If that isn't enough, it gives the new device whatever is left.

A port that has been turned down keeps powering its device, only with less
power. Its light pulses slowly, and its state shows `throttled`. The
device is sent a new, smaller offer and switches to it. Some devices may
briefly lose power while they renegotiate: if a device doesn't answer the
new offer quickly enough, the USB Power Delivery standard requires the port
to reset the connection, which cuts its power for a moment. For devices
that could be harmed by that, such as a computer that must not lose power
while it runs, give the port [priority 0](#priorities): no other port can
then turn it down.

When power frees up, for example when another device is unplugged or a
port with [switch off when charged](/guide/port-settings/#switching-off-when-charged)
turns itself off, the turned-down ports get it back, highest priority
first. A device that has finished charging but stays plugged in keeps its
share, because it can start drawing again at any time.

<PowerSharing />

## Priorities

Each port has a priority from 0 to 255, where **0 is the most important**.
By default a port's priority is its port number, so port 1 is the most
important and port 6 the least.

Ports with the same priority never take power from each other. The one
that plugged in first keeps what it has.

Set priorities in Home Assistant (a number for each port), over
[MQTT](/integrations/mqtt/) or with the
[HTTP API](/integrations/http-api/).

**Example:** a 150 W supply powers four Raspberry Pi 5s on ports 1 to 4,
which take 25 W each, and a 100 W laptop on port 6. Give the Pis priority 0
so they always get what they ask for, and leave the laptop at 6. The Pis
take 100 W of the budget, so the laptop is offered the rest and charges more
slowly. If a Pi is unplugged, the laptop gets its share. Because the Pis
have priority 0, no other port can turn them down while they run.

## When the input voltage drops

If the supply voltage falls below 20 V, every port is limited to 3 A (60 W
at most) until the voltage has been above 20.5 V for 30 seconds. Devices are offered less, but nothing is switched
off. This is a safety limit and applies to every port, priority 0
included. Use a supply whose voltage stays well above 20 V under load. While this is happening the web interface and Home Assistant show a
problem saying the ports are capped.

If you see this often, your supply is too small for your devices, or its
cable is too thin. Lower the budget or use a bigger supply. See
[Troubleshooting](/guide/troubleshooting/#ports-capped-at-3-a).

## The fan

The fan switches on automatically under any of these conditions:

- when the total power reaches 80 W, staying on until it falls to 60 W;
- while any port delivers more than 3 A;
- while any blade's converter is at 65 °C or hotter, or any USB-C
  receptacle is at 55 °C or hotter, staying on until every converter is
  below 55 °C and every receptacle below 45 °C.

You can change the first two rules in **Settings**, or force the fan on or
off from the web interface or Home Assistant. The temperature rule can't be
changed or turned off: a fan forced off still runs while a blade is hot.

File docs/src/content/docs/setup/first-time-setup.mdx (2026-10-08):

---
title: First-time setup
description: Connect a power supply, get Power Manifold on your network over Ethernet or Wi-Fi, and choose an API token.
sidebar:
  order: 1
---

import { Aside, Steps } from '@astrojs/starlight/components';
import SidePanel from '../../../components/SidePanel.astro';
import SetupRoutes from '../../../components/SetupRoutes.astro';

Setup takes about ten minutes. You'll connect power, get the controller onto
your network over Ethernet or Wi-Fi, and choose a password for its settings.
You can add Home Assistant later.

## What you need

- **A 24 V DC power supply** with an XT60 lead. Power Manifold is rated for
  24 V +20 %/−15 %. Choose its size by adding up the ratings of the chargers
  your devices would otherwise use. A laptop with a 65 W charger counts as
  65 W, even when it draws less.
  [Sharing power](/guide/sharing-power/#the-budget) explains why. The
  default power budget is 360 W (15 A at 24 V). If your
  supply is smaller, you'll lower the budget to match in step 5 below.
- **USB-C cables.** An ordinary cable carries up to 3 A (60 W). For more
  than 60 W at 20 V a device needs a 5 A cable with an e-marker chip, which
  is usually sold as a "100 W" or "240 W" cable.
- **A way onto your network.** Either an Ethernet cable from the controller
  card to your router, or a phone or computer near the chassis for Wi-Fi
  setup: Chrome or Edge on a desktop or Android device, or the Home
  Assistant app on an iPhone or iPad.

<Aside type="caution">
Connect the XT60 lead before you switch the supply on, and switch the
supply off before you unplug it.
</Aside>

<Aside type="note" title="Nothing can be changed until you set a token">
A new controller refuses every change that arrives over the network until
it has an API token. Its settings open only as described in step 2, and the chassis light, left
of port 1, breathes amber for as long as they are open. Saving a token
closes them and stops the light.
</Aside>

## Steps

There are two ways onto your network. Both end with saving an API token:

<SetupRoutes />

<Steps>

1. **Connect power.** Plug the power supply's XT60 lead into the socket on
   the right side of the chassis, seen from the front. The plug only fits
   one way round. Then switch the supply on. The fan exhausts through the
   same side. Keep that side clear.

   <SidePanel />

   The port lights sweep from left to right, then each port glows white,
   which means it is ready and waiting for a device. Ports are numbered 1
   to 6 from left to right when you face the front panel.

2. **Get it on your network.** Use whichever you have:

   - **Ethernet.** Plug a cable from the controller card's port into your
     router. The controller gets an address by itself. For the first hour
     after power-up, its settings are open to anyone on your network. To
     get another hour, switch the supply off and on again, or press the
     button on the controller card once.
   - **Wi-Fi.** A new controller waits for Wi-Fi setup until it
     has Wi-Fi details. Follow
     [Wi-Fi setup](/setup/wifi-provisioning/), either from
     that page in your browser or with the Home Assistant app. While it
     waits, the chassis light breathes blue. When Wi-Fi setup finishes, its
     settings are open to anyone on your network for an hour.

3. **Open the web interface.** Go to `http://pwrman.local/` from a phone or
   computer on the same network. After Wi-Fi setup from the setup page,
   **Next** takes you there. While setup is open, the **Settings** panel
   near the bottom opens by itself. Later you can find the page at the same
   address, or at the new name if you change it.

4. **Choose an API token.** In **Settings**, set an **API token** and press
   **Save**. This is the password for changing anything from the web interface or
   the API. You'll need it on any other device, so keep it somewhere safe.
   Once the token is saved, setup is closed and the amber light stops.

5. **Set the power budget.** Still in **Settings**, set the **Chassis budget**
   to your supply's rating in watts, or a little under it. See
   [Sharing power between ports](/guide/sharing-power/) for
   how the budget is used.

6. **Optional: give it a name and connect Home Assistant.** Set a device
   name if you have more than one Power Manifold. Fill in your MQTT broker
   if you use Home Assistant; see
   [Home Assistant](/guide/home-assistant/). Press **Reboot**
   to apply a new name or broker.

</Steps>

Setup is complete. When a device is plugged in, its port light turns blue or
green.

## If setup closed before you saved a token

The **Settings** panel tells you which case you are in:

- **On Ethernet**, the 1-hour window has ended. Switch the power supply off and on
  again, or press the button on the controller card once, then reload the
  page. You have another hour.
- **On Wi-Fi**, the 1-hour window has ended.
  [Open Wi-Fi setup again](/setup/wifi-provisioning/#changing-wi-fi-later)
  and redo Wi-Fi setup, or plug in an Ethernet cable and restart the
  controller to use the Ethernet route instead.

## Ethernet and Wi-Fi together

When both are connected, the controller uses Ethernet and keeps Wi-Fi as a
backup. Set a fixed address if you want one. See
[Network settings](/integrations/network/).

## Next steps

- [Front panel and lights](/guide/front-panel/): what each
  light color means and what the button does.
- [Port settings](/guide/port-settings/): name your ports
  and decide which come on at power-up.
- [Sharing power between ports](/guide/sharing-power/):
  pick which ports should be turned down first.

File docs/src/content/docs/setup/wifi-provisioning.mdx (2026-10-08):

---
title: Wi-Fi setup
description: Send Power Manifold your Wi-Fi details from this page or from the Home Assistant app.
sidebar:
  order: 2
---

import { Aside, Steps } from '@astrojs/starlight/components';
import ImprovProvisioner from '../../../components/ImprovProvisioner.astro';

Power Manifold gets its Wi-Fi details over a short-range wireless link,
using the [Improv Wi-Fi](https://www.improv-wifi.com/) standard. You can do
it from this page or from the Home Assistant app. The setup runs in your
browser and connects directly to the controller, so your Wi-Fi password is
sent only to the controller. Your phone or computer must be near the
chassis.

<ImprovProvisioner />

<Aside type="note" title="Which browser?">
This page works in Chrome and Edge on desktop and Android. It does not work
in Safari or Firefox, or in any browser on an iPhone or iPad. On those, use
the Home Assistant app: go to **Settings → Devices & services → Add
integration** and search for **Improv**. The app also shows a
notification by itself when it finds a Power Manifold waiting for setup.
Either way, open `http://pwrman.local/` afterwards to finish setup.
</Aside>

## Steps

<Steps>

1. **Turn it on.** A controller with no Wi-Fi details starts waiting for
   setup by itself about 15 seconds after power-up, unless it is already on
   the network over Ethernet. The chassis light, left of port 1, breathes blue while
   it waits.

2. **Connect.** Press the button above. Your browser lists nearby devices
   waiting for setup. Pick Power Manifold.

3. **Identify it (optional).** If you have more than one, press
   **Identify**. The port lights on that one flash blue.

4. **Enter your Wi-Fi name and password.** The controller joins your
   network. If the password is wrong, or the controller gets no address
   within 30 seconds, you'll see *unable to connect* and can try again.

5. **Press Next.** When it says *Provisioned!*, press **Next**. It opens the
   controller's web interface. On a new controller the settings stay open
   to anyone on your network for an hour, so you can finish
   [first-time setup](/setup/first-time-setup/#steps) by choosing an API
   token. If **Next** is not offered, go to `http://pwrman.local/`.

</Steps>

## Changing Wi-Fi later

The controller's setup link is open only while it is waiting for setup.
It starts waiting by itself when it has no Wi-Fi details, or when it has
been off the network for five minutes. To change networks on a controller
that is working, open a ten-minute setup window in either of these ways:

- Hold the front-panel button for 3 seconds, then let go before 10 seconds.
  See [the button](/guide/front-panel/#the-button).
- Press **Open Wi-Fi setup** in Home Assistant.

Then follow the steps above. The setup link is off at all other times.

<Aside type="caution">
The setup link is not encrypted. Run setup only when no untrusted person
is near the chassis.
</Aside>

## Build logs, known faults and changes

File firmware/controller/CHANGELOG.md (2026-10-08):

# Changelog

## [0.16.1](https://github.com/mikesmitty/power-manifold/compare/controller-firmware-v0.16.0...controller-firmware-v0.16.1) (2026-10-08)

### Bug Fixes

* **controller:** plain text field for the UTC offset ([491df69](https://github.com/mikesmitty/power-manifold/commit/491df697719f4a3a8ac37928c06ecfb865e4a1c9))
* **controller:** plain text fields for every number in settings ([e5cd0b9](https://github.com/mikesmitty/power-manifold/commit/e5cd0b99f99cb457b2356b1594c5cc60951264ff))
* **controller:** show the restart after an update instead of the old offer ([7741292](https://github.com/mikesmitty/power-manifold/commit/774129269f118346f3add9a9b7aaac9be3443d2f))

## [0.16.0](https://github.com/mikesmitty/power-manifold/compare/controller-firmware-v0.15.0...controller-firmware-v0.16.0) (2026-10-08)

### Features

* **controller:** answer only to the controller's own host names ([650d994](https://github.com/mikesmitty/power-manifold/commit/650d9949093035daad9d3fb811f14dd2ae58b0b4))
* **controller:** install new releases automatically ([2a34d56](https://github.com/mikesmitty/power-manifold/commit/2a34d5680581ef2b3b2480e764fca6d436f01c79))
* **controller:** keep the bus-voltage trim off the network ([566d340](https://github.com/mikesmitty/power-manifold/commit/566d340e268d05cf8a12fc6b9a0d4ed4fa99d9d7))
* **controller:** link the wrong-name page to the Host names docs ([bd4a0bc](https://github.com/mikesmitty/power-manifold/commit/bd4a0bcb8ae3e010f870e53cb1a600c37255afad))
* **controller:** log refused web requests ([69d835f](https://github.com/mikesmitty/power-manifold/commit/69d835f7d61bc9e0b7c6bba345abdec2f80a213f))
* **controller:** one hour of first-time setup on Wi-Fi as on Ethernet ([36607f8](https://github.com/mikesmitty/power-manifold/commit/36607f86e185449cdce6a6f75bedb845a83e54f9))
* **controller:** open first-time setup for ten minutes after Wi-Fi setup ([34cd1d0](https://github.com/mikesmitty/power-manifold/commit/34cd1d0ff34061f9b4137e0d46249601fa0645e0))
* **controller:** run console commands from the web page ([3804d25](https://github.com/mikesmitty/power-manifold/commit/3804d25c2098a5d6a0ffcf9a56e6c7aa96db1107))
* **controller:** serve the web interface over HTTPS with an installed certificate ([2f34c7c](https://github.com/mikesmitty/power-manifold/commit/2f34c7c6780fc9e52ed613b85af6d0fc912da7f8))
* **controller:** update, network and Wi-Fi setup in the JSON API ([43edcc0](https://github.com/mikesmitty/power-manifold/commit/43edcc0c4eedd64fb5322b56c4a25cbba4a74364))

### Bug Fixes

* **controller:** compare bearer tokens in constant time ([08cd224](https://github.com/mikesmitty/power-manifold/commit/08cd22490470bab54738da4a74cee37f2781ddec))
* **controller:** erase every stored settings copy on factory reset ([134eabe](https://github.com/mikesmitty/power-manifold/commit/134eabebdab6cdf9add9d225b2c73b6950e3b35c))
* **controller:** keep HTTPS up across certificate swaps and restarts of the listener ([203064a](https://github.com/mikesmitty/power-manifold/commit/203064ace151c92c81cb389a745d21ca9aee7afa))
* **controller:** plain console messages for failed pulls and debounced saves ([4f3f97a](https://github.com/mikesmitty/power-manifold/commit/4f3f97a1389a5e1d59c4f7a214d0b1be086a529f))
* **controller:** read a refused upload's body before closing ([cd4681f](https://github.com/mikesmitty/power-manifold/commit/cd4681fd705ccb772e5acc47c51fa5ff7c9ffd4e))
* **controller:** read the Wi-Fi RSSI from the main loop, not per request ([707286f](https://github.com/mikesmitty/power-manifold/commit/707286fb71d790af5ca43a88ebb0f754a03922b4))
* **controller:** refuse cross-site requests through the setup doors ([31fdf21](https://github.com/mikesmitty/power-manifold/commit/31fdf21b1ffdfc6241a86cc4b462cfd5f825fca9))
* **controller:** report a refused MQTT broker certificate in the status ([0312839](https://github.com/mikesmitty/power-manifold/commit/03128392b95e944bc8b698fd52b4f78639cd4d5c))
* **controller:** store certificate chains of up to six certificates ([cd0c6d9](https://github.com/mikesmitty/power-manifold/commit/cd0c6d95e73cef4ff78cf47182127778dc63e3dd))
* **controller:** write updates into the slot the running image did not boot from ([882263c](https://github.com/mikesmitty/power-manifold/commit/882263c4ac5ac8b6e438266ef8e643235202f2a7))

## [0.15.0](https://github.com/mikesmitty/power-manifold/compare/controller-firmware-v0.14.0...controller-firmware-v0.15.0) (2026-10-07)

### Features

* **controller:** call the radio setup path "Wi-Fi setup" instead of Bluetooth ([1fe6332](https://github.com/mikesmitty/power-manifold/commit/1fe6332c3b7bf130ceecb9b35956c0a2c88b029b))
* **controller:** protect running devices from renegotiation ([9e4f559](https://github.com/mikesmitty/power-manifold/commit/9e4f559a0b26ae9a26aa5cedf5dc17336549ac1e))

### Bug Fixes

* **controller:** announce the blade "updated" event to Home Assistant ([2481aee](https://github.com/mikesmitty/power-manifold/commit/2481aee970cd8108212bd32246ec7bc6dffbe2c7))
* **controller:** use US wording in the page, console and Home Assistant ([0cc130f](https://github.com/mikesmitty/power-manifold/commit/0cc130f87fa020b362b499ff01ce5a7ea38063b1))

## [0.14.0](https://github.com/mikesmitty/power-manifold/compare/controller-firmware-v0.13.0...controller-firmware-v0.14.0) (2026-10-06)

### Features

* **controller:** open Settings at the token field when a change needs it ([bf3633a](https://github.com/mikesmitty/power-manifold/commit/bf3633a7f9704bada51e678d8992fc35bd0de9ba))
* **controller:** restyle the web page like the front of the chassis ([2884df2](https://github.com/mikesmitty/power-manifold/commit/2884df2440a09d7eeb64fc55194fb8b55b60a449))

### Bug Fixes

* **controller:** name charge events on MQTT ([2b108b9](https://github.com/mikesmitty/power-manifold/commit/2b108b9632afb296ce416499f6a3b6d685837938))
* **controller:** stop web page labels overlapping or splitting ([70baa26](https://github.com/mikesmitty/power-manifold/commit/70baa26e945b5751f3b1fa152bcdd3541427b79d))

## [0.13.0](https://github.com/mikesmitty/power-manifold/compare/controller-firmware-v0.12.0...controller-firmware-v0.13.0) (2026-10-06)

### Features

* **controller:** breathe the chassis light red with no network ([53d8d74](https://github.com/mikesmitty/power-manifold/commit/53d8d74d1b1be2a962ad32b2f0c22657820c1154))
* **controller:** drive the chassis light at the head of the light bar ([cedbd06](https://github.com/mikesmitty/power-manifold/commit/cedbd06a386f39cc354731ec4e6da31c21b5d7d0))
* **controller:** first-time setup over Ethernet, no changes without a token ([e418972](https://github.com/mikesmitty/power-manifold/commit/e418972b2a028b1940f03acded0174b82b0bbcca))
* **controller:** redesign the web page ([16bff12](https://github.com/mikesmitty/power-manifold/commit/16bff1206038b9fba9c0d4fcc26c7b5347fd983d))
* **controller:** retire magenta from the status lights ([aee9fe1](https://github.com/mikesmitty/power-manifold/commit/aee9fe19f04ed03800dc4856e0a87405b4fcebda))
* **controller:** show 12 V and up in blue, 5 and 9 V in green ([5d539dc](https://github.com/mikesmitty/power-manifold/commit/5d539dc3b00742d5c86e76ab6ad94ad046079716))
* **controller:** show bus faults and an all-clear glow on the chassis light ([3dcfda6](https://github.com/mikesmitty/power-manifold/commit/3dcfda67b80647b376a92d8d561e178765993302))
* **controller:** swap the empty-slot and ready port colours ([32a6ce6](https://github.com/mikesmitty/power-manifold/commit/32a6ce6e7e0405aaf74c48abd9189a6e4e48acf8))
* **controller:** turn an active port green from 11 V, not 19 V ([54096a3](https://github.com/mikesmitty/power-manifold/commit/54096a395687a62017f980c3dace82a2e763a8ea))
* **controller:** turn ports on and off from the web page ([4aaef0d](https://github.com/mikesmitty/power-manifold/commit/4aaef0d2664b17a2f2751e60f0ebb6b4c726affc))

### Bug Fixes

* **controller:** draw an updating port dark on the web page ([6502714](https://github.com/mikesmitty/power-manifold/commit/6502714f0bac3786fb5fd185fdae372fbd749592))
* **controller:** give the links 15 s after power-up before flagging no network ([e8fce1d](https://github.com/mikesmitty/power-manifold/commit/e8fce1d6d0813768b30bd88abe3f2ec00a41f423))

## [0.12.0](https://github.com/mikesmitty/power-manifold/compare/controller-firmware-v0.11.0...controller-firmware-v0.12.0) (2026-10-05)

### ⚠ BREAKING CHANGES

* **controller:** a build without -DPICO_BOARD is now for the controller card, and a release's unsuffixed files (controller.uf2, controller.elf, controller.signed.bin, partition_table.uf2) are the card's. The Pico 2 W build is published as controller-pico2w.* and partition_table-pico2w.uf2; pass -DPICO_BOARD=pico2_w to build it.

### Features

* **controller:** add a PEM and DER codec for certificates ([48bfead](https://github.com/mikesmitty/power-manifold/commit/48bfead85a7f3cd7f83e5443b0d9e7aa084e5231))
* **controller:** build for the controller card by default ([68d33ae](https://github.com/mikesmitty/power-manifold/commit/68d33ae89d8687b93ae0ec7281221167c0ee9239))
* **controller:** cap ports at 3 A while the DC bus sags ([fff3f2d](https://github.com/mikesmitty/power-manifold/commit/fff3f2d301bb3d766a57f761ea39d6756d44d5ab))
* **controller:** factory image for first programming over SWD ([660d443](https://github.com/mikesmitty/power-manifold/commit/660d443b65859c80ee5f6db1f425584c153d1e48))
* **controller:** look for new releases and offer them ([e55e9a9](https://github.com/mikesmitty/power-manifold/commit/e55e9a941ff525c85c1ad35692481cc49ce3ce0e))
* **controller:** poll a shipped time server behind the one DHCP names ([304f1b6](https://github.com/mikesmitty/power-manifold/commit/304f1b6f00d47af4a33ff74f41d1d9d14cc94d7b))
* **controller:** report the model as PM6 to Home Assistant ([caa6d55](https://github.com/mikesmitty/power-manifold/commit/caa6d557f18f4256b92f99b4bbe33aa46701f90d))
* **controller:** run the fan from the gen-3 blade thermometers ([b18cbe1](https://github.com/mikesmitty/power-manifold/commit/b18cbe16500606244c3252fb7f5434d6fa92a4be))
* **controller:** TLS on the broker link with an optional certificate ([eb6c3b5](https://github.com/mikesmitty/power-manifold/commit/eb6c3b5f1f09f434a5243cb732108beefca174e4))
* **controller:** trust a backup update key held on a YubiKey ([d14e544](https://github.com/mikesmitty/power-manifold/commit/d14e5445708a9a472e9639af2babecc91e0ff9be))
* **controller:** trust the Let's Encrypt roots on the broker link ([e5f97e4](https://github.com/mikesmitty/power-manifold/commit/e5f97e4e47c71999f5699c436545408ea5d02f1c))

### Bug Fixes

* **controller:** let a trial image commit on a flapping WiFi link ([bfaa83c](https://github.com/mikesmitty/power-manifold/commit/bfaa83ca154b14b3c67d6dd8644ae010250d4129))

## [0.11.0](https://github.com/mikesmitty/power-manifold/compare/controller-firmware-v0.10.0...controller-firmware-v0.11.0) (2026-10-01)

### ⚠ BREAKING CHANGES

* **controller:** POST /api/v1/update and the Home Assistant install refuse unsigned images (controller.uf2, a plain controller.bin) and images older than the running firmware. Use the release's controller.signed.bin, or the console's `update --unsigned` / `--downgrade`.

### Features

* **controller:** drive gen-3 charger blades ([bfe9e21](https://github.com/mikesmitty/power-manifold/commit/bfe9e2197b359ca84e9c29a2a06b7411baff8b67))
* **controller:** install only signed images over the network ([c9f8365](https://github.com/mikesmitty/power-manifold/commit/c9f83656192faf857771c028838adeb7319cf174))
* **controller:** program gen-3 blade firmware over the backplane ([6264846](https://github.com/mikesmitty/power-manifold/commit/62648468bd28f223099555a4d67a6dd6dc49f644))
* **controller:** read the gen-3 blade's thermometers ([187d6d6](https://github.com/mikesmitty/power-manifold/commit/187d6d6c72eec33c72838535d7864d573b935859))

### Bug Fixes

* **controller:** build fake-blade images without a blade firmware bundle ([be6711b](https://github.com/mikesmitty/power-manifold/commit/be6711bfe97188892ec3802a259191b4230b08e4))
* **controller:** build the MPQ4242 driver with the port fault names ([2b32b32](https://github.com/mikesmitty/power-manifold/commit/2b32b32afe2e036b63ee18c3f35d555a106b53c9))
* **controller:** keep ports powered through updates, silent blades and bad reads ([77805dc](https://github.com/mikesmitty/power-manifold/commit/77805dcb48593ccc728670e56960e264620d9f7b))
* **controller:** keep settings readable across a reverted update ([2bf24c9](https://github.com/mikesmitty/power-manifold/commit/2bf24c98622522969718758021f0103dca3f9755))

## [0.10.0](https://github.com/mikesmitty/power-manifold/compare/controller-firmware-v0.9.0...controller-firmware-v0.10.0) (2026-09-24)

### Features

* **controller:** hold every PDO to 100 W, so the 21 V PPS range advertises 4.75 A ([b5da427](https://github.com/mikesmitty/power-manifold/commit/b5da427e0bd2c3ffb6749e1c158b043530f9e37a))

### Bug Fixes

* **controller:** release the reset lines to the backplane's 5 V pull-ups ([526a81f](https://github.com/mikesmitty/power-manifold/commit/526a81f77ee03e27a46303efaf813b8cbf7e74e5))

## [0.9.0](https://github.com/mikesmitty/power-manifold/compare/controller-firmware-v0.8.0...controller-firmware-v0.9.0) (2026-09-17)

### Features

* **controller:** declare the DC input range as 20-28 V and flag the bus above 29 V ([f309804](https://github.com/mikesmitty/power-manifold/commit/f3098041c300953af951b49f87ab5ca9fa27e106))

## [0.8.0](https://github.com/mikesmitty/power-manifold/compare/controller-firmware-v0.7.0...controller-firmware-v0.8.0) (2026-09-10)

### Features

* **controller-firmware:** DC bus voltage monitor on the controller card ([4b7601d](https://github.com/mikesmitty/power-manifold/commit/4b7601d357a858d0cc010e438ffd6a9b6d1f39c6))
* **controller-firmware:** front-panel button — wake the LEDs, open BLE, hold to factory-reset ([f7e6fb9](https://github.com/mikesmitty/power-manifold/commit/f7e6fb923512d4b1533e9b33c77032227f3f844c))
* **controller-firmware:** warm start keeps port power across a controller reboot, plus the card's board header ([9e1b223](https://github.com/mikesmitty/power-manifold/commit/9e1b22329d179107f5c9ca7f3ac1bacf3d290593))
* **controller:** move the bus-high warning to 33 V ([1a50e51](https://github.com/mikesmitty/power-manifold/commit/1a50e519b4c322c359694846979edd4e4cb51caa))

### Bug Fixes

* **controller-firmware:** clear the pad pull-down on SDA, SCL and ALERT# ([4fd1637](https://github.com/mikesmitty/power-manifold/commit/4fd16379f95fda0e70c7b3ee0766067bf3cd8122))

## [0.7.0](https://github.com/mikesmitty/power-manifold/compare/controller-firmware-v0.6.0...controller-firmware-v0.7.0) (2026-09-08)

### Features

* **controller:** Mean Well LAD UPS supply on the card's UPS header ([e934818](https://github.com/mikesmitty/power-manifold/commit/e934818837a817bb97dffdeba75236bea9e9e89c))

## [0.6.0](https://github.com/mikesmitty/power-manifold/compare/controller-firmware-v0.5.0...controller-firmware-v0.6.0) (2026-09-08)

### Features

* **controller:** charged sinks show solid magenta on the status LEDs ([7c44edb](https://github.com/mikesmitty/power-manifold/commit/7c44edb925ade4094516016d5ed96a17c8c9e107))
* **controller:** per-port voltage cap on the advertised PDO set ([f990bee](https://github.com/mikesmitty/power-manifold/commit/f990beef028354a75e2606992d394a8912ded923))

### Bug Fixes

* **controller:** enable the internal pull-up on EXP_INT# ([68f72e2](https://github.com/mikesmitty/power-manifold/commit/68f72e248bbe3ac9985378dc1e125118503c1dd3))
* **controller:** subscribe to MQTT command topics one per SUBACK ([a734ab7](https://github.com/mikesmitty/power-manifold/commit/a734ab735f21c4aacc47ab9b74d2720c307b8b15))

## [0.5.0](https://github.com/mikesmitty/power-manifold/compare/controller-firmware-v0.4.1...controller-firmware-v0.5.0) (2026-09-05)

### Features

* **controller:** aggregate problem indicator with a Home Assistant binary sensor ([e5ac774](https://github.com/mikesmitty/power-manifold/commit/e5ac774ccf1936ace05bb6b261f4c455a4beb1a8))
* **controller:** board definition for the WIZnet W6100-EVB-Pico2 ([cf5ddfa](https://github.com/mikesmitty/power-manifold/commit/cf5ddfa3c7501b502af9b6fd36c0daab0193a360))
* **controller:** charge-complete detection with off-when-charged and a sleep timer ([d8c2c71](https://github.com/mikesmitty/power-manifold/commit/d8c2c7130f3a9ae9465c48aa5f18da318c7b6f2d))
* **controller:** console fault injection for the simulated backplane ([b4306f0](https://github.com/mikesmitty/power-manifold/commit/b4306f0cea4df3788f7ccc9a026847e34da25a65))
* **controller:** console log ring with UDP syslog and GET /api/v1/log ([9aca382](https://github.com/mikesmitty/power-manifold/commit/9aca3822415c9b0be0ec3a6f792d99d305b37663))
* **controller:** fault log over the API and the page, last fault per port in HA ([27e7cfc](https://github.com/mikesmitty/power-manifold/commit/27e7cfc444144a61d08aee71d0b98021a7b8a9c4))
* **controller:** Home Assistant event entity per port from the MQTT event topic ([7ef93f0](https://github.com/mikesmitty/power-manifold/commit/7ef93f02910db513c65e0d1e250a852e86952aba))
* **controller:** LED night window and idle dimming ([5a05566](https://github.com/mikesmitty/power-manifold/commit/5a055668ddf2777ccd5e5559545d8e5218d02963))
* **controller:** per-port current limit on every surface, applied live ([bd96af8](https://github.com/mikesmitty/power-manifold/commit/bd96af81f75dfae222ce30fd4347550e2a846b1f))
* **controller:** per-port names on the console, API, page and Home Assistant ([2d8aa3e](https://github.com/mikesmitty/power-manifold/commit/2d8aa3e9ed3db1a3abbf1b1d8414ed49bea4a158))
* **controller:** per-port power-up state, on, off or last ([7b6098f](https://github.com/mikesmitty/power-manifold/commit/7b6098fe0394732a936cd79ab55f26e5df83e45e))
* **controller:** Prometheus text exposition on GET /metrics ([eabb3c2](https://github.com/mikesmitty/power-manifold/commit/eabb3c273f4dbb956338d221999fb0b889eadd38))
* **controller:** report why the controller booted and surface crashes ([de0f9a5](https://github.com/mikesmitty/power-manifold/commit/de0f9a582a25681f10a156139f33cb76a1b25d4d))
* **controller:** settings export and import, host-tested round trip ([1f97a9f](https://github.com/mikesmitty/power-manifold/commit/1f97a9f0b1a7e7e058d56053e1d36175e8190c8b))
* **controller:** stagger the blades seated at boot, by priority ([270cbf1](https://github.com/mikesmitty/power-manifold/commit/270cbf197ceb4782790fdc3e5f31a717bf5f64c9))
* **controller:** static IPv4 addressing and a DNS override ([f29ae9a](https://github.com/mikesmitty/power-manifold/commit/f29ae9a1819d6943ae9699a9faa391f2fa2857ed))
* **controller:** status LED scheme with chassis overlays and brightness controls ([2aa1458](https://github.com/mikesmitty/power-manifold/commit/2aa14588f2fe57afcc7388cb5f796d5513c72258))

### Bug Fixes

* **controller:** bench findings for addressing output and the syslog backlog ([f176b5c](https://github.com/mikesmitty/power-manifold/commit/f176b5c953265b4e9aac508968678aa8d963cf2d))
* **controller:** clamp TCP MSS under the broker's Cilium/WireGuard path; a stalled MQTT link no longer starves lwIP ([c483164](https://github.com/mikesmitty/power-manifold/commit/c483164a65cb4224efa4a378851fbd7d13885127))
* **controller:** stop lwIP refusing the tail of every MQTT burst ([b3e5c1b](https://github.com/mikesmitty/power-manifold/commit/b3e5c1b1ca05755eb13639245e52c2bf88f54c73))
* **controller:** stream HTTP bodies a segment at a time so the page loads beside MQTT ([d271739](https://github.com/mikesmitty/power-manifold/commit/d2717397db006770c6dd12ce50471f9ed2507202))
* **controller:** W6100 bring-up fixes from the first board ([06c3e8d](https://github.com/mikesmitty/power-manifold/commit/06c3e8daba00497343d1a958147a44e0f1689d05))

## [0.4.1](https://github.com/mikesmitty/power-manifold/compare/controller-firmware-v0.4.0...controller-firmware-v0.4.1) (2026-09-03)

### Bug Fixes

* **controller:** keep the settings sequence counter across `defaults` ([62376d6](https://github.com/mikesmitty/power-manifold/commit/62376d61701abdbd9222bb82cf88a806b33d2bf1))
* **controller:** notify the Improv result URL before the provisioned state ([8496781](https://github.com/mikesmitty/power-manifold/commit/84967819c1ce49105ec4818ad2b674b72e16bc59))
* **controller:** serve the root page when the request carries a query string ([7da4816](https://github.com/mikesmitty/power-manifold/commit/7da481699991dbecc7afc52554d20e881bfa269a))

## [0.4.0](https://github.com/mikesmitty/power-manifold/compare/controller-firmware-v0.3.0...controller-firmware-v0.4.0) (2026-09-02)

### Features

* **controller:** fan auto-on for contracts over 3A ([e6c0904](https://github.com/mikesmitty/power-manifold/commit/e6c09046d3a815baecf1f7d63a817d3e2bfcc98a))
* **controller:** Improv Wi-Fi BLE provisioning ([4398049](https://github.com/mikesmitty/power-manifold/commit/4398049910f927196d6a0950aa6107cd41b24d17))
* **controller:** make the chassis power budget settable remotely ([c595a2c](https://github.com/mikesmitty/power-manifold/commit/c595a2c6e5b23b354ad1ae42d2b0f5ff5c996f8e))
* **controller:** per-port history sparklines in the web UI ([f8a24fe](https://github.com/mikesmitty/power-manifold/commit/f8a24fe692447e0029dc59a0d6e5054c8e51d027))
* **controller:** program the blade PDO table with fixed 12 V and 11 V PPS ([c4cbc17](https://github.com/mikesmitty/power-manifold/commit/c4cbc176b7da49b83af443ab73990c046cf28eef))
* **controller:** show measured draw alongside budget reservation in the web UI ([5074caf](https://github.com/mikesmitty/power-manifold/commit/5074caf8c3083c259a56c27b774c8d003a46e461))
* **controller:** W6100 wired Ethernet as an lwIP netif ([1651d55](https://github.com/mikesmitty/power-manifold/commit/1651d55fcddc0f10d7c7b4a6c8fba529dec2657e))
* **controller:** web UI settings panel with Improv setup secret ([62df4f2](https://github.com/mikesmitty/power-manifold/commit/62df4f23e887e04f8da48a1be3c7834c19bf3bd1))

### Bug Fixes

* **controller:** cap the settable power budget at 600W ([747cade](https://github.com/mikesmitty/power-manifold/commit/747cade1f104d65222a9449d4193034fa28e7c2c))
* **controller:** core 0 stack overflow into the engine, plus bench diagnostics ([0bfd9b2](https://github.com/mikesmitty/power-manifold/commit/0bfd9b22a343fc512659a77cdc8c2a422b50c3fa))

## [0.3.0](https://github.com/mikesmitty/power-manifold/compare/controller-firmware-v0.2.0...controller-firmware-v0.3.0) (2026-08-31)

### Features

* **controller:** automatic fan policy with hysteresis ([d256d2c](https://github.com/mikesmitty/power-manifold/commit/d256d2cdbdde2efd187038a6407d25cb29abe15f))
* **controller:** HA buttons for hard reset/src-cap and port priority numbers ([5802dc6](https://github.com/mikesmitty/power-manifold/commit/5802dc6ffcb6bc40376f27674c1bb9b5c63717d3))
* **controller:** Home Assistant update entity with HTTP pull OTA ([c8b5fd8](https://github.com/mikesmitty/power-manifold/commit/c8b5fd83c2afda4ee73d0474b96182fdc7301388))
* **controller:** per-port and chassis energy sensors ([b102fb8](https://github.com/mikesmitty/power-manifold/commit/b102fb8f9eb3cb00b54d486c55c23f989a8bdcad))
* **controller:** persistent fault log in the data partition ([a3c83df](https://github.com/mikesmitty/power-manifold/commit/a3c83df7a8bef5f2484fc82cace32c63f59a150c))
* **controller:** recover throttled ports in partial steps ([bf6f2ed](https://github.com/mikesmitty/power-manifold/commit/bf6f2edbfe7e802796e2604e80eee0aa04909f7f))

## [0.2.0](https://github.com/mikesmitty/power-manifold/compare/controller-firmware-v0.1.0...controller-firmware-v0.2.0) (2026-08-31)

### Features

* **controller:** add OTA update endpoint writing the inactive A/B slot ([231ed1e](https://github.com/mikesmitty/power-manifold/commit/231ed1ede804ea6432b141c07baeeedbaceb8f84))
* **controller:** host-side engine tests and fake-blade mode ([4461f2b](https://github.com/mikesmitty/power-manifold/commit/4461f2bee788238798c0773611121a35eb54db29))
* **controller:** partition-table flash map with A/B slots and TBYB commit ([5477425](https://github.com/mikesmitty/power-manifold/commit/5477425efcc60b5fca2c1e9b68d7a4f910a3847b))
* **controller:** priority-based throttle victim selection ([35dd734](https://github.com/mikesmitty/power-manifold/commit/35dd734ab810ae2498e332097257ac0c1ec5ae31))
* **controller:** tune blade over-current protection to MPQ4242 behavior ([5d90338](https://github.com/mikesmitty/power-manifold/commit/5d903384696dc165cf1a04558c565f2434d8131e))

### Bug Fixes

* **controller:** keep a taken-over OTA connection from aborting its successor ([1b276e0](https://github.com/mikesmitty/power-manifold/commit/1b276e0aceb860a5e4bad5daaa3e946994826095))

## 0.1.0 (2026-08-30)

### Features

* **controller:** scaffold native RP2350 controller firmware ([8041d8e](https://github.com/mikesmitty/power-manifold/commit/8041d8e629d8cfa35920143ea43562d2a1f5bbac))

## Changelog

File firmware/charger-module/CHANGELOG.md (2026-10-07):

# Changelog

## [0.4.0](https://github.com/mikesmitty/power-manifold/compare/charger-module-firmware-v0.3.0...charger-module-firmware-v0.4.0) (2026-10-07)

### Features

* **charger-module:** count PD hard resets ([174cee5](https://github.com/mikesmitty/power-manifold/commit/174cee51109bf054efab80131634793ddfadf7ca))

## [0.3.0](https://github.com/mikesmitty/power-manifold/compare/charger-module-firmware-v0.2.0...charger-module-firmware-v0.3.0) (2026-10-05)

### Features

* **charger-module:** warn the sink before an over-temperature trip ([5422a0c](https://github.com/mikesmitty/power-manifold/commit/5422a0c8a16bb47b572f93d634629f14ef0e0f2d))

## [0.2.0](https://github.com/mikesmitty/power-manifold/compare/charger-module-firmware-v0.1.0...charger-module-firmware-v0.2.0) (2026-10-01)

### Features

* **charger-module-firmware:** declare register map version 1 ([1eb111e](https://github.com/mikesmitty/power-manifold/commit/1eb111e6ab9cdf9fb9246b9d0b3d941c196a732b))
* **charger-module-firmware:** reset into the ROM bootloader on request, on silence, and by option ([caac111](https://github.com/mikesmitty/power-manifold/commit/caac111e6694836d9445bfc8548a0c861c55654b))

### Bug Fixes

* **charger-module-firmware:** hold a hot reading for 50 ms before tripping ([d359fab](https://github.com/mikesmitty/power-manifold/commit/d359fab741582481ed11e9370d814db3d8eb17ff))
* **charger-module-firmware:** reset on the watch only with EN low, guard the reset commands ([b46f999](https://github.com/mikesmitty/power-manifold/commit/b46f9999985126b75c875c07b55e78d59988d1d4))

## 0.1.0 (2026-09-30)

### Features

* add adc reading cache for instant reads ([6d5c1f7](https://github.com/mikesmitty/power-manifold/commit/6d5c1f70831743ac66498cc9b01453e50adf55c9))
* add i2c registers and led functions ([0b01e47](https://github.com/mikesmitty/power-manifold/commit/0b01e478f39c8fec470629f8161a12b9826dd197))
* **charger-module-firmware:** add firmware for the STM32G071 charger blade ([a7667aa](https://github.com/mikesmitty/power-manifold/commit/a7667aa05b304783d402e94b22ebc2012f1ad259))
* **controller:** scaffold native RP2350 controller firmware ([8041d8e](https://github.com/mikesmitty/power-manifold/commit/8041d8e629d8cfa35920143ea43562d2a1f5bbac))
* initial charger firmware ([18ba888](https://github.com/mikesmitty/power-manifold/commit/18ba8886614f9ae0a21056d95de54454faf95615))
* update charger firmware for direct control ([3a91bbd](https://github.com/mikesmitty/power-manifold/commit/3a91bbd409cc3db423d2de4696927b5bc40629b4))

### Bug Fixes

* reduce logging verbosity ([68178a5](https://github.com/mikesmitty/power-manifold/commit/68178a5f561cc292b9639494e3d139653bb51584))
* turn off led when inactive ([81dfc89](https://github.com/mikesmitty/power-manifold/commit/81dfc895c7fd111b6f7a23a21a772b41114c7d26))

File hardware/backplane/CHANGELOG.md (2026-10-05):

# Changelog

## [0.13.2](https://github.com/mikesmitty/power-manifold/compare/backplane-v0.13.1...backplane-v0.13.2) (2026-10-05)

### Bug Fixes

* **backplane:** adjust UVLO for 62368-1 B.2.3 ([9934627](https://github.com/mikesmitty/power-manifold/commit/99346279432e7640dbb34df166729f7528380e78))

## [0.13.1](https://github.com/mikesmitty/power-manifold/compare/backplane-v0.13.0...backplane-v0.13.1) (2026-09-29)

### Bug Fixes

* **backplane:** update assembly fields for JLCPCB ([69026bc](https://github.com/mikesmitty/power-manifold/commit/69026bc56567cbd5a01380b7fa7d0023461dadbf))

## [0.13.0](https://github.com/mikesmitty/power-manifold/compare/backplane-v0.12.2...backplane-v0.13.0) (2026-09-26)

### Features

* **backplane:** switch LED cable to 5 pin reversible ([d062fa5](https://github.com/mikesmitty/power-manifold/commit/d062fa519d5f54b865c6fa7d350be0a71f356956))

### Bug Fixes

* **backplane:** remove unused pullup resistor networks ([fb68454](https://github.com/mikesmitty/power-manifold/commit/fb68454d7504ecdd46783dee343dc2421e47a26a))

## [0.12.2](https://github.com/mikesmitty/power-manifold/compare/backplane-v0.12.1...backplane-v0.12.2) (2026-09-25)

### Bug Fixes

* **backplane:** bump missed revision number increment ([517cd25](https://github.com/mikesmitty/power-manifold/commit/517cd25c09dc8d87930082082cd6b7f090d8ea4f))

## [0.12.1](https://github.com/mikesmitty/power-manifold/compare/backplane-v0.12.0...backplane-v0.12.1) (2026-09-25)

### Bug Fixes

* **backplane:** remove 5v pullups on i2c ([b5e0382](https://github.com/mikesmitty/power-manifold/commit/b5e038201fd798465a89022eed0f46cb09af6cac))

## [0.12.0](https://github.com/mikesmitty/power-manifold/compare/backplane-v0.11.2...backplane-v0.12.0) (2026-09-17)

### Features

* **backplane:** LM74800 input stage with OVP and inrush limit, SMD fuse ([0bad6f2](https://github.com/mikesmitty/power-manifold/commit/0bad6f2c4661332ed45c9490008a6f6d81c99736))
* **backplane:** undervoltage cut-out on the LM74800 and a TPS16416 eFuse for the 5 V rail ([65a5369](https://github.com/mikesmitty/power-manifold/commit/65a5369a2d5dcad4bedddc21bcaa8e83336b4211))

### Bug Fixes

* **backplane:** C8 charge-pump capacitor to a 50 V X7R 0603 ([005b586](https://github.com/mikesmitty/power-manifold/commit/005b5869ef6fa17378ae369cb038c5b89ac1e595))

## [0.11.2](https://github.com/mikesmitty/power-manifold/compare/backplane-v0.11.1...backplane-v0.11.2) (2026-09-12)

### Bug Fixes

* **backplane:** make room for fuse and exhaust fan ([33ba555](https://github.com/mikesmitty/power-manifold/commit/33ba5550c852f326eee1fe87ee7de4aeba415dea))

## [0.11.1](https://github.com/mikesmitty/power-manifold/compare/backplane-v0.11.0...backplane-v0.11.1) (2026-09-10)

### Bug Fixes

* **backplane:** make socket 1 spacing consistent ([f2fc974](https://github.com/mikesmitty/power-manifold/commit/f2fc97481a2639310f8525ef6d5f6a066db28c13))

## [0.11.0](https://github.com/mikesmitty/power-manifold/compare/backplane-v0.10.2...backplane-v0.11.0) (2026-09-10)

### Features

* **backplane:** swap fan FET for higher voltage spec ([ed3f83b](https://github.com/mikesmitty/power-manifold/commit/ed3f83bf35ef006545e53160c853ba208feb56ac))

### Bug Fixes

* **backplane:** switch fan FET back to AO3400A ([0a3e0f9](https://github.com/mikesmitty/power-manifold/commit/0a3e0f97658cedaef296ba246184778ebf28c2c0))
* **backplane:** switch fan from VIN to 5V supply ([f37608f](https://github.com/mikesmitty/power-manifold/commit/f37608f774654e2fa32a1abe61cc817d77a9530f))
* **backplane:** switch TVS diode to bidirectional ([ed3f83b](https://github.com/mikesmitty/power-manifold/commit/ed3f83bf35ef006545e53160c853ba208feb56ac))

## [0.10.2](https://github.com/mikesmitty/power-manifold/compare/backplane-v0.10.1...backplane-v0.10.2) (2026-09-09)

### Bug Fixes

* update silkscreen layouts ([2757ea4](https://github.com/mikesmitty/power-manifold/commit/2757ea4baf1f9aa8df29a75b820561f585450467))

## [0.10.1](https://github.com/mikesmitty/power-manifold/compare/backplane-v0.10.0...backplane-v0.10.1) (2026-09-08)

### Bug Fixes

* **backplane:** remove 5v pullup on EXP_INT ([5a44444](https://github.com/mikesmitty/power-manifold/commit/5a44444243984a25755e71d38fa7919e5a70cd08))

## [0.10.0](https://github.com/mikesmitty/power-manifold/compare/backplane-v0.9.0...backplane-v0.10.0) (2026-09-02)

### Features

* **backplane:** update connector to xt60 ([c6df152](https://github.com/mikesmitty/power-manifold/commit/c6df152e43c9db52de9f9c709f2005145c9f8d67))

### Bug Fixes

* **backplane:** switch to lower emi ap64352 buck and 5V rail ([c6df152](https://github.com/mikesmitty/power-manifold/commit/c6df152e43c9db52de9f9c709f2005145c9f8d67))

## [0.9.0](https://github.com/mikesmitty/power-manifold/compare/backplane-v0.8.0...backplane-v0.9.0) (2026-08-31)

### Features

* **backplane:** update pcb for higher power ([c10f2d2](https://github.com/mikesmitty/power-manifold/commit/c10f2d2f9e9ecd4d4e8aedecc9c5d84b7b704873))

## [0.8.0](https://github.com/mikesmitty/power-manifold/compare/backplane-v0.7.7...backplane-v0.8.0) (2026-08-30)

### Features

* **backplane:** update to new generation ([e4af0c1](https://github.com/mikesmitty/power-manifold/commit/e4af0c1a8fe70551243ed0e62807cf6d5e45583a))

## [0.7.7](https://github.com/mikesmitty/power-manifold/compare/backplane-v0.7.6...backplane-v0.7.7) (2024-09-11)

### Bug Fixes

* add qr code for serial numbers ([a93a0fc](https://github.com/mikesmitty/power-manifold/commit/a93a0fc2a96c003166c58c34e3ffadafc17fc278))

## [0.7.6](https://github.com/mikesmitty/power-manifold/compare/backplane-v0.7.5...backplane-v0.7.6) (2024-08-17)

### Bug Fixes

* move fan headers so 4-pin fan plugs fit ([9713200](https://github.com/mikesmitty/power-manifold/commit/9713200d012df1082d5f478b315005e594c82122))

## [0.7.5](https://github.com/mikesmitty/power-manifold/compare/backplane-v0.7.4...backplane-v0.7.5) (2024-08-08)

### Bug Fixes

* add reverse polarity protection mosfet ([2afe8da](https://github.com/mikesmitty/power-manifold/commit/2afe8dad995c7af24ff7d0db02ad513eba687658))

## [0.7.4](https://github.com/mikesmitty/power-manifold/compare/backplane-v0.7.3...backplane-v0.7.4) (2024-08-02)

### Bug Fixes

* make sure the input has a gnd ([9e89fb6](https://github.com/mikesmitty/power-manifold/commit/9e89fb69b0984d57c87f4afeee9d4b00b62a6423))

## [0.7.3](https://github.com/mikesmitty/power-manifold/compare/backplane-v0.7.2...backplane-v0.7.3) (2024-08-01)

### Bug Fixes

* disconnect switch pins from i2c mux ([43d8c17](https://github.com/mikesmitty/power-manifold/commit/43d8c177ba27d518fe33105f22653d975bff59d6))

## [0.7.2](https://github.com/mikesmitty/power-manifold/compare/backplane-v0.7.1...backplane-v0.7.2) (2024-07-23)

### Bug Fixes

* fix fan header pinouts ([1386e08](https://github.com/mikesmitty/power-manifold/commit/1386e0885fd502d65d987aebbf47d9a931889ee8))

## [0.7.1](https://github.com/mikesmitty/power-manifold/compare/backplane-v0.7.0...backplane-v0.7.1) (2024-07-10)

### Bug Fixes

* clean up traces ([181868f](https://github.com/mikesmitty/power-manifold/commit/181868fa257600ebbe6f0f09d60b0f0e6955dadc))

## [0.7.0](https://github.com/mikesmitty/pdusb/compare/backplane-v0.6.0...backplane-v0.7.0) (2024-07-09)

### Features

* give vin 8 pins ([deeca54](https://github.com/mikesmitty/pdusb/commit/deeca54b5ecd7f126030e2663d6139264055c541))
* shrink charger module outline ([051fecc](https://github.com/mikesmitty/pdusb/commit/051fecc27901af27a6ce28e297dd4c0b121d335f))

### Bug Fixes

* add decoupling caps to i2c and swd switches ([98123b7](https://github.com/mikesmitty/pdusb/commit/98123b795a20ac01e529f1a2962bae2bb5664719))
* add pullup resistor to i2c switch reset pin ([98123b7](https://github.com/mikesmitty/pdusb/commit/98123b795a20ac01e529f1a2962bae2bb5664719))
* correct i2c pin mismatch ([deeca54](https://github.com/mikesmitty/pdusb/commit/deeca54b5ecd7f126030e2663d6139264055c541))

## [0.6.0](https://github.com/mikesmitty/pdusb/compare/backplane-v0.5.2...backplane-v0.6.0) (2024-07-07)

### Features

* add 5v fan headers to backplane ([#31](https://github.com/mikesmitty/pdusb/issues/31)) ([44fe18b](https://github.com/mikesmitty/pdusb/commit/44fe18beaf30929cd54f240da6189cc2349ec306))

## [0.5.2](https://github.com/mikesmitty/pdusb/compare/backplane-v0.5.1...backplane-v0.5.2) (2024-07-04)

### Bug Fixes

* add rotation corrections ([#23](https://github.com/mikesmitty/pdusb/issues/23)) ([d28bfbb](https://github.com/mikesmitty/pdusb/commit/d28bfbb0f5f295293d51a52142758b1be5bae77d))

## [0.5.1](https://github.com/mikesmitty/pdusb/compare/backplane-v0.5.0...backplane-v0.5.1) (2024-07-03)

### Bug Fixes

* can't forget the pull-ups ([38f5258](https://github.com/mikesmitty/pdusb/commit/38f52583257ef937b0b6ace3cdfb33ebec99fc47))

## [0.5.0](https://github.com/mikesmitty/pdusb/compare/backplane-v0.4.0...backplane-v0.5.0) (2024-07-01)

### Features

* add swd circuits for firmware updates ([3fe7ef4](https://github.com/mikesmitty/pdusb/commit/3fe7ef4b14e35cb9b6d7b5f8920c50c7c5d31d5d))
* add switch to access onboard rp2040 through charge plug ([3fe7ef4](https://github.com/mikesmitty/pdusb/commit/3fe7ef4b14e35cb9b6d7b5f8920c50c7c5d31d5d))

## [0.4.0](https://github.com/mikesmitty/pdusb/compare/backplane-v0.3.0...backplane-v0.4.0) (2024-06-29)

### Features

* add uart and alert line to backplane ([36bab3b](https://github.com/mikesmitty/pdusb/commit/36bab3bd54e157625549632fdef713c6cf7a9887))

## [0.3.0](https://github.com/mikesmitty/pdusb/compare/backplane-v0.2.0...backplane-v0.3.0) (2024-06-28)

### Features

* add initial config for backplane ([c16be59](https://github.com/mikesmitty/pdusb/commit/c16be598a50d608be1e3e5ce62dde4558369b812))

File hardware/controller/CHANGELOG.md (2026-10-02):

# Changelog

## [0.4.2](https://github.com/mikesmitty/power-manifold/compare/controller-v0.4.1...controller-v0.4.2) (2026-10-02)

### Bug Fixes

* **controller:** add pogo pads for bulk programming ([cd95b0e](https://github.com/mikesmitty/power-manifold/commit/cd95b0e9a5231cee077846021b07c2520cd79f0e))

## [0.4.1](https://github.com/mikesmitty/power-manifold/compare/controller-v0.4.0...controller-v0.4.1) (2026-09-29)

### Bug Fixes

* **controller:** correct C6/C7 footprint name and assembly fields ([9ff1706](https://github.com/mikesmitty/power-manifold/commit/9ff17060bfbf730d4540d77c692c6cebb2b9cdef))

## [0.4.0](https://github.com/mikesmitty/power-manifold/compare/controller-v0.3.2...controller-v0.4.0) (2026-09-26)

### Features

* **controller:** re-layout to fit longer charger blades ([c750879](https://github.com/mikesmitty/power-manifold/commit/c7508795adc26e2c469c41ee794997e5989928f0))

## [0.3.2](https://github.com/mikesmitty/power-manifold/compare/controller-v0.3.1...controller-v0.3.2) (2026-09-12)

### Bug Fixes

* **controller:** re-orient wifi module for full keepout clearance ([07e0c20](https://github.com/mikesmitty/power-manifold/commit/07e0c200439555a06026be085c58174e0bc0ce52))

## [0.3.1](https://github.com/mikesmitty/power-manifold/compare/controller-v0.3.0...controller-v0.3.1) (2026-09-09)

### Bug Fixes

* update silkscreen layouts ([2757ea4](https://github.com/mikesmitty/power-manifold/commit/2757ea4baf1f9aa8df29a75b820561f585450467))

## [0.3.0](https://github.com/mikesmitty/power-manifold/compare/controller-v0.2.0...controller-v0.3.0) (2026-09-08)

### Features

* **controller:** add UART for UPS ([8322d1b](https://github.com/mikesmitty/power-manifold/commit/8322d1b8246f4917f4810697576cec840de3af76))

## [0.2.0](https://github.com/mikesmitty/power-manifold/compare/controller-v0.1.0...controller-v0.2.0) (2026-09-08)

### Features

* **controller:** add RPi RM2 and wire up remaining pins ([f91aabf](https://github.com/mikesmitty/power-manifold/commit/f91aabf46ac3b96c72c955c79bae42f6274bae56))

### Bug Fixes

* **controller:** add missing ground vias ([467a598](https://github.com/mikesmitty/power-manifold/commit/467a59896cae026958a4a95c28bb2ad033dbb9a4))
* **controller:** move rj45 jack inset 1mm ([f91aabf](https://github.com/mikesmitty/power-manifold/commit/f91aabf46ac3b96c72c955c79bae42f6274bae56))

## 0.1.0 (2026-09-06)

### Features

* **controller:** custom RP2350 management controller card ([c5d8235](https://github.com/mikesmitty/power-manifold/commit/c5d82352e11c41e03cc98140c9857f4f19d5e71c))

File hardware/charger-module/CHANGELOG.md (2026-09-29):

# Changelog

## [0.16.1](https://github.com/mikesmitty/power-manifold/compare/charger-module-v0.16.0...charger-module-v0.16.1) (2026-09-29)

### Bug Fixes

* **charger-module:** update assembly fields for JLCPCB ([258ec4d](https://github.com/mikesmitty/power-manifold/commit/258ec4dc3267305d98c43d29882a78f6b22ba8a4))

## [0.16.0](https://github.com/mikesmitty/power-manifold/compare/charger-module-v0.15.0...charger-module-v0.16.0) (2026-09-26)

### Features

* **charger-module:** add USART pads ([a1ce7eb](https://github.com/mikesmitty/power-manifold/commit/a1ce7eb872427e6b7bd9cee8fc1d15fcaca3738f))
* **charger-module:** switch to extended usb-c socket ([a1ce7eb](https://github.com/mikesmitty/power-manifold/commit/a1ce7eb872427e6b7bd9cee8fc1d15fcaca3738f))

## [0.15.0](https://github.com/mikesmitty/power-manifold/compare/charger-module-v0.14.3...charger-module-v0.15.0) (2026-09-24)

### Features

* **charger-module:** switch from mpq4242 to stm32 PD controller ([ad7a22c](https://github.com/mikesmitty/power-manifold/commit/ad7a22cffad270da1865c72ac63849b145bc762f))

## [0.14.3](https://github.com/mikesmitty/power-manifold/compare/charger-module-v0.14.2...charger-module-v0.14.3) (2026-09-12)

### Bug Fixes

* **charger-module:** fix over-lengthening ([d5f3325](https://github.com/mikesmitty/power-manifold/commit/d5f3325428ca8c6325a3c02bf032edbc2404a800))

## [0.14.2](https://github.com/mikesmitty/power-manifold/compare/charger-module-v0.14.1...charger-module-v0.14.2) (2026-09-12)

### Bug Fixes

* **charger-module:** lengthen board to match controller rj45 ([5b43e12](https://github.com/mikesmitty/power-manifold/commit/5b43e12cfefb464ba0d03fa251210a13d11a5c21))

## [0.14.1](https://github.com/mikesmitty/power-manifold/compare/charger-module-v0.14.0...charger-module-v0.14.1) (2026-09-09)

### Bug Fixes

* update silkscreen layouts ([2757ea4](https://github.com/mikesmitty/power-manifold/commit/2757ea4baf1f9aa8df29a75b820561f585450467))

## [0.14.0](https://github.com/mikesmitty/power-manifold/compare/charger-module-v0.13.1...charger-module-v0.14.0) (2026-09-08)

### Features

* **charger-module:** extend usb-c port past edge ([e271353](https://github.com/mikesmitty/power-manifold/commit/e271353d425fca21fc921e32f29cc6cd073b6d25))

## [0.13.1](https://github.com/mikesmitty/power-manifold/compare/charger-module-v0.13.0...charger-module-v0.13.1) (2026-09-02)

### Bug Fixes

* **charger-module:** switch to 5V vcc ([5735743](https://github.com/mikesmitty/power-manifold/commit/5735743172d4cc040109c1f3c75d42a167998cc3))

## [0.13.0](https://github.com/mikesmitty/power-manifold/compare/charger-module-v0.12.4...charger-module-v0.13.0) (2026-08-30)

### Features

* **charger-module:** update to new generation ([0f52f65](https://github.com/mikesmitty/power-manifold/commit/0f52f65b2d89ae45185e18c2af32f05ce7f673aa))

## [0.12.4](https://github.com/mikesmitty/power-manifold/compare/charger-module-v0.12.3...charger-module-v0.12.4) (2024-09-13)

### Bug Fixes

* add test points ([9edbec6](https://github.com/mikesmitty/power-manifold/commit/9edbec6dcbd2b263c12cf1538030ba3496ef3f8f))

## [0.12.3](https://github.com/mikesmitty/power-manifold/compare/charger-module-v0.12.2...charger-module-v0.12.3) (2024-09-13)

### Bug Fixes

* update led footprint ([9083066](https://github.com/mikesmitty/power-manifold/commit/9083066c1faf41cbb17a23f5e38a3fcbacb4b216))
* update mpq4242 index key ([9083066](https://github.com/mikesmitty/power-manifold/commit/9083066c1faf41cbb17a23f5e38a3fcbacb4b216))

## [0.12.2](https://github.com/mikesmitty/power-manifold/compare/charger-module-v0.12.1...charger-module-v0.12.2) (2024-09-11)

### Bug Fixes

* add qr code for serial numbers ([a93a0fc](https://github.com/mikesmitty/power-manifold/commit/a93a0fc2a96c003166c58c34e3ffadafc17fc278))

## [0.12.1](https://github.com/mikesmitty/power-manifold/compare/charger-module-v0.12.0...charger-module-v0.12.1) (2024-08-27)

### Bug Fixes

* correct rp2 usb pin order ([e97c896](https://github.com/mikesmitty/power-manifold/commit/e97c8969dffc31d6a5440ee4f5be9436ee78ae8e))

## [0.12.0](https://github.com/mikesmitty/power-manifold/compare/charger-module-v0.11.7...charger-module-v0.12.0) (2024-08-24)

### Features

* split i2c network ([f5c17fe](https://github.com/mikesmitty/power-manifold/commit/f5c17fe2180b5c9388dba73b8ee0f0641791acc8))

### Bug Fixes

* increase i2c pullup cap ([6f12598](https://github.com/mikesmitty/power-manifold/commit/6f125985b20211caa995e3b5c805009276087e4b))

## [0.11.7](https://github.com/mikesmitty/power-manifold/compare/charger-module-v0.11.6...charger-module-v0.11.7) (2024-08-20)

### Bug Fixes

* reference vout voltage divider to gndusb for accuracy ([1f7f8f2](https://github.com/mikesmitty/power-manifold/commit/1f7f8f28c6ba415994af95c0408771f9a2a85a8f))

## [0.11.6](https://github.com/mikesmitty/power-manifold/compare/charger-module-v0.11.5...charger-module-v0.11.6) (2024-08-11)

### Bug Fixes

* invert enable pin so output doesn't drop during mcu reset ([970bd8c](https://github.com/mikesmitty/power-manifold/commit/970bd8cd0c93e5491865c72c2ee6678852993903))

## [0.11.5](https://github.com/mikesmitty/power-manifold/compare/charger-module-v0.11.4...charger-module-v0.11.5) (2024-08-08)

### Bug Fixes

* move charger buttons ([9aaf8b0](https://github.com/mikesmitty/power-manifold/commit/9aaf8b0a4a00f143133bb757bf2bde2eb51de596))

## [0.11.4](https://github.com/mikesmitty/power-manifold/compare/charger-module-v0.11.3...charger-module-v0.11.4) (2024-08-01)

### Bug Fixes

* correct rp2 usb pin order ([d259270](https://github.com/mikesmitty/power-manifold/commit/d2592703c32c2d982217669368ba1caed00b513d))

## [0.11.3](https://github.com/mikesmitty/power-manifold/compare/charger-module-v0.11.2...charger-module-v0.11.3) (2024-07-23)

### Bug Fixes

* increase fuse to 8A to match input ([34cf64f](https://github.com/mikesmitty/power-manifold/commit/34cf64f5ec75cb4e9e9030e484891ce500b91830))

## [0.11.2](https://github.com/mikesmitty/power-manifold/compare/charger-module-v0.11.1...charger-module-v0.11.2) (2024-07-21)

### Bug Fixes

* open up path from usb gnd pins to plane ([735a073](https://github.com/mikesmitty/power-manifold/commit/735a073ddeeeeb4ab86238208ebdab3d418ca550))

## [0.11.1](https://github.com/mikesmitty/power-manifold/compare/charger-module-v0.11.0...charger-module-v0.11.1) (2024-07-11)

### Bug Fixes

* swap usb tvs diode to more available model ([c8b18fa](https://github.com/mikesmitty/power-manifold/commit/c8b18fa9c991078d95106d4458649c13adc903e4))

## [0.11.0](https://github.com/mikesmitty/power-manifold/compare/charger-module-v0.10.2...charger-module-v0.11.0) (2024-07-10)

### Features

* add gpio header to charger module ([4cbd2f3](https://github.com/mikesmitty/power-manifold/commit/4cbd2f3b8f6b9d3d9eb857e1141b53decd266e08))

## [0.10.2](https://github.com/mikesmitty/power-manifold/compare/charger-module-v0.10.1...charger-module-v0.10.2) (2024-07-10)

### Bug Fixes

* clean up traces ([181868f](https://github.com/mikesmitty/power-manifold/commit/181868fa257600ebbe6f0f09d60b0f0e6955dadc))

## [0.10.1](https://github.com/mikesmitty/pdusb/compare/charger-module-v0.10.0...charger-module-v0.10.1) (2024-07-10)

### Bug Fixes

* add via stitching to improve emc ([1808a28](https://github.com/mikesmitty/pdusb/commit/1808a28883a0908c73fe8574c44388933ec490f3))
* remove over-complicated USB switch ([b711b1c](https://github.com/mikesmitty/pdusb/commit/b711b1c423c8949ec734186f52588050cb6238bb))

## [0.10.0](https://github.com/mikesmitty/pdusb/compare/charger-module-v0.9.0...charger-module-v0.10.0) (2024-07-09)

### Features

* give vin 8 pins ([deeca54](https://github.com/mikesmitty/pdusb/commit/deeca54b5ecd7f126030e2663d6139264055c541))

### Bug Fixes

* correct i2c pin mismatch ([deeca54](https://github.com/mikesmitty/pdusb/commit/deeca54b5ecd7f126030e2663d6139264055c541))

## [0.9.0](https://github.com/mikesmitty/pdusb/compare/charger-module-v0.8.3...charger-module-v0.9.0) (2024-07-08)

### Features

* shrink charger module outline ([051fecc](https://github.com/mikesmitty/pdusb/commit/051fecc27901af27a6ce28e297dd4c0b121d335f))

## [0.8.3](https://github.com/mikesmitty/pdusb/compare/charger-module-v0.8.2...charger-module-v0.8.3) (2024-07-07)

### Bug Fixes

* fix opamp feedback resistor value ([51daa8c](https://github.com/mikesmitty/pdusb/commit/51daa8c1bc127483105343635c577d885270d42c))
* remove mosfet ([#30](https://github.com/mikesmitty/pdusb/issues/30)) ([f38021d](https://github.com/mikesmitty/pdusb/commit/f38021d279a5d4fb5c75b13646da387f04ae2dde))

## [0.8.2](https://github.com/mikesmitty/pdusb/compare/charger-module-v0.8.1...charger-module-v0.8.2) (2024-07-04)

### Bug Fixes

* fix incorrect part numbers ([7d5589f](https://github.com/mikesmitty/pdusb/commit/7d5589fe6c76b37504af899d7f41072b2987b070))

## [0.8.1](https://github.com/mikesmitty/pdusb/compare/charger-module-v0.8.0...charger-module-v0.8.1) (2024-07-04)

### Bug Fixes

* add rotation corrections ([#23](https://github.com/mikesmitty/pdusb/issues/23)) ([d28bfbb](https://github.com/mikesmitty/pdusb/commit/d28bfbb0f5f295293d51a52142758b1be5bae77d))

## [0.8.0](https://github.com/mikesmitty/pdusb/compare/charger-module-v0.7.1...charger-module-v0.8.0) (2024-07-04)

### Features

* add amplifier to current signal ([cd6c652](https://github.com/mikesmitty/pdusb/commit/cd6c6524c9f327b2ad43f052ae8103018f5e6368))

## [0.7.1](https://github.com/mikesmitty/pdusb/compare/charger-module-v0.7.0...charger-module-v0.7.1) (2024-07-03)

### Bug Fixes

* can't forget the pull-ups ([38f5258](https://github.com/mikesmitty/pdusb/commit/38f52583257ef937b0b6ace3cdfb33ebec99fc47))

## [0.7.0](https://github.com/mikesmitty/pdusb/compare/charger-module-v0.6.0...charger-module-v0.7.0) (2024-07-01)

### Features

* add swd circuits for firmware updates ([3fe7ef4](https://github.com/mikesmitty/pdusb/commit/3fe7ef4b14e35cb9b6d7b5f8920c50c7c5d31d5d))
* add swd lines to connector ([0cbfca7](https://github.com/mikesmitty/pdusb/commit/0cbfca78ad04f3e7deddfba9d1997bf1806fe2ab))
* add switch to access onboard rp2040 through charge plug ([3fe7ef4](https://github.com/mikesmitty/pdusb/commit/3fe7ef4b14e35cb9b6d7b5f8920c50c7c5d31d5d))
* add usb switch for rp2040 usb port ([0cbfca7](https://github.com/mikesmitty/pdusb/commit/0cbfca78ad04f3e7deddfba9d1997bf1806fe2ab))

## [0.6.0](https://github.com/mikesmitty/pdusb/compare/charger-module-v0.5.0...charger-module-v0.6.0) (2024-06-29)

### Features

* misc features ([#8](https://github.com/mikesmitty/pdusb/issues/8)) ([c4a45ae](https://github.com/mikesmitty/pdusb/commit/c4a45aea12a5c59c5742778317859835ea6f5bef))

## [0.5.0](https://github.com/mikesmitty/pdusb/compare/charger-module-v0.4.0...charger-module-v0.5.0) (2024-06-28)

### Features

* add charger module ([e0088c0](https://github.com/mikesmitty/pdusb/commit/e0088c0316c7c99f1039f19b1d478e8ac7130546))

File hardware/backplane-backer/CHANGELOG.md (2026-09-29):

# Changelog

## [0.1.3](https://github.com/mikesmitty/power-manifold/compare/backplane-backer-v0.1.2...backplane-backer-v0.1.3) (2026-09-29)

### Bug Fixes

* **backplane-backer:** grow hole sizes slightly for tolerance ([5b6fc3c](https://github.com/mikesmitty/power-manifold/commit/5b6fc3c94b758087b505e638e204a772534f242a))

## [0.1.2](https://github.com/mikesmitty/power-manifold/compare/backplane-backer-v0.1.1...backplane-backer-v0.1.2) (2026-09-29)

### Bug Fixes

* **backplane-backer:** shrink hole sizes ([385322c](https://github.com/mikesmitty/power-manifold/commit/385322c3abf75b8f666234886f1a72df2e8ec531))

## [0.1.1](https://github.com/mikesmitty/power-manifold/compare/backplane-backer-v0.1.0...backplane-backer-v0.1.1) (2026-09-26)

### Bug Fixes

* **backplane-backer:** remove unnecessary xt60 cutout ([02ce6db](https://github.com/mikesmitty/power-manifold/commit/02ce6dbb00e3ecc974c26f06874428e5774ed1c6))

## 0.1.0 (2026-09-26)

### Features

* **backplane-backer:** add insulating FR4 backer plate for the backplane ([270f96b](https://github.com/mikesmitty/power-manifold/commit/270f96b5e9fb53f86cd5a674b0bee51cc539571f))

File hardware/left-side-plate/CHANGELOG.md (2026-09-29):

# Changelog

## 0.1.0 (2026-09-27)

### Features

* **left-side-plate:** add new pcb ([092bdef](https://github.com/mikesmitty/power-manifold/commit/092bdef66f44a40eab04c211eab635cd49854fbe))

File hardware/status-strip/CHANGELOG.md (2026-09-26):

# Changelog

## [0.2.0](https://github.com/mikesmitty/power-manifold/compare/status-strip-v0.1.0...status-strip-v0.2.0) (2026-09-26)

### Features

* **status-strip:** add system-level status led ([002a226](https://github.com/mikesmitty/power-manifold/commit/002a226751bdb9b34a16c577363315968382bcb2))

## 0.1.0 (2026-09-26)

### Features

* **status-strip:** add front-panel status LED strip ([02db71b](https://github.com/mikesmitty/power-manifold/commit/02db71b6c51fa1c6e6eaa63d271bcc218026c967))

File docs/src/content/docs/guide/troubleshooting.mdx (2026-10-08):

---
title: Troubleshooting
description: What a red light, a problem warning or a port that won't power a device means, and what to do about it.
sidebar:
  order: 8
---

import { Aside } from '@astrojs/starlight/components';
import SymptomFinder from '../../../components/SymptomFinder.astro';

Start with what you see:

<SymptomFinder />

## Where problems show up

When something needs attention, Power Manifold says so in several places:

- a red line near the top of the [web interface](/guide/web-interface/);
- the **Problem** sensor in Home Assistant, whose `detail` attribute says
  what is wrong;
- the lights: a red, fast-blinking light for a port that faulted, the
  chassis light (left of port 1) blinking red when the input voltage is out
  of range, and the chassis light breathing red when there's no network.

The web interface's **Fault log** keeps a history of past faults.

## A port blinks red

The port shut itself off to protect your device or the blade. The usual
causes are a device drawing more current than the port offers, a short
in the cable or device, or a blade that got too hot. The fault log entry
says which one.

The port tries again by itself after 5 seconds. If the cause is still there,
it faults again, and the light keeps blinking.

What to try:

1. Unplug the device, wait for the light to turn white, and plug it back in.
2. Try a different cable. A damaged cable is a common cause.
3. If the log says *plug-hot* or *converter-hot*, check that nothing blocks
   the vents, especially the fan's on the right side, and that the fan is
   on **auto**. Let it cool down.
4. If the same device faults on every port, the device is the problem.

## A device doesn't charge, or charges slowly

- **Light white with the device plugged in:** the port doesn't see the
  device. Reseat the cable at both ends, or try another cable. Some cheap
  USB-A to USB-C adapters and cables don't work with USB-C chargers.
- **Light off:** the port is switched off. Turn it on with the switch on its card on the
  [web interface](/guide/web-interface/#the-port-cards) or in Home Assistant.
  If you didn't switch it off, check whether
  [switch off once charged or the sleep timer](/guide/port-settings/#switching-off-when-charged)
  is on, or whether the port is set to stay **off** at power-up.
- **Light pulsing slowly:** the port is turned down because the chassis is
  at its budget. See [Sharing power](/guide/sharing-power/).
- **Laptop charges slower than expected:** check the port's
  [voltage cap and current limit](/guide/port-settings/#voltage-cap).
  Laptops need 20 V, and more than 60 W needs a 5 A cable.

## Ports capped at 3 A

The problem line says *bus voltage sagging, ports capped at 3 A*. The input
voltage from your power supply fell below 20 V, so every port was limited
to 60 W to take load off it. It lifts by itself 30 seconds after the
voltage recovers.

If it happens often:

- your supply is too small for your devices, so lower the
  [budget](/guide/sharing-power/#the-budget) to match it, or
  use a bigger supply;
- or the cable from the supply is too long or too thin, so use a shorter,
  thicker one.

If the voltage keeps falling, Power Manifold disconnects all ports at
about 17.7 V and reconnects them when the voltage returns. The fault log
records the low voltage.

## Bus voltage out of range

The chassis light, left of port 1, blinks red, and the problem line says
*bus voltage low* or *bus voltage high*. The input voltage from your power
supply is outside Power Manifold's rating of 24 V +20 %/−15 %. The ports keep
their power, but check the power supply, its output setting and its cable.
The light goes back to dim green once the voltage is back in range.

## A port shows *silent* or *not answering*

The blade stopped responding to the controller. The port keeps its power
and the controller keeps asking. The readings you see are the last ones it
got. This usually clears by itself. If it doesn't, switch the port off and
on again. If that doesn't help, switch the power supply off and on again.

## No network

The chassis light, left of port 1, breathing red means the controller has
no network address.

- **Wi-Fi:** check that the network is up. After five minutes off the
  network the controller opens Wi-Fi setup, so you can
  [enter new Wi-Fi details](/setup/wifi-provisioning/) if
  your network changed.
- **Ethernet:** check the cable and that your router hands out addresses.
  If you set a fixed address, check that it is still free and correct.

The ports keep working with no network. Only the web interface, Home Assistant
and the API are unavailable.

## Can't reach the web interface

- Try the IP address from your router instead of `pwrman.local`. Some
  networks and older Android phones don't resolve `.local` names.
- If you renamed the device, the address is `http://<new-name>.local/`.
- With [HTTPS](/integrations/https/) on, use the name on the certificate.
  If that name no longer resolves, open the controller by its IP address
  and accept the browser's warning that the certificate is for another
  name. From there you can install a new certificate, or set **HTTPS** to
  *Off* in **Settings**.

## Forgot the API token

You can't recover the token. To set a new one, do a
[factory reset](/guide/front-panel/#the-button) and repeat
[first-time setup](/setup/first-time-setup/). If you have a
settings export that includes secrets, you can import it after the reset.

## Other problems the controller reports

| Message | What it means |
| --- | --- |
| *trial firmware uncommitted* | A firmware update is on trial. It clears within a few seconds when the update succeeds. See [Updates](/guide/updates/). |
| *wired link down* | The Ethernet cable is unplugged or the switch is off. Wi-Fi is carrying traffic for now. |
| *on battery* / UPS battery fault | Your [UPS power supply](/integrations/ups/) lost AC power or reports a battery problem. |
| *bus voltage* out of range | The input voltage is outside the rated range. See [Bus voltage out of range](#bus-voltage-out-of-range). |
| *HTTPS certificate expires in N days* / *expired* | The certificate renewal has stopped. Check the acme.sh or certbot job. See [HTTPS](/integrations/https/#expiry). |
| *HTTPS on but no certificate* | The stored certificate is missing or does not load, so the controller serves plain HTTP. Install it again. |

<Aside type="tip" title="Reporting a problem">
[Open an issue](https://github.com/mikesmitty/power-manifold/issues) with a
settings export (without secrets) and the fault log.
</Aside>

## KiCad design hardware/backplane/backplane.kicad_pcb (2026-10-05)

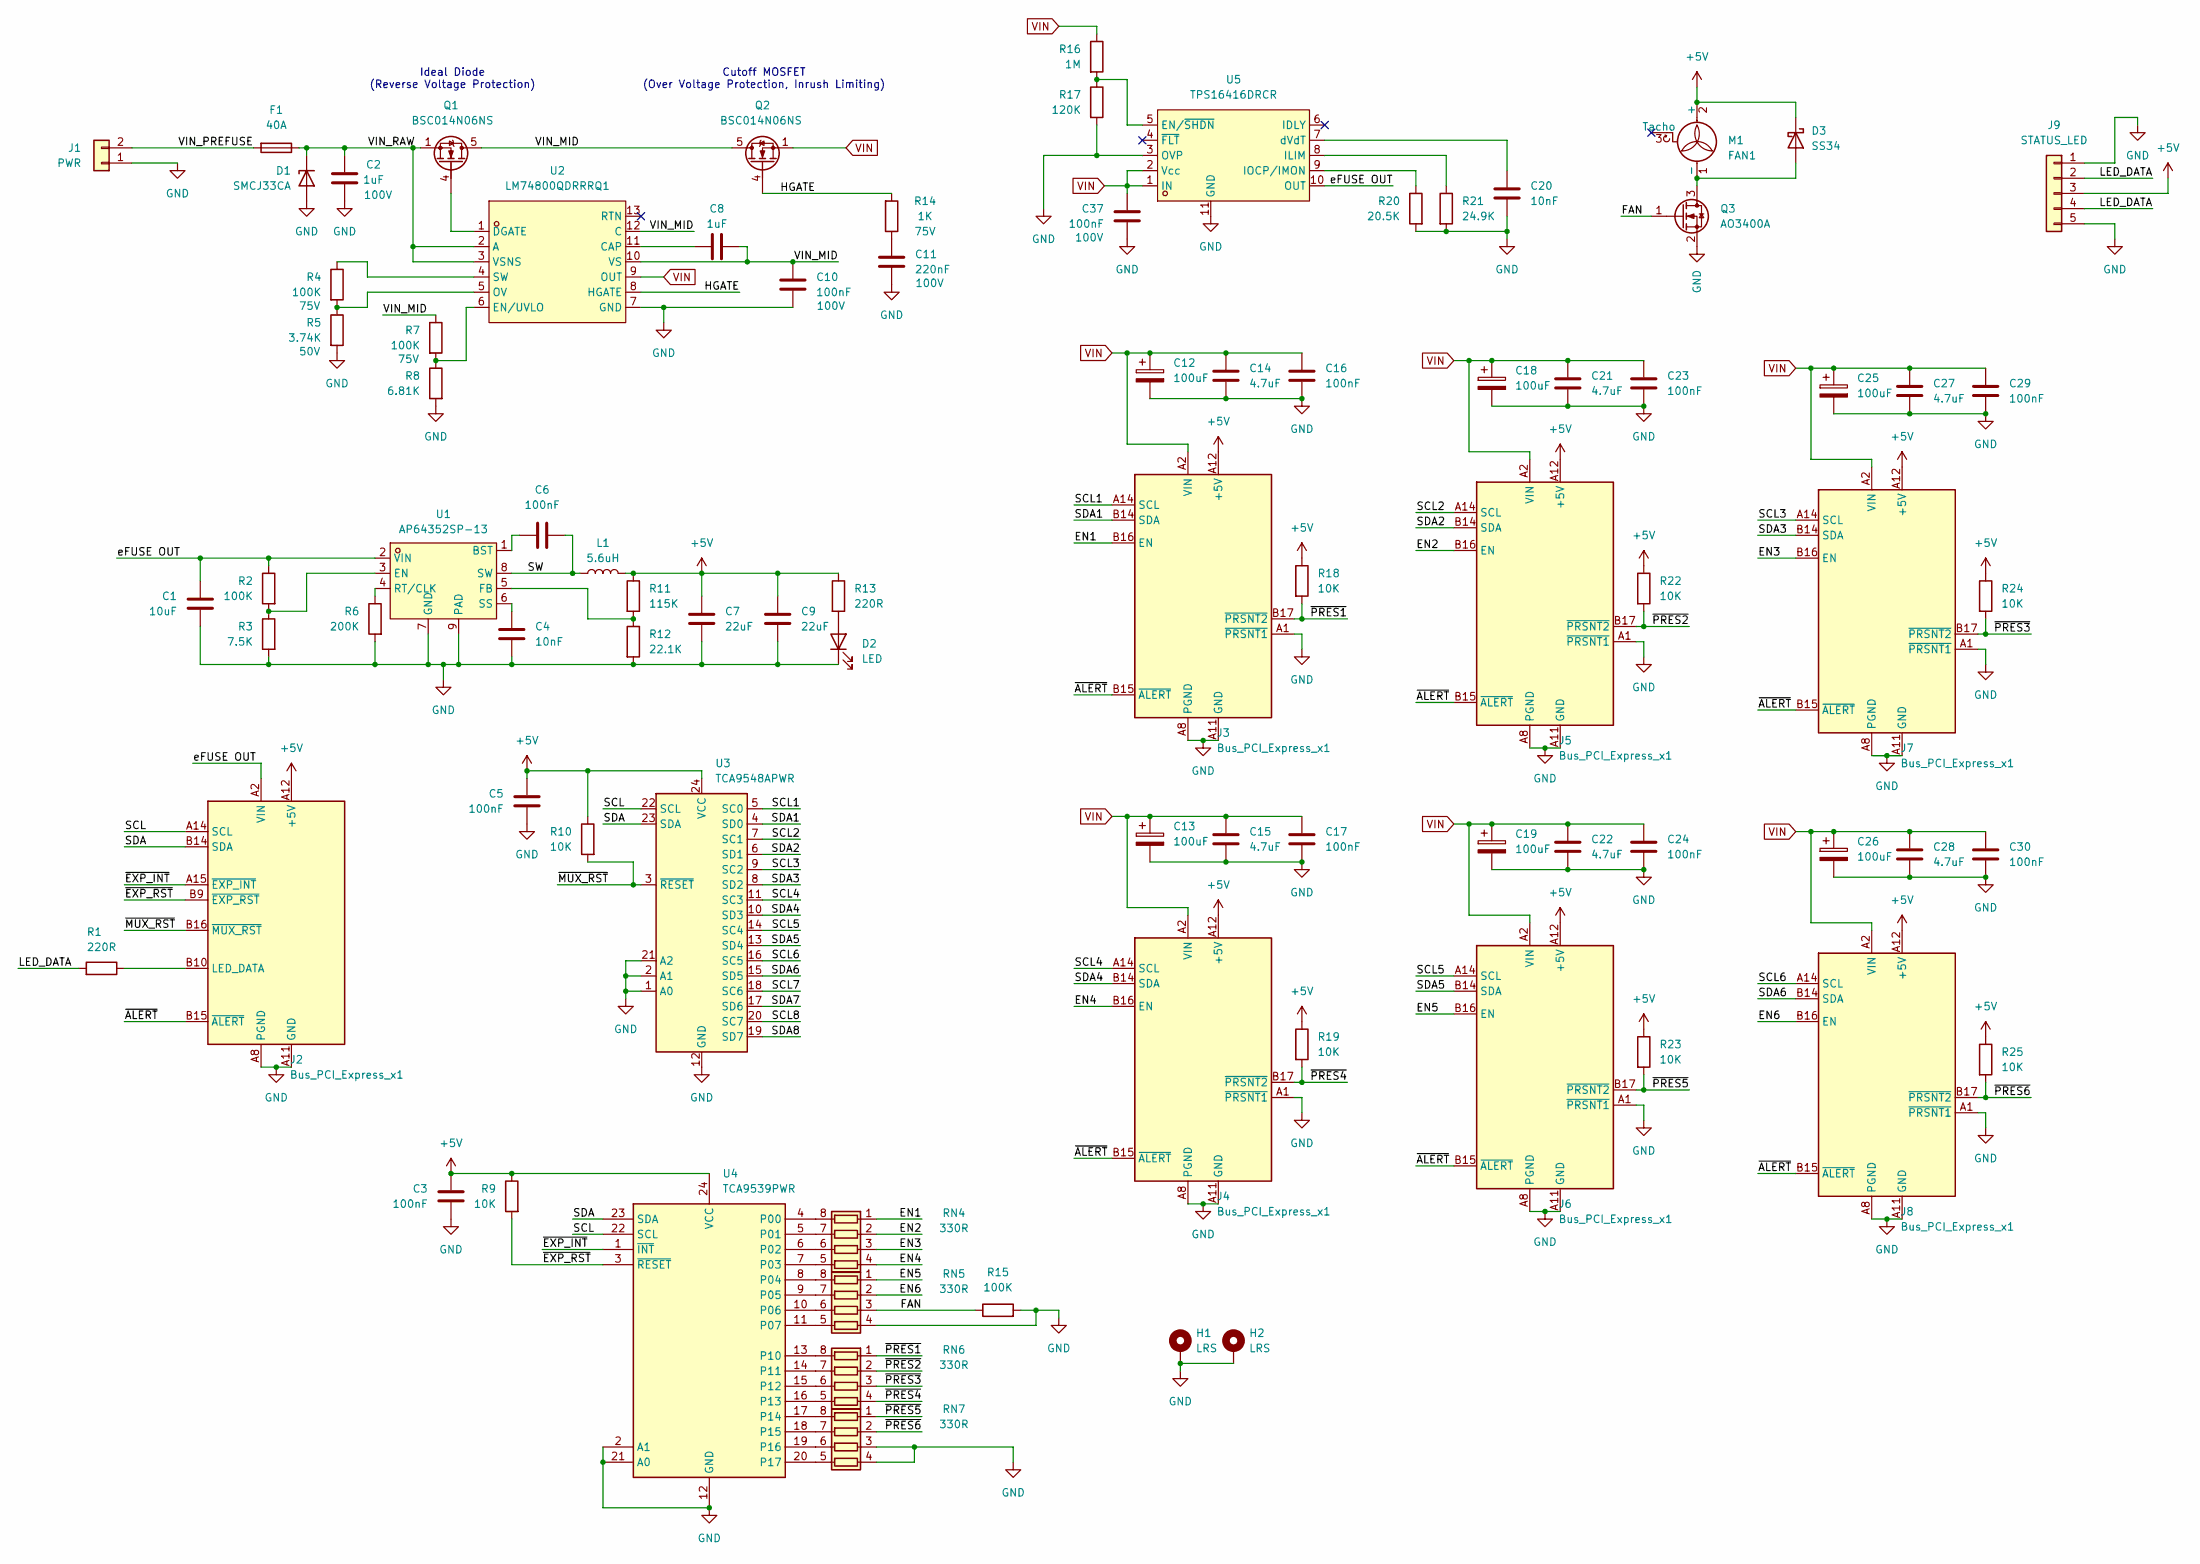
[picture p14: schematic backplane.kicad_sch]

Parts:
C1: 10uF; C_0805_2012Metric; LCSC C440198
C2: 1uF; C_0805_2012Metric; Voltage 100V; LCSC C5370002
C3, C5, C6, C16, C17, C23, C24, C29, C30: 100nF; C_0402_1005Metric; LCSC C307331
C4, C20: 10nF; C_0402_1005Metric; LCSC C15195
C7, C9: 22uF; C_0805_2012Metric; LCSC C45783
C8: 1uF; C_0402_1005Metric; LCSC C52923
C10, C37: 100nF; C_0603_1608Metric; Voltage 100V; LCSC C88219
C11: 220nF; C_0805_2012Metric; Voltage 100V; LCSC C513710
C12, C13, C18, C19, C25, C26: 100uF; CP_Elec_6.3x7.7; LCSC C3151829
C14, C15, C21, C22, C27, C28: 4.7uF; C_1206_3216Metric; LCSC C29823
D1: SMCJ33CA; D_SMC; LCSC C310048
D2: LED; LED_0603_1608Metric; LCSC C2286
D3: SS34; D_SMA; LCSC C8678
F1: 40A; FUSE-SMD_L6.1-W2.5; LCSC C2762486
H1, H2: LRS; MountingHole_4.3mm_M4_Pad_Via
J1: PWR; AMASS_XT60PW-M_1x02_P7.20mm_Horizontal; LCSC C98732
J2, J3, J4, J5, J6, J7, J8: Bus_PCI_Express_x1; AMPHENOL_PCI_E_10018783-10210TLF; LCSC C4693418
J9: STATUS_LED; JST_SH_BM05B-SRSS-TB_1x05-1MP_P1.00mm_Vertical; LCSC C160391
L1: 5.6uH; L_Sunlord_MWSA0603S; LCSC C408448
M1: FAN1; FanPinHeader_1x03_P2.54mm_Vertical; LCSC C234181
Q1, Q2: BSC014N06NS; Infineon_PG-TDSON-8_6.15x5.15mm; LCSC C113391
Q3: AO3400A; SOT-23; LCSC C20917
R1, R13: 220R; R_0402_1005Metric; LCSC C25091
R2, R15: 100K; R_0402_1005Metric; LCSC C25741
R3: 7.5K; R_0402_1005Metric; LCSC C25918
R4, R7: 100K; R_0603_1608Metric; Voltage 75V; LCSC C25803
R5: 3.74K; R_0402_1005Metric; Voltage 50V; LCSC C15172
R6: 200K; R_0402_1005Metric; LCSC C25764
R8: 6.81K; R_0603_1608Metric; LCSC C2930121
R9, R10, R18, R19, R22, R23, R24, R25: 10K; R_0402_1005Metric; LCSC C25744
R11: 115K; R_0402_1005Metric; LCSC C25747
R12: 22.1K; R_0402_1005Metric; LCSC C163478
R14: 1K; R_0603_1608Metric; Voltage 75V; LCSC C21190
R16: 1M; R_0603_1608Metric; LCSC C22935
R17: 120K; R_0603_1608Metric; LCSC C25808
R20: 20.5K; R_0402_1005Metric; LCSC C57105
R21: 24.9K; R_0402_1005Metric; LCSC C25874
RN4, RN5, RN6, RN7: 330R; R_Array_Concave_4x0402; LCSC C43557
U1: AP64352SP-13; Diodes_SO-8EP; LCSC C2071665
U2: LM74800QDRRRQ1; WSON-12_L3.0-W3.0-P0.50-TL-EP-2; LCSC C3215600
U3: TCA9548APWR; TSSOP-24_4.4x7.8mm_P0.65mm; LCSC C130026
U4: TCA9539PWR; TSSOP-24_4.4x7.8mm_P0.65mm; LCSC C131972
U5: TPS16416DRCR; VSON-10_L3.0-W3.0-P0.50-TL-EP; MPN TPS16416DRCR; LCSC C22433503

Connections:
+5V: C3.1, C5.1, C7.1, C9.1, D3.1 (K), J2.A12 (+5V), J2.B12 (+5V), J3.A12 (+5V), J3.B12 (+5V), J4.A12 (+5V), J4.B12 (+5V), J5.A12 (+5V), J5.B12 (+5V), J6.A12 (+5V), J6.B12 (+5V), J7.A12 (+5V), J7.B12 (+5V), J8.A12 (+5V), J8.B12 (+5V), J9.3, L1.2, M1.2 (+), R9.1, R10.1, R11.1, R13.1, R18.1, R19.1, R22.1, R23.1, R24.1, R25.1, U3.24 (VCC), U4.24 (VCC)
/EN1: J3.B16 (EN), RN4.1 (R1.1)
/EN2: J5.B16 (EN), RN4.2 (R2.1)
/EN3: J7.B16 (EN), RN4.3 (R3.1)
/EN4: J4.B16 (EN), RN4.4 (R4.1)
/EN5: J6.B16 (EN), RN5.1 (R1.1)
/EN6: J8.B16 (EN), RN5.2 (R2.1)
/FAN: Q3.1 (G), R15.1, RN5.3 (R3.1)
/HGATE: Q2.4 (G), R14.2, U2.8 (HGATE)
/LED_DATA: J9.2, J9.4, R1.2
/SCL: J2.A14 (SCL), U3.22 (SCL), U4.22 (SCL)
/SCL1: J3.A14 (SCL), U3.5 (SC0)
/SCL2: J5.A14 (SCL), U3.7 (SC1)
/SCL3: J7.A14 (SCL), U3.9 (SC2)
/SCL4: J4.A14 (SCL), U3.11 (SC3)
/SCL5: J6.A14 (SCL), U3.14 (SC4)
/SCL6: J8.A14 (SCL), U3.16 (SC5)
/SCL7: U3.18 (SC6)
/SCL8: U3.20 (SC7)
/SDA: J2.B14 (SDA), U3.23 (SDA), U4.23 (SDA)
/SDA1: J3.B14 (SDA), U3.4 (SD0)
/SDA2: J5.B14 (SDA), U3.6 (SD1)
/SDA3: J7.B14 (SDA), U3.8 (SD2)
/SDA4: J4.B14 (SDA), U3.10 (SD3)
/SDA5: J6.B14 (SDA), U3.13 (SD4)
/SDA6: J8.B14 (SDA), U3.15 (SD5)
/SDA7: U3.17 (SD6)
/SDA8: U3.19 (SD7)
/SW: C6.2, L1.1, U1.8 (SW)
/VIN_MID: C8.2, C10.1, Q1.5 (D), Q2.5 (D), R7.1, U2.10 (VS), U2.12 (C)
/VIN_PREFUSE: F1.2, J1.2
/VIN_RAW: C2.1, D1.1 (K), F1.1, Q1.1 (S), Q1.2 (S), Q1.3 (S), U2.2 (A), U2.3 (VSNS)
/eFUSE OUT: C1.1, J2.A2 (VIN), J2.A3 (VIN), J2.A4 (VIN), J2.A5 (VIN), J2.A6 (VIN), J2.A7 (VIN), R2.1, U1.2 (VIN), U5.10 (OUT)
/~ALERT: J2.B15 (~ALERT), J3.B15 (~ALERT), J4.B15 (~ALERT), J5.B15 (~ALERT), J6.B15 (~ALERT), J7.B15 (~ALERT), J8.B15 (~ALERT)
/~EXP_INT: J2.A15 (~EXP_INT), U4.1 (~INT)
/~EXP_RST: J2.B9 (~EXP_RST), R9.2, U4.3 (~RESET)
/~MUX_RST: J2.B16 (~MUX_RST), R10.2, U3.3 (~RESET)
/~PRES1: J3.B17 (~PRSNT2), R18.2, RN6.1 (R1.1)
/~PRES2: J5.B17 (~PRSNT2), R22.2, RN6.2 (R2.1)
/~PRES3: J7.B17 (~PRSNT2), R24.2, RN6.3 (R3.1)
/~PRES4: J4.B17 (~PRSNT2), R19.2, RN6.4 (R4.1)
/~PRES5: J6.B17 (~PRSNT2), R23.2, RN7.1 (R1.1)
/~PRES6: J8.B17 (~PRSNT2), R25.2, RN7.2 (R2.1)
GND: C1.2, C2.2, C3.2, C4.1, C5.2, C7.2, C9.2, C10.2, C11.2, C12.2, C13.2, C14.2, C15.2, C16.2, C17.2, C18.2, C19.2, C20.1, C21.2, C22.2, C23.2, C24.2, C25.2, C26.2, C27.2, C28.2, C29.2, C30.2, C37.2, D1.2 (A), D2.1 (K), H1.1 (1_1), H2.1 (1_1), J1.1, J2.A1 (GND), J2.A8 (PGND), J2.A9 (PGND), J2.A10 (PGND), J2.A11 (GND), J2.A13 (GND), J2.A16 (GND), J2.A17 (GND), J2.A18 (GND), J2.B1 (PGND), J2.B2 (PGND), J2.B3 (PGND), J2.B4 (PGND), J2.B5 (PGND), J2.B6 (PGND), J2.B7 (PGND), J2.B8 (PGND), J2.B11 (GND), J2.B13 (GND), J2.B17 (GND), J2.B18 (GND), J3.A1 (~PRSNT1), J3.A8 (PGND), J3.A9 (PGND), J3.A10 (PGND), J3.A11 (GND), J3.A13 (GND), J3.A15 (GND), J3.A16 (GND), J3.A17 (GND), J3.A18 (GND), J3.B1 (PGND), J3.B2 (PGND), J3.B3 (PGND), J3.B4 (PGND), J3.B5 (PGND), J3.B6 (PGND), J3.B7 (PGND), J3.B8 (PGND), J3.B9 (PGND), J3.B10 (GND), J3.B11 (GND), J3.B13 (GND), J3.B18 (GND), J4.A1 (~PRSNT1), J4.A8 (PGND), J4.A9 (PGND), J4.A10 (PGND), J4.A11 (GND), J4.A13 (GND), J4.A15 (GND), J4.A16 (GND), J4.A17 (GND), J4.A18 (GND), J4.B1 (PGND), J4.B2 (PGND), J4.B3 (PGND), J4.B4 (PGND), J4.B5 (PGND), J4.B6 (PGND), J4.B7 (PGND), J4.B8 (PGND), J4.B9 (PGND), J4.B10 (GND), J4.B11 (GND), J4.B13 (GND), J4.B18 (GND), J5.A1 (~PRSNT1), J5.A8 (PGND), J5.A9 (PGND), J5.A10 (PGND), J5.A11 (GND), J5.A13 (GND), J5.A15 (GND), J5.A16 (GND), J5.A17 (GND), J5.A18 (GND), J5.B1 (PGND), J5.B2 (PGND), J5.B3 (PGND), J5.B4 (PGND), J5.B5 (PGND), J5.B6 (PGND), J5.B7 (PGND), J5.B8 (PGND), J5.B9 (PGND), J5.B10 (GND), J5.B11 (GND), J5.B13 (GND), J5.B18 (GND), J6.A1 (~PRSNT1), J6.A8 (PGND), J6.A9 (PGND), J6.A10 (PGND), J6.A11 (GND), J6.A13 (GND), J6.A15 (GND), J6.A16 (GND), J6.A17 (GND), J6.A18 (GND), J6.B1 (PGND), J6.B2 (PGND), J6.B3 (PGND), J6.B4 (PGND), J6.B5 (PGND), J6.B6 (PGND), J6.B7 (PGND), J6.B8 (PGND), J6.B9 (PGND), J6.B10 (GND), J6.B11 (GND), J6.B13 (GND), J6.B18 (GND), J7.A1 (~PRSNT1), J7.A8 (PGND), J7.A9 (PGND), J7.A10 (PGND), J7.A11 (GND), J7.A13 (GND), J7.A15 (GND), J7.A16 (GND), J7.A17 (GND), J7.A18 (GND), J7.B1 (PGND), J7.B2 (PGND), J7.B3 (PGND), J7.B4 (PGND), J7.B5 (PGND), J7.B6 (PGND), J7.B7 (PGND), J7.B8 (PGND), J7.B9 (PGND), J7.B10 (GND), J7.B11 (GND), J7.B13 (GND), J7.B18 (GND), J8.A1 (~PRSNT1), J8.A8 (PGND), J8.A9 (PGND), J8.A10 (PGND), J8.A11 (GND), J8.A13 (GND), J8.A15 (GND), J8.A16 (GND), J8.A17 (GND), J8.A18 (GND), J8.B1 (PGND), J8.B2 (PGND), J8.B3 (PGND), J8.B4 (PGND), J8.B5 (PGND), J8.B6 (PGND), J8.B7 (PGND), J8.B8 (PGND), J8.B9 (PGND), J8.B10 (GND), J8.B11 (GND), J8.B13 (GND), J8.B18 (GND), J9.1, J9.5, Q3.2 (S), R3.2, R5.2, R6.2, R8.2, R12.2, R15.2, R17.2, R20.2, R21.2, RN5.4 (R4.1), RN7.3 (R3.1), RN7.4 (R4.1), U1.7 (GND), U1.9 (PAD), U2.7 (GND), U3.1 (A0), U3.2 (A1), U3.12 (GND), U3.21 (A2), U4.2 (A1), U4.12 (GND), U4.21 (A0), U5.3 (OVP), U5.11 (GND)
unnamed: C11.1, R14.1
unnamed: D2.2 (A), R13.2
unnamed: D3.2 (A), M1.1 (-), Q3.3 (D)
unnamed: J2.B10 (LED_DATA), R1.1
unnamed: Q1.4 (G), U2.1 (DGATE)
unnamed: RN4.8 (R1.2), U4.4 (P00)
unnamed: RN4.7 (R2.2), U4.5 (P01)
unnamed: RN4.6 (R3.2), U4.6 (P02)
unnamed: RN4.5 (R4.2), U4.7 (P03)
unnamed: RN5.8 (R1.2), U4.8 (P04)
unnamed: RN5.7 (R2.2), U4.9 (P05)
unnamed: RN5.6 (R3.2), U4.10 (P06)
unnamed: RN5.5 (R4.2), U4.11 (P07)
unnamed: RN6.8 (R1.2), U4.13 (P10)
unnamed: RN6.7 (R2.2), U4.14 (P11)
unnamed: RN6.6 (R3.2), U4.15 (P12)
unnamed: RN6.5 (R4.2), U4.16 (P13)
unnamed: RN7.8 (R1.2), U4.17 (P14)
unnamed: RN7.7 (R2.2), U4.18 (P15)
unnamed: RN7.6 (R3.2), U4.19 (P16)
unnamed: RN7.5 (R4.2), U4.20 (P17)
unnamed: C6.1, U1.1 (BST)
unnamed: R2.2, R3.1, U1.3 (EN)
unnamed: R11.2, R12.1, U1.5 (FB)
unnamed: R6.1, U1.4 (RT/CLK)
unnamed: C4.2, U1.6 (SS)
unnamed: C8.1, U2.11 (CAP)
unnamed: R7.2, R8.1, U2.6 (EN/UVLO)
unnamed: R4.2, R5.1, U2.5 (OV)
unnamed: R4.1, U2.4 (SW)
unnamed: R16.2, R17.1, U5.5 (EN/~SHDN)
unnamed: R21.1, U5.8 (ILIM)
unnamed: R20.1, U5.9 (IOCP/IMON)
unnamed: C20.2, U5.7 (dVdT)
VIN: C12.1, C13.1, C14.1, C15.1, C16.1, C17.1, C18.1, C19.1, C21.1, C22.1, C23.1, C24.1, C25.1, C26.1, C27.1, C28.1, C29.1, C30.1, C37.1, J3.A2 (VIN), J3.A3 (VIN), J3.A4 (VIN), J3.A5 (VIN), J3.A6 (VIN), J3.A7 (VIN), J4.A2 (VIN), J4.A3 (VIN), J4.A4 (VIN), J4.A5 (VIN), J4.A6 (VIN), J4.A7 (VIN), J5.A2 (VIN), J5.A3 (VIN), J5.A4 (VIN), J5.A5 (VIN), J5.A6 (VIN), J5.A7 (VIN), J6.A2 (VIN), J6.A3 (VIN), J6.A4 (VIN), J6.A5 (VIN), J6.A6 (VIN), J6.A7 (VIN), J7.A2 (VIN), J7.A3 (VIN), J7.A4 (VIN), J7.A5 (VIN), J7.A6 (VIN), J7.A7 (VIN), J8.A2 (VIN), J8.A3 (VIN), J8.A4 (VIN), J8.A5 (VIN), J8.A6 (VIN), J8.A7 (VIN), Q2.1 (S), Q2.2 (S), Q2.3 (S), R16.1, U2.9 (OUT), U5.1 (IN), U5.2 (Vcc)

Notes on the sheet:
Ideal Diode (Reverse Voltage Protection)
Cutoff MOSFET (Over Voltage Protection, Inrush Limiting)

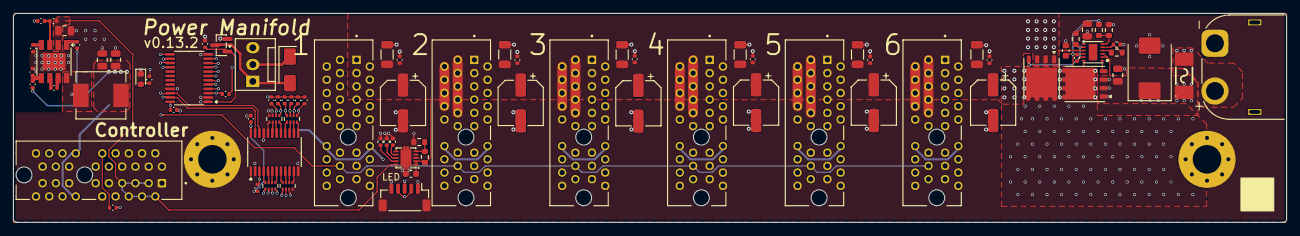
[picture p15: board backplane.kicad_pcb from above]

Board: 4 copper layers, 192.0 x 31.5 mm, 85 parts (0 on the bottom side), 75 nets.

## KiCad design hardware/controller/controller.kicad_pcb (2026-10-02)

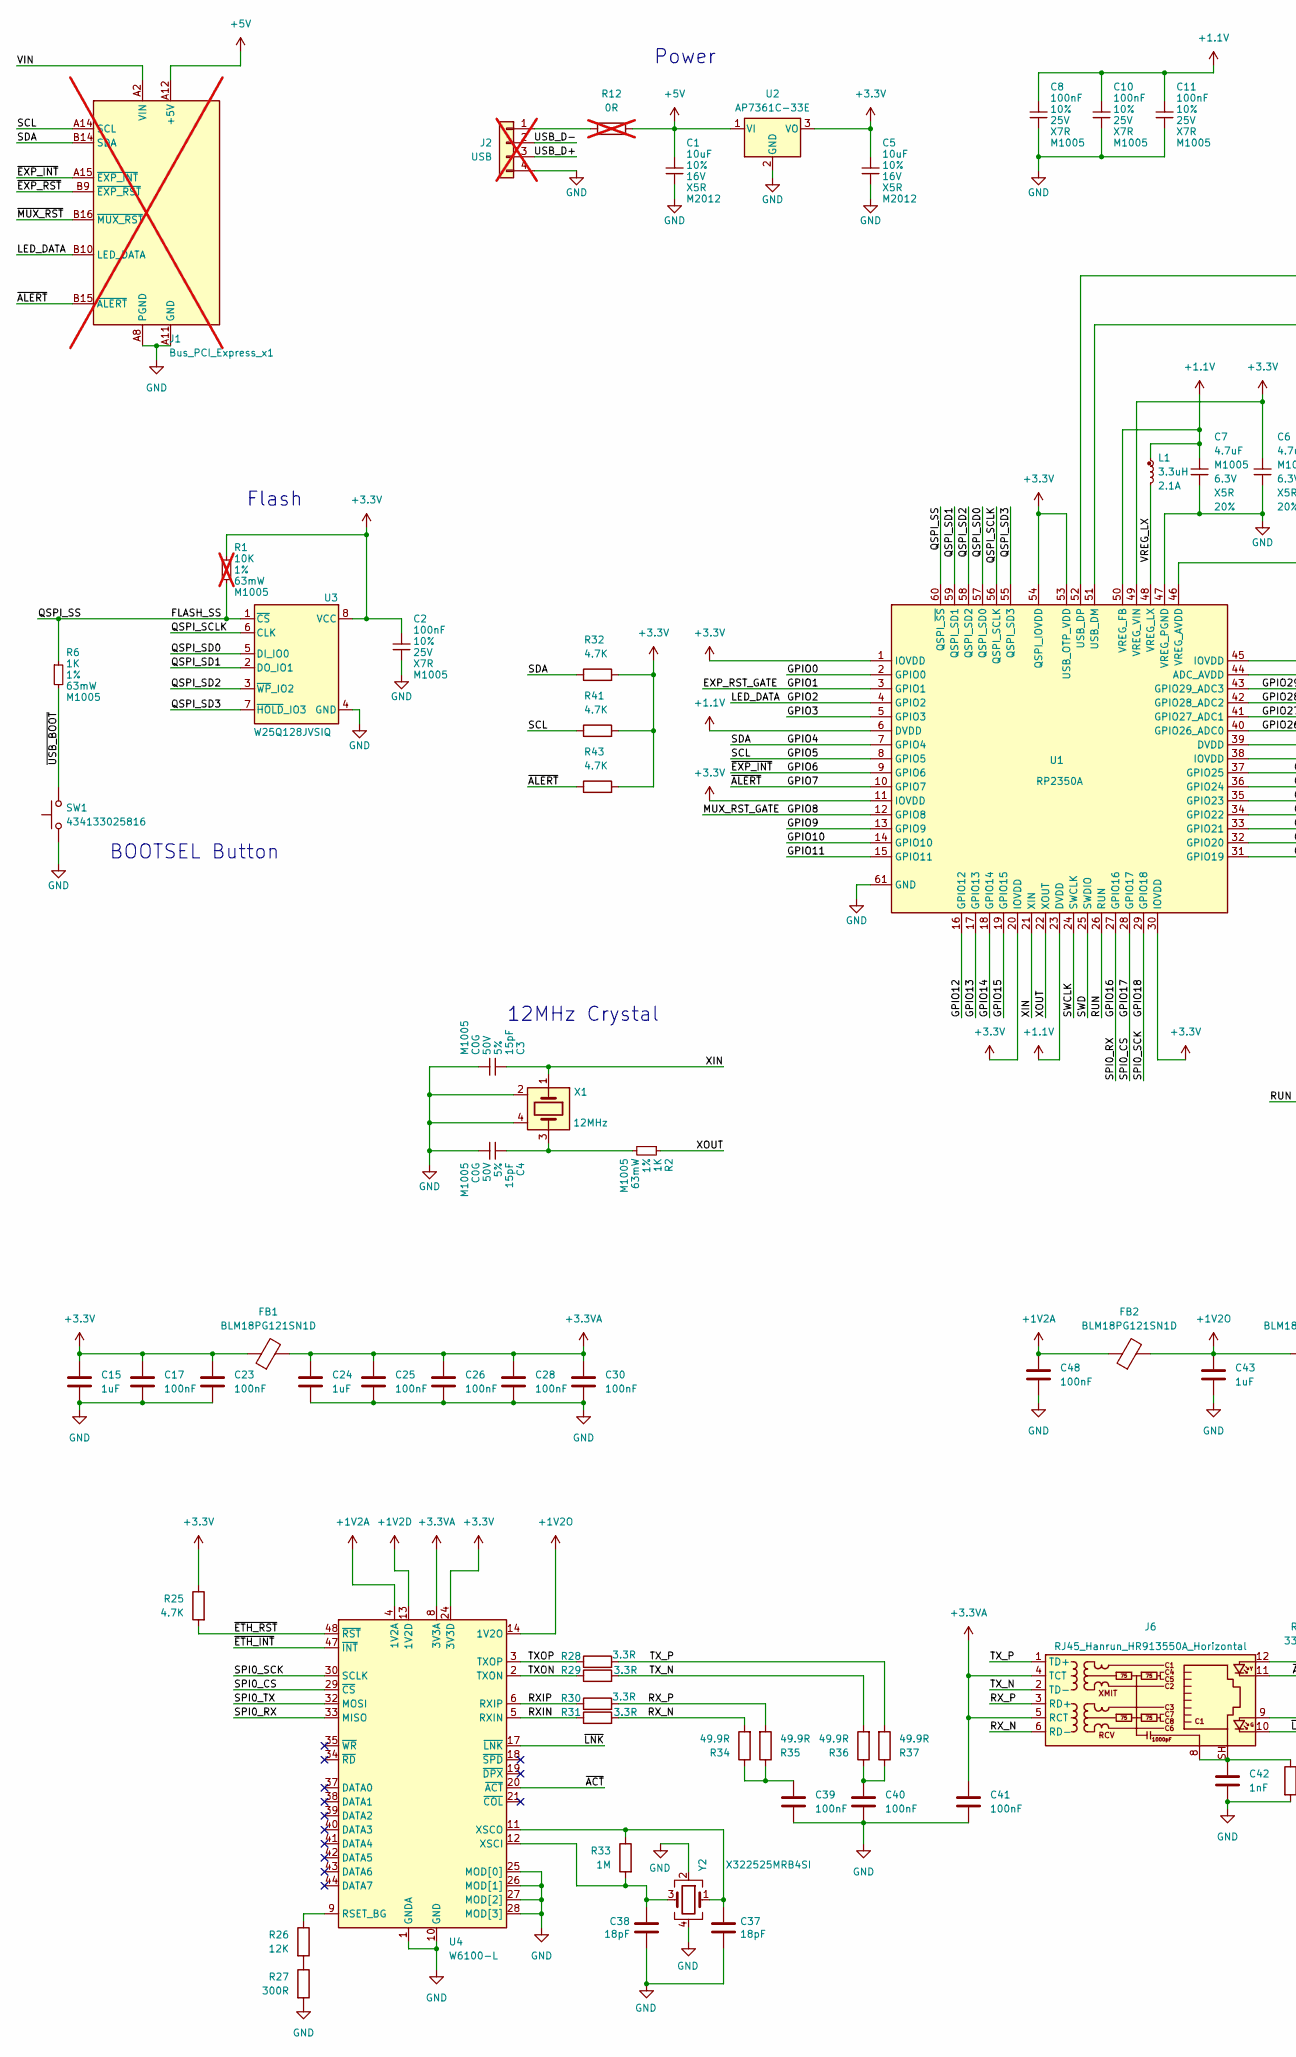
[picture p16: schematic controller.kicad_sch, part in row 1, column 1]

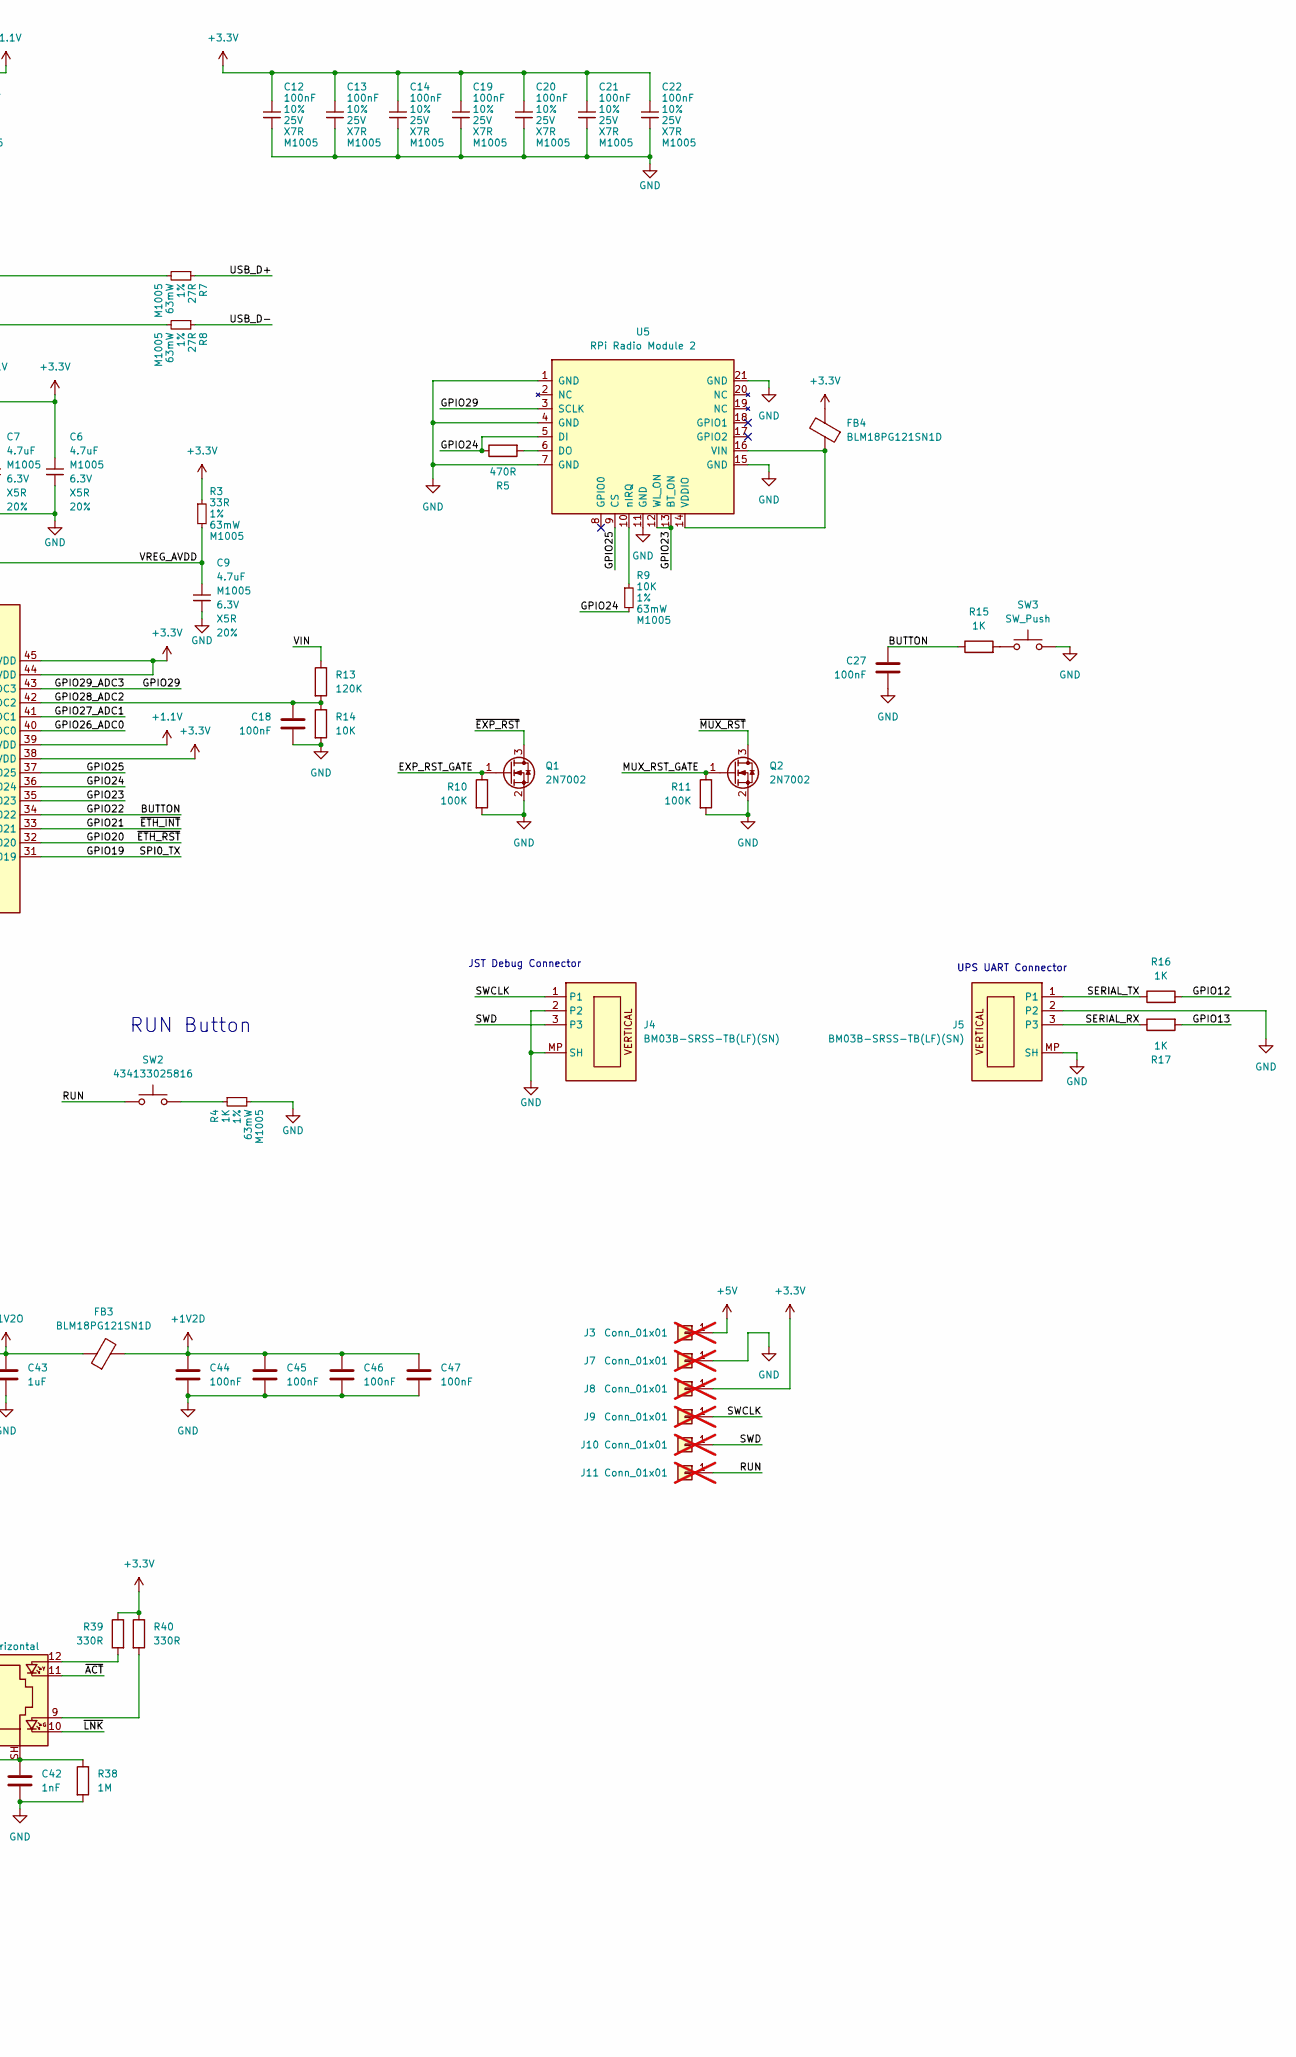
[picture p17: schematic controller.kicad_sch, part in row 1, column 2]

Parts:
C1, C5: 10uF; C_0805_2012Metric; voltage 16V; tolerance 10%; part_uid RP-01GYSK-AVBE41; LCSC C1713
C2, C8, C10, C11, C12, C13, C14, C19, C20, C21, C22: 100nF; C_0402_1005Metric; voltage 25V; tolerance 10%; part_uid RP-01BJ9Y-KRGF41; LCSC C307331
C3, C4: 15pF; C_0402_1005Metric; voltage 50V; tolerance 5%; part_uid RP-01C89W-LLY9XV; LCSC C1548
C6, C7: 4.7uF; C_0402_Wide; voltage 6.3V; tolerance 20%; part_uid RP-019A1P-0C2GHY; LCSC C23733
C9: 4.7uF; C_0402_1005Metric; voltage 6.3V; tolerance 20%; part_uid RP-019A1P-0C2GHY; LCSC C23733
C15, C24, C43: 1uF; C_0402_1005Metric; LCSC C52923
C17, C18, C23, C25, C26, C27, C28, C30, C39, C40, C41, C44, C45, C46, C47, C48: 100nF; C_0402_1005Metric; LCSC C307331
C37, C38: 18pF; C_0402_1005Metric; LCSC C1549
C42: 1nF; C_1206_3216Metric; LCSC C9196
FB1, FB2, FB3, FB4: BLM18PG121SN1D; L_0603_1608Metric; LCSC C14709
J1: Bus_PCI_Express_x1; BUS_PCIexpress_x1; not fitted
J2: USB; PinHeader_1x04_P2.54mm_Vertical; not fitted
J3, J7, J8, J9, J10, J11: Conn_01x01; TestPoint_Pad_D1.5mm; not fitted
J4, J5: BM03B-SRSS-TB(LF)(SN); JST_SH_BM03B-SRSS-TB_1x03-1MP_P1.00mm_Vertical; manufacturer_pn BM03B-SRSS-TB(LF)(SN); LCSC C160389
J6: RJ45_Hanrun_HR913550A_Horizontal; RJ45_Hanrun_HR911105A_Horizontal; LCSC C163507
L1: 3.3uH; L_pol_2016; tolerance 20%; part_uid RP-01GY5D-2VC7WP; LCSC C42411119
Q1, Q2: 2N7002; SOT-23; LCSC C8545
R1: 10K; R_0402_1005Metric; tolerance 1%; voltage 50V; part_uid RP-019A1P-53DHSX; not fitted
R2, R4, R6: 1K; R_0402_1005Metric; tolerance 1%; voltage 50V; part_uid RP-019A1P-4Z6ZWY; LCSC C11702
R3: 33R; R_0402_1005Metric; tolerance 1%; voltage 50V; part_uid RP-019A1P-58PW9L; LCSC C25105
R5: 470R; R_0402_1005Metric; LCSC C25117
R7, R8: 27R; R_0402_1005Metric; tolerance 1%; voltage 50V; part_uid RP-01C89V-LTEYC4; LCSC C25100
R9: 10K; R_0402_1005Metric; tolerance 1%; voltage 50V; part_uid RP-019A1P-53DHSX; LCSC C25744
R10, R11: 100K; R_0402_1005Metric; LCSC C25741
R12: 0R; R_0603_1608Metric; not fitted
R13: 120K; R_0603_1608Metric; LCSC C25808
R14: 10K; R_0402_1005Metric; LCSC C25744
R15, R16, R17: 1K; R_0402_1005Metric; LCSC C11702
R25, R32, R41, R43: 4.7K; R_0402_1005Metric; LCSC C25900
R26: 12K; R_0402_1005Metric; Tolerance 1%; LCSC C25752
R27: 300R; R_0402_1005Metric; LCSC C25102
R28, R29, R30, R31: 3.3R; R_0402_1005Metric; LCSC C2933094
R33: 1M; R_0402_1005Metric; LCSC C26083
R34, R35, R36, R37: 49.9R; R_0402_1005Metric; LCSC C25120
R38: 1M; R_1206_3216Metric; LCSC C17927
R39, R40: 330R; R_0402_1005Metric; LCSC C25104
SW1, SW2: 434133025816; SW_Push_1P1T_NO_Vertical_Wuerth_434133025816; part_uid RP-01H0MT-6E9H8F; LCSC C5504987
SW3: SW_Push; SW_SPST_B3U-3000P; LCSC C963349
U1: RP2350A; QFN-60-1EP_7x7mm_P0.4mm_EP3.4x3.4mm_ThermalVias; part_uid RP-01HA9H-9K5E8T; LCSC C42411118
U2: AP7361C-33E; SOT-223-3_TabPin2; LCSC C500795
U3: W25Q128JVSIQ; SOIC-8_5.3x5.3mm_P1.27mm; voltage 2.7-3.6V; part_uid RP-01JWD4-F1H4N9; LCSC C97521
U4: W6100-L; LQFP-48_7x7mm_P0.5mm; LCSC C911393
U5: RPi Radio Module 2; RMC20452T; LCSC C49451547
X1: 12MHz; Crystal_SMD_Abracon_ABM8AIG-4Pin_3.2x2.5mm; tolerance 30ppm; part_uid RP-01G8X7-GS352B; LCSC C20625731
Y2: X322525MRB4SI; Crystal_SMD_3225-4Pin_3.2x2.5mm; LCSC C70593

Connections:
+1.1V: C7.1, C8.1, C10.1, C11.1, L1.1, U1.6 (DVDD), U1.23 (DVDD), U1.39 (DVDD), U1.50 (VREG_FB)
+1V2A: C48.1, FB2.1, U4.4 (1V2A)
+1V2D: C44.1, C45.1, C46.1, C47.1, FB3.2, U4.13 (1V2D), U4.22 (1V2D), U4.31 (1V2D), U4.45 (1V2D)
+1V2O: C43.1, FB2.2, FB3.1, U4.14 (1V2O)
+3.3V: C2.1, C5.1, C6.1, C12.1, C13.1, C14.1, C15.1, C17.1, C19.1, C20.1, C21.1, C22.1, C23.1, FB1.1, FB4.2, J8.1 (Pin_1_1), R1.1, R3.1, R25.1, R32.2, R39.1, R40.1, R41.2, R43.2, U1.1 (IOVDD), U1.11 (IOVDD), U1.20 (IOVDD), U1.30 (IOVDD), U1.38 (IOVDD), U1.44 (ADC_AVDD), U1.45 (IOVDD), U1.49 (VREG_VIN), U1.53 (USB_OTP_VDD), U1.54 (QSPI_IOVDD), U2.3 (VO), U3.8 (VCC), U4.24 (3V3D), U4.36 (3V3D)
+3.3VA: C24.1, C25.1, C26.1, C28.1, C30.1, C41.1, FB1.2, J6.4 (TCT), J6.5 (RCT), U4.8 (3V3A), U4.15 (3V3A)
+5V: C1.1, J1.A12 (+5V), J1.B12 (+5V), J3.1 (Pin_1_1), R12.2, U2.1 (VI)
/BUTTON: C27.1, R15.1, U1.34 (GPIO22)
/EXP_RST_GATE: Q1.1 (G), R10.1, U1.3 (GPIO1)
/FLASH_SS: R1.2, R6.1, U1.60 (QSPI_~SS), U3.1 (~CS)
/GPIO0: U1.2 (GPIO0)
/GPIO2: J1.B10 (LED_DATA), U1.4 (GPIO2)
/GPIO3: U1.5 (GPIO3)
/GPIO4: J1.B14 (SDA), R32.1, U1.7 (GPIO4)
/GPIO5: J1.A14 (SCL), R41.1, U1.8 (GPIO5)
/GPIO6: J1.A15 (~EXP_INT), U1.9 (GPIO6)
/GPIO7: J1.B15 (~ALERT), R43.1, U1.10 (GPIO7)
/GPIO8: Q2.1 (G), R11.1, U1.12 (GPIO8)
/GPIO9: U1.13 (GPIO9)
/GPIO10: U1.14 (GPIO10)
/GPIO11: U1.15 (GPIO11)
/GPIO12: R16.2, U1.16 (GPIO12)
/GPIO13: R17.2, U1.17 (GPIO13)
/GPIO14: U1.18 (GPIO14)
/GPIO15: U1.19 (GPIO15)
/GPIO16: U1.27 (GPIO16), U4.33 (MISO)
/GPIO17: U1.28 (GPIO17), U4.29 (~CS)
/GPIO18: U1.29 (GPIO18), U4.30 (SCLK)
/GPIO19: U1.31 (GPIO19), U4.32 (MOSI)
/GPIO20: R25.2, U1.32 (GPIO20), U4.48 (~RST)
/GPIO21: U1.33 (GPIO21), U4.47 (~INT)
/GPIO23: U1.35 (GPIO23), U5.12 (WL_ON), U5.13 (BT_ON)
/GPIO24: R5.1, R9.2, U1.36 (GPIO24), U5.5 (DI)
/GPIO25: U1.37 (GPIO25), U5.9 (CS)
/GPIO26_ADC0: U1.40 (GPIO26_ADC0)
/GPIO27_ADC1: U1.41 (GPIO27_ADC1)
/GPIO28_ADC2: C18.1, R13.2, R14.1, U1.42 (GPIO28_ADC2)
/GPIO29: U1.43 (GPIO29_ADC3), U5.3 (SCLK)
/QSPI_SCLK: U1.56 (QSPI_SCLK), U3.6 (CLK)
/QSPI_SD0: U1.57 (QSPI_SD0), U3.5 (DI_IO0)
/QSPI_SD1: U1.59 (QSPI_SD1), U3.2 (DO_IO1)
/QSPI_SD2: U1.58 (QSPI_SD2), U3.3 (~WP_IO2)
/QSPI_SD3: U1.55 (QSPI_SD3), U3.7 (~HOLD_IO3)
/RUN: J11.1 (Pin_1_1), SW2.2, U1.26 (RUN)
/RXIN: R31.1, U4.5 (RXIN)
/RXIP: R30.1, U4.6 (RXIP)
/RX_N: J6.6 (RD-), R31.2, R34.2
/RX_P: J6.3 (RD+), R30.2, R35.2
/SERIAL_RX: J5.3, R17.1
/SERIAL_TX: J5.1, R16.1
/SWCLK: J4.1, J9.1 (Pin_1_1), U1.24 (SWCLK)
/SWD: J4.3, J10.1 (Pin_1_1), U1.25 (SWDIO)
/TXON: R29.1, U4.2 (TXON)
/TXOP: R28.1, U4.3 (TXOP)
/TX_N: J6.2 (TD-), R29.2, R36.2
/TX_P: J6.1 (TD+), R28.2, R37.2
/USB_D+: J2.3, R7.1
/USB_D-: J2.2, R8.1
/VIN: J1.A2 (VIN), J1.A3 (VIN), J1.A4 (VIN), J1.A5 (VIN), J1.A6 (VIN), J1.A7 (VIN), R13.1
/VREG_AVDD: C9.1, R3.2, U1.46 (VREG_AVDD)
/VREG_LX: L1.2, U1.48 (VREG_LX)
/XIN: C3.1, U1.21 (XIN), X1.1
/XOUT: R2.1, U1.22 (XOUT)
/~ACT: J6.11, U4.20 (~ACT)
/~EXP_RST: J1.B9 (~EXP_RST), Q1.3 (D)
/~LNK: J6.10, U4.17 (~LNK)
/~MUX_RST: J1.B16 (~MUX_RST), Q2.3 (D)
/~USB_BOOT: R6.2, SW1.2
GND: C1.2, C2.2, C3.2, C4.2, C5.2, C6.2, C7.2, C8.2, C9.2, C10.2, C11.2, C12.2, C13.2, C14.2, C15.2, C17.2, C18.2, C19.2, C20.2, C21.2, C22.2, C23.2, C24.2, C25.2, C26.2, C27.2, C28.2, C30.2, C37.2, C38.2, C39.2, C40.2, C41.2, C42.2, C43.2, C44.2, C45.2, C46.2, C47.2, C48.2, J1.A1 (GND), J1.A8 (PGND), J1.A9 (PGND), J1.A10 (PGND), J1.A11 (GND), J1.A13 (GND), J1.A16 (GND), J1.A17 (GND), J1.A18 (GND), J1.B1 (PGND), J1.B2 (PGND), J1.B3 (PGND), J1.B4 (PGND), J1.B5 (PGND), J1.B6 (PGND), J1.B7 (PGND), J1.B8 (PGND), J1.B11 (GND), J1.B13 (GND), J1.B17 (GND), J1.B18 (GND), J2.4, J4.2, J4.MP (SH), J5.2, J5.MP (SH), J7.1 (Pin_1_1), Q1.2 (S), Q2.2 (S), R4.2, R10.2, R11.2, R14.2, R27.2, R38.2, SW1.1, SW3.2, U1.47 (VREG_PGND), U1.61 (GND), U2.2 (GND), U3.4 (GND), U4.1 (GNDA), U4.7 (GNDA), U4.10 (GND), U4.16 (GNDA), U4.23 (GND), U4.25 (MOD[0]), U4.26 (MOD[1]), U4.27 (MOD[2]), U4.28 (MOD[3]), U4.46 (GND), U5.1 (GND), U5.4 (GND), U5.7 (GND), U5.11 (GND), U5.15 (GND), U5.21 (GND), X1.2, X1.4, Y2.2, Y2.4
unnamed: C4.1, R2.2, X1.3
unnamed: C39.1, R34.1, R35.1
unnamed: C40.1, R36.1, R37.1
unnamed: C42.1, J6.8, J6.SH, R38.1
unnamed: J2.1, R12.1
unnamed: J6.9, R40.2
unnamed: J6.12, R39.2
unnamed: R4.1, SW2.1
unnamed: R15.2, SW3.1
unnamed: R26.2, R27.1
unnamed: R8.2, U1.51 (USB_DM)
unnamed: R7.2, U1.52 (USB_DP)
unnamed: R26.1, U4.9 (RSET_BG)
unnamed: C38.1, R33.2, U4.12 (XSCI), Y2.3
unnamed: C37.1, R33.1, U4.11 (XSCO), Y2.1
unnamed: R5.2, U5.6 (DO)
unnamed: FB4.1, U5.14 (VDDIO), U5.16 (VIN)
unnamed: R9.1, U5.10 (nIRQ)

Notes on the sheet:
12MHz Crystal
RUN Button
Flash
BOOTSEL Button
JST Debug Connector
UPS UART Connector
Power

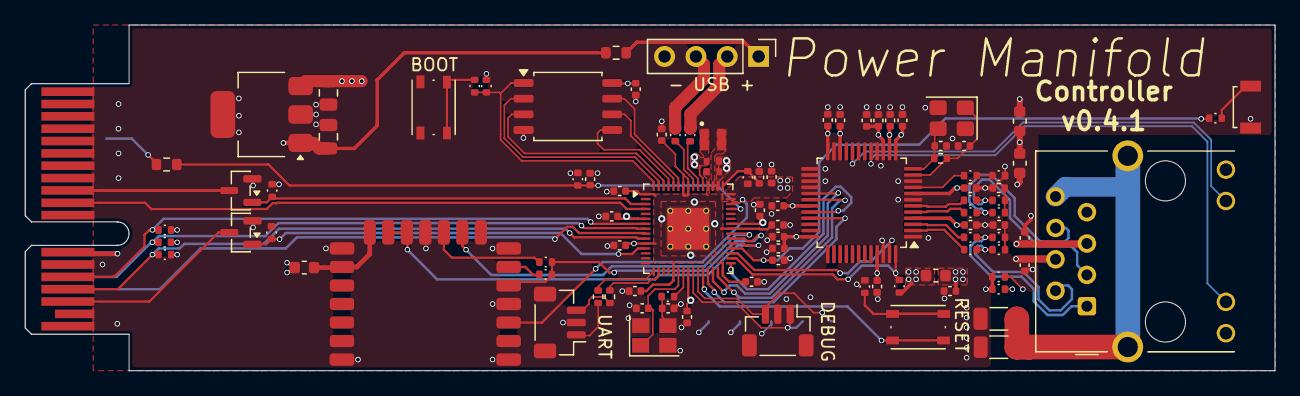
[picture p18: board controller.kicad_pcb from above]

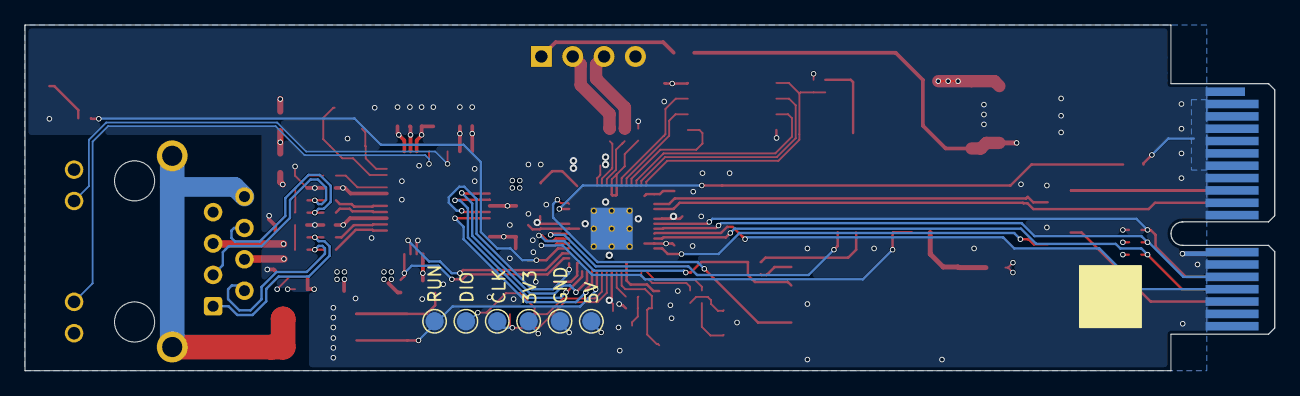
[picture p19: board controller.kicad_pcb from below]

Board: 4 copper layers, 101.2 x 28.0 mm, 103 parts (6 on the bottom side), 78 nets.

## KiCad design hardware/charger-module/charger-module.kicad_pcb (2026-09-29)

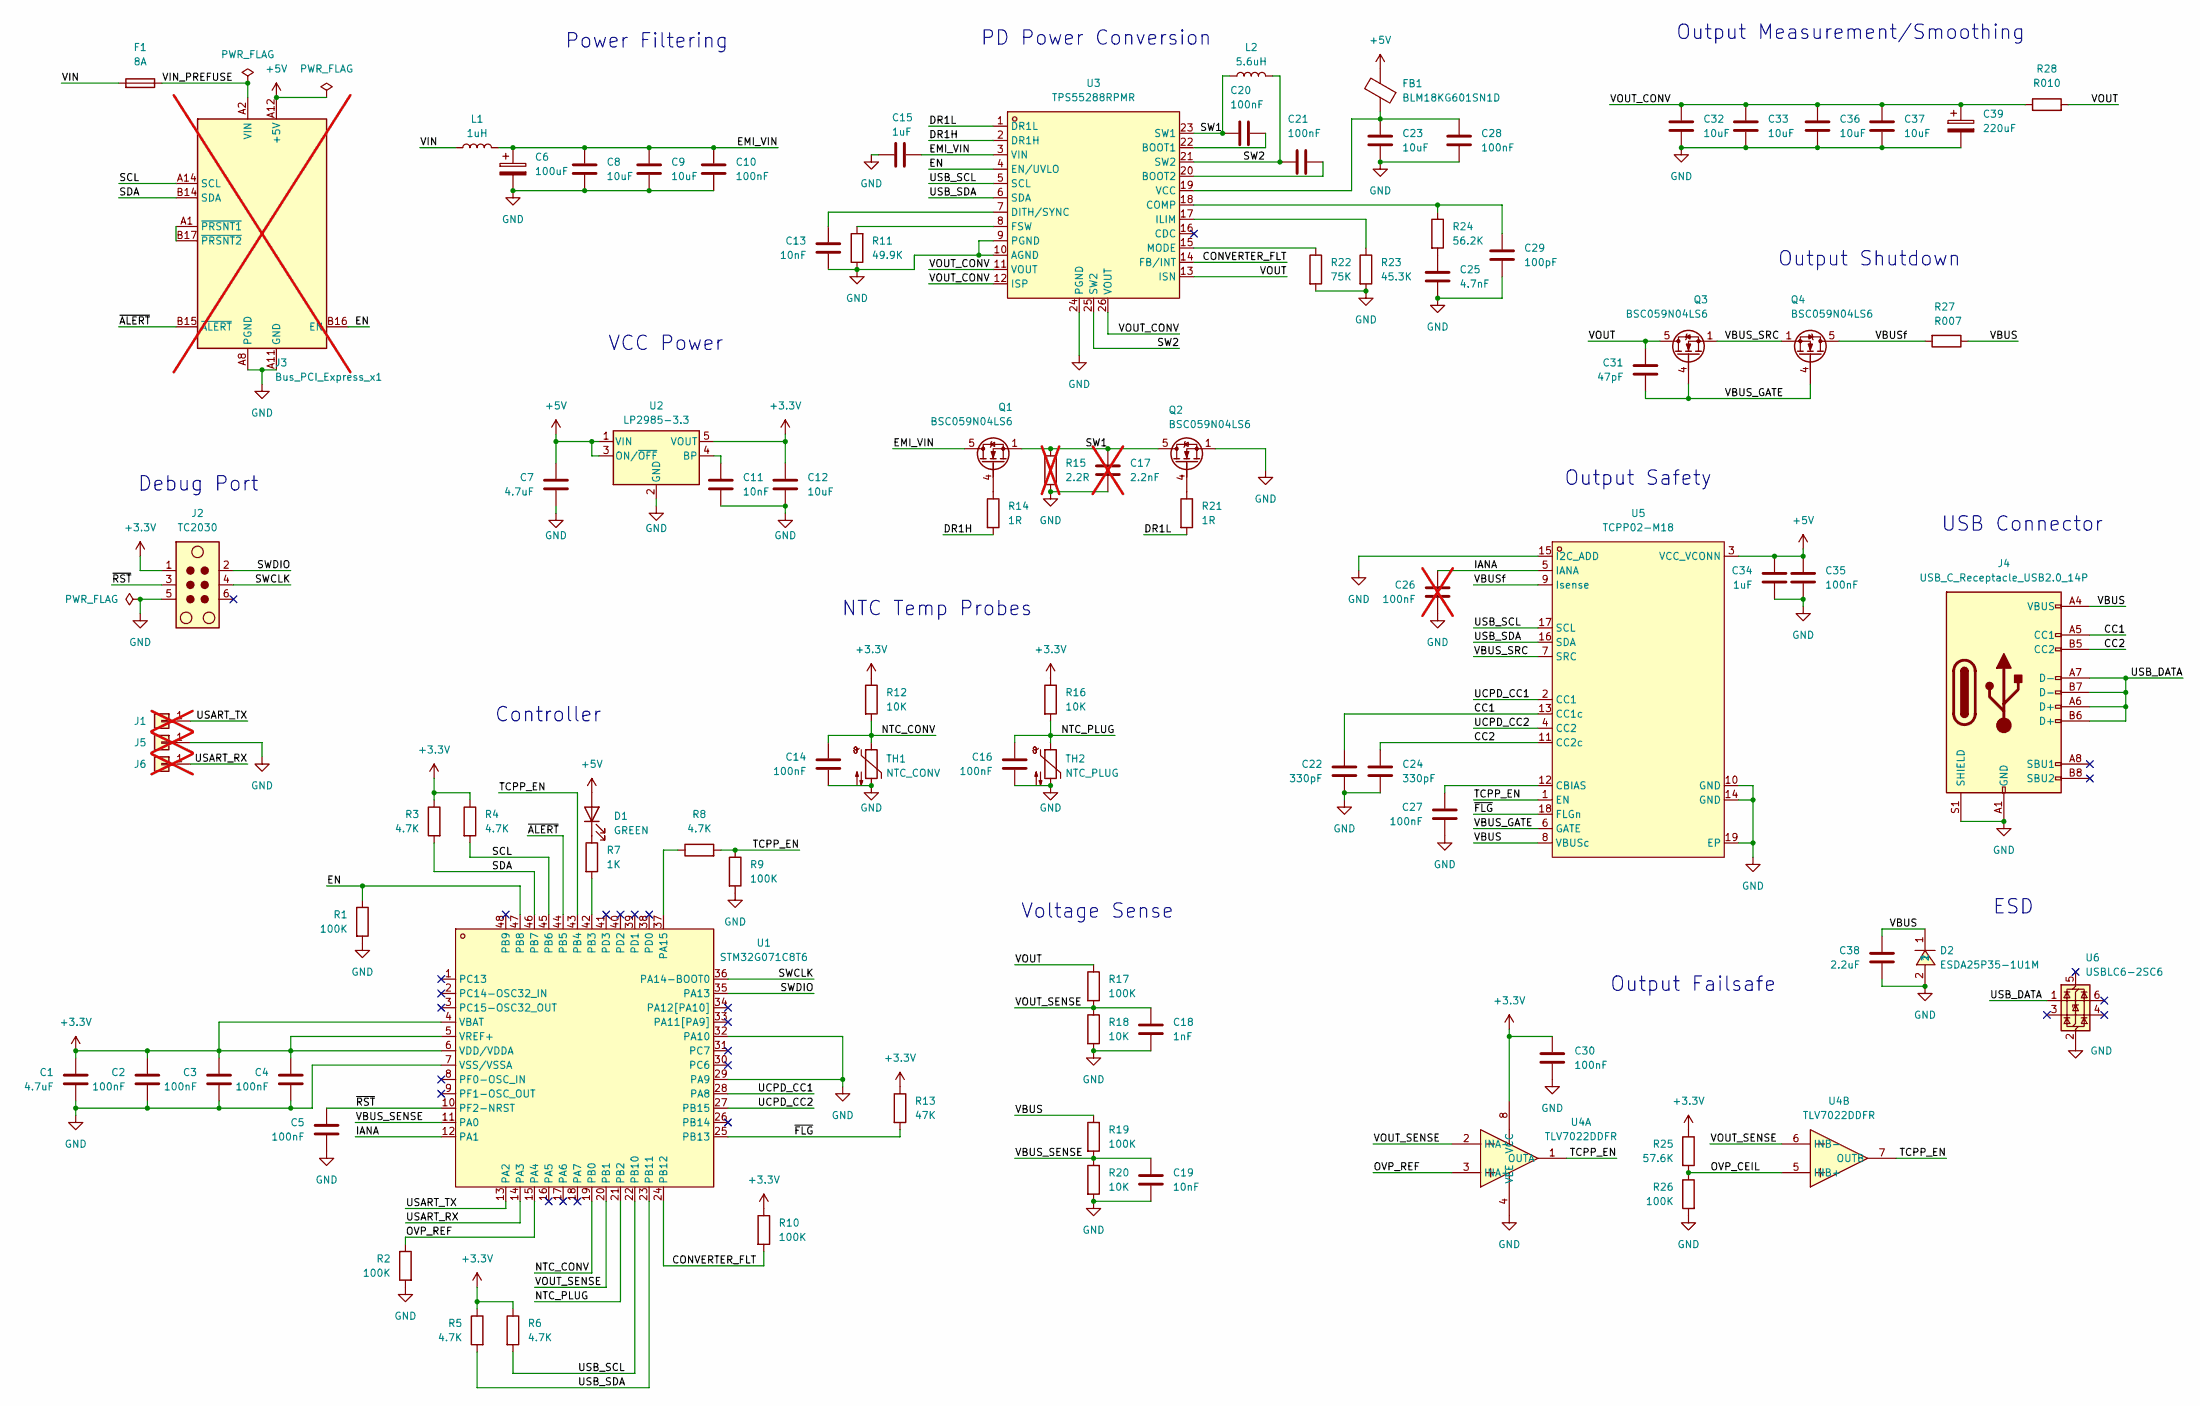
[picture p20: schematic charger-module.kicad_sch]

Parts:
C1, C7: 4.7uF; C_0603_1608Metric; LCSC C108342
C2, C3, C4, C5, C10, C14, C16, C27, C28, C30, C35: 100nF; C_0402_1005Metric; LCSC C307331
C6: 100uF; CP_Elec_6.3x7.7; LCSC C3151829
C8, C9, C32, C33, C36, C37: 10uF; C_1206_3216Metric; LCSC C89632
C11, C13, C19: 10nF; C_0402_1005Metric; LCSC C15195
C12: 10uF; C_0805_2012Metric; LCSC C95841
C15, C34: 1uF; C_0603_1608Metric; LCSC C5199872
C17: 2.2nF; C_0805_2012Metric; Voltage 100V; LCSC C49956; not fitted
C18: 1nF; C_0402_1005Metric; LCSC C1523
C20, C21: 100nF; C_0402_1005Metric; Voltage 50V; LCSC C307331
C22, C24: 330pF; C_0402_1005Metric; LCSC C13533
C23: 10uF; C_0805_2012Metric; LCSC C1713
C25: 4.7nF; C_0402_1005Metric; LCSC C1538
C26: 100nF; C_0402_1005Metric; LCSC C1525; not fitted
C29: 100pF; C_0402_1005Metric; LCSC C1546
C31: 47pF; C_0402_1005Metric; LCSC C1567
C38: 2.2uF; C_1206_3216Metric; LCSC C50254
C39: 220uF; CP_Elec_8x10; LCSC C46550469
D1: GREEN; LED_0603_1608Metric; LCSC C965804
D2: ESDA25P35-1U1M; DFN1610-2_L1.6-W1.0-P1.05-RD; MPN ESDA25P35-1U1M; LCSC Part C1974707
F1: 8A; Fuse_1206_3216Metric; LCSC C5383193
FB1: BLM18KG601SN1D; L_0603_1608Metric; LCSC C85833
J1: TX; TestPoint_Pad_D1.5mm; not fitted
J2: TC2030; Tag-Connect_TC2030-IDC-NL_2x03_P1.27mm_Vertical
J3: Bus_PCI_Express_x1; BUS_PCIexpress_x1; not fitted
J4: USB_C_Receptacle_USB2.0_14P; USB-C-SMD_GT-USB-7004; LCSC C2686968
J5: GND; TestPoint_Pad_D1.5mm; not fitted
J6: RX; TestPoint_Pad_D1.5mm; not fitted
L1: 1uH; L_Sunlord_MWSA0603S; LCSC C112125
L2: 5.6uH; L_Sunlord_MWSA1005S; LCSC C17700183
Q1, Q2, Q3, Q4: BSC059N04LS6; TDSON-8-1; LCSC C534356
R1, R2, R9, R10, R26: 100K; R_0402_1005Metric; LCSC C25741
R3, R4, R5, R6, R8: 4.7K; R_0402_1005Metric; LCSC C25900
R7: 1K; R_0402_1005Metric; LCSC C11702
R11: 49.9K; R_0402_1005Metric; LCSC C25897
R12, R16, R18, R20: 10K; R_0402_1005Metric; LCSC C25744
R13: 47K; R_0402_1005Metric; LCSC C25792
R14, R21: 1R; R_0402_1005Metric; LCSC C25086
R15: 2.2R; R_1206_3216Metric; LCSC C2907376; not fitted
R17, R19: 100K; R_0402_1005Metric; Voltage 50V; LCSC C25741
R22: 75K; R_0402_1005Metric; LCSC C25798
R23: 45.3K; R_0402_1005Metric; LCSC C2933099
R24: 56.2K; R_0402_1005Metric; LCSC C54968
R25: 57.6K; R_0402_1005Metric; LCSC C2960799
R27: R007; R_1206_3216Metric; LCSC C7420011
R28: R010; R_1206_3216Metric; LCSC C105362
TH1: NTC_CONV; R_0603_1608Metric; LCSC C52155402
TH2: NTC_PLUG; R_0603_1608Metric; LCSC C52155402
U1: STM32G071C8T6; LQFP-48_L7.0-W7.0-P0.50-LS9.0-BL; MPN STM32G071C8T6; LCSC C529341
U2: LP2985-3.3; SOT-23-5; LCSC C89826
U3: TPS55288RPMR; VQFN-HR-26_L4.0-W3.5_TPS55288RPMR; MPN TPS55288RPMR; LCSC Part C2864583
U4: TLV7022DDFR; SOT-23-8_L2.9-W1.6-P0.65-LS2.8-BR; MPN TLV7022DDFR; LCSC Part C2862588
U5: TCPP02-M18; QFN-18_L3.5-W3.5-P0.50-TL-EP2.2; MPN TCPP02-M18; LCSC Part C3662929
U6: USBLC6-2SC6; SOT-23-6; LCSC C2687116

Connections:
+3.3V: C1.1, C2.1, C3.1, C4.1, C12.1, C30.1, J2.1, R3.1, R4.1, R5.1, R6.1, R10.1, R12.1, R13.1, R16.1, R25.1, U1.4 (VBAT), U1.5 (VREF+), U1.6 (VDD/VDDA), U2.5 (VOUT), U4.8 (VCC)
+5V: C7.1, C34.1, C35.1, D1.2 (A), FB1.2, J3.A12 (+5V), J3.B12 (+5V), U2.1 (VIN), U2.3 (ON/~OFF), U5.3 (VCC_VCONN)
/CC1: C22.1, J4.A5 (CC1), U5.13 (CC1c)
/CC2: C24.1, J4.B5 (CC2), U5.11 (CC2c)
/CONVERTER_FLT: R10.2, U1.24 (PB12), U3.14 (FB/INT)
/DR1H: R14.2, U3.2 (DR1H)
/DR1L: R21.2, U3.1 (DR1L)
/EMI_VIN: C6.1, C8.1, C9.1, C10.1, C15.1, L1.2, Q1.5 (D), U3.3 (VIN)
/EN: J3.B16 (EN), R1.1, U1.47 (PB8), U3.4 (EN/UVLO)
/IANA: C26.1, U1.12 (PA1), U5.5 (IANA)
/NTC_CONV: C14.1, R12.2, TH1.1, U1.19 (PB0)
/NTC_PLUG: C16.1, R16.2, TH2.1, U1.21 (PB2)
/OVP_CEIL: R25.2, R26.1, U4.5 (INB+)
/OVP_REF: R2.1, U1.15 (PA4), U4.3 (INA+)
/SCL: J3.A14 (SCL), R4.2, U1.45 (PB6)
/SDA: J3.B14 (SDA), R3.2, U1.46 (PB7)
/SW1: C17.1, C20.1, L2.1, Q1.1 (S), Q1.2 (S), Q1.3 (S), Q2.5 (D), R15.1, U3.23 (SW1)
/SW2: C21.1, L2.2, U3.21 (SW2), U3.25 (SW2)
/SWCLK: J2.4, U1.36 (PA14-BOOT0)
/SWDIO: J2.2, U1.35 (PA13)
/TCPP_EN: R8.2, R9.1, U1.43 (PB4), U4.1 (OUTA), U4.7 (OUTB), U5.1 (EN)
/UCPD_CC1: U1.28 (PA8), U5.2 (CC1)
/UCPD_CC2: U1.27 (PB15), U5.4 (CC2)
/USART_RX: J6.1 (Pin_1_1), U1.14 (PA3)
/USART_TX: J1.1 (Pin_1_1), U1.13 (PA2)
/USB_DATA: J4.A6 (D+), J4.A7 (D-), J4.B6 (D+), J4.B7 (D-), U6.1 (I/O1)
/USB_SCL: R6.2, U1.22 (PB10), U3.5 (SCL), U5.17 (SCL)
/USB_SDA: R5.2, U1.23 (PB11), U3.6 (SDA), U5.16 (SDA)
/VBUS: C38.1, D2.1, J4.A4 (VBUS), J4.A9 (VBUS), J4.B4 (VBUS), J4.B9 (VBUS), R19.1, R27.1, U5.8 (VBUSc)
/VBUS_GATE: C31.2, Q3.4 (G), Q4.4 (G), U5.6 (GATE)
/VBUS_SENSE: C19.1, R19.2, R20.1, U1.11 (PA0)
/VBUS_SRC: Q3.1 (S), Q3.2 (S), Q3.3 (S), Q4.1 (S), Q4.2 (S), Q4.3 (S), U5.7 (SRC)
/VBUSf: Q4.5 (D), R27.2, U5.9 (Isense)
/VIN: F1.2, L1.1
/VIN_PREFUSE: F1.1, J3.A2 (VIN), J3.A3 (VIN), J3.A4 (VIN), J3.A5 (VIN), J3.A6 (VIN), J3.A7 (VIN)
/VOUT: C31.1, Q3.5 (D), R17.1, R28.2, U3.13 (ISN)
/VOUT_CONV: C32.1, C33.1, C36.1, C37.1, C39.1, R28.1, U3.11 (VOUT), U3.12 (ISP), U3.26 (VOUT)
/VOUT_SENSE: C18.1, R17.2, R18.1, U1.20 (PB1), U4.2 (INA-), U4.6 (INB-)
/~ALERT: J3.B15 (~ALERT), U1.44 (PB5)
/~FLG: R13.2, U1.25 (PB13), U5.18 (FLGn)
/~RST: C5.1, J2.3, U1.10 (PF2-NRST)
GND: C1.2, C2.2, C3.2, C4.2, C5.2, C6.2, C7.2, C8.2, C9.2, C10.2, C11.2, C12.2, C13.2, C14.2, C15.2, C16.2, C17.2, C18.2, C19.2, C22.2, C23.2, C24.2, C25.2, C26.2, C27.2, C28.2, C29.2, C30.2, C32.2, C33.2, C34.2, C35.2, C36.2, C37.2, C38.2, C39.2, D2.2, J2.5, J3.A8 (PGND), J3.A9 (PGND), J3.A10 (PGND), J3.A11 (GND), J3.A13 (GND), J3.A15 (GND), J3.A16 (GND), J3.A17 (GND), J3.A18 (GND), J3.B1 (PGND), J3.B2 (PGND), J3.B3 (PGND), J3.B4 (PGND), J3.B5 (PGND), J3.B6 (PGND), J3.B7 (PGND), J3.B8 (PGND), J3.B9 (PGND), J3.B10 (GND), J3.B11 (GND), J3.B13 (GND), J3.B18 (GND), J4.A1 (GND), J4.A12 (GND), J4.B1 (GND), J4.B12 (GND), J4.S1 (SHIELD), J5.1 (Pin_1_1), Q2.1 (S), Q2.2 (S), Q2.3 (S), R1.2, R2.2, R9.2, R11.1, R15.2, R18.2, R20.2, R22.2, R23.2, R26.2, TH1.2, TH2.2, U1.7 (VSS/VSSA), U1.29 (PA9), U1.32 (PA10), U2.2 (GND), U3.9 (PGND), U3.10 (AGND), U3.24 (PGND), U4.4 (VEE), U5.10 (GND), U5.14 (GND), U5.15 (I2C_ADD), U5.19 (EP), U6.2 (GND)
unnamed: C25.1, R24.2
unnamed: D1.1 (K), R7.1
unnamed: J3.A1 (~PRSNT1), J3.B17 (~PRSNT2)
unnamed: Q1.4 (G), R14.1
unnamed: Q2.4 (G), R21.1
unnamed: R8.1, U1.37 (PA15)
unnamed: R7.2, U1.42 (PB3)
unnamed: C11.1, U2.4 (BP)
unnamed: C20.2, U3.22 (BOOT1)
unnamed: C21.2, U3.20 (BOOT2)
unnamed: C29.1, R24.1, U3.18 (COMP)
unnamed: C13.1, U3.7 (DITH/SYNC)
unnamed: R11.2, U3.8 (FSW)
unnamed: R23.1, U3.17 (ILIM)
unnamed: R22.1, U3.15 (MODE)
unnamed: C23.1, C28.1, FB1.1, U3.19 (VCC)
unnamed: C27.1, U5.12 (CBIAS)

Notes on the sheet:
ESD
Output Failsafe
VCC Power
Debug Port
Output Measurement/Smoothing
Output Shutdown
Controller
NTC Temp Probes
Power Filtering
Output Safety
PD Power Conversion
USB Connector
Voltage Sense

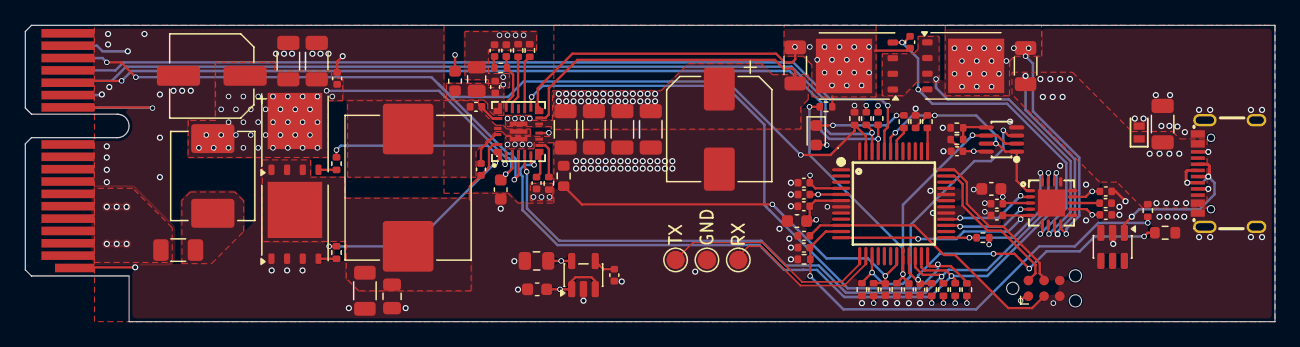
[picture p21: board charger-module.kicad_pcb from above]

Board: 4 copper layers, 101.2 x 24.0 mm, 91 parts (1 on the bottom side), 59 nets.

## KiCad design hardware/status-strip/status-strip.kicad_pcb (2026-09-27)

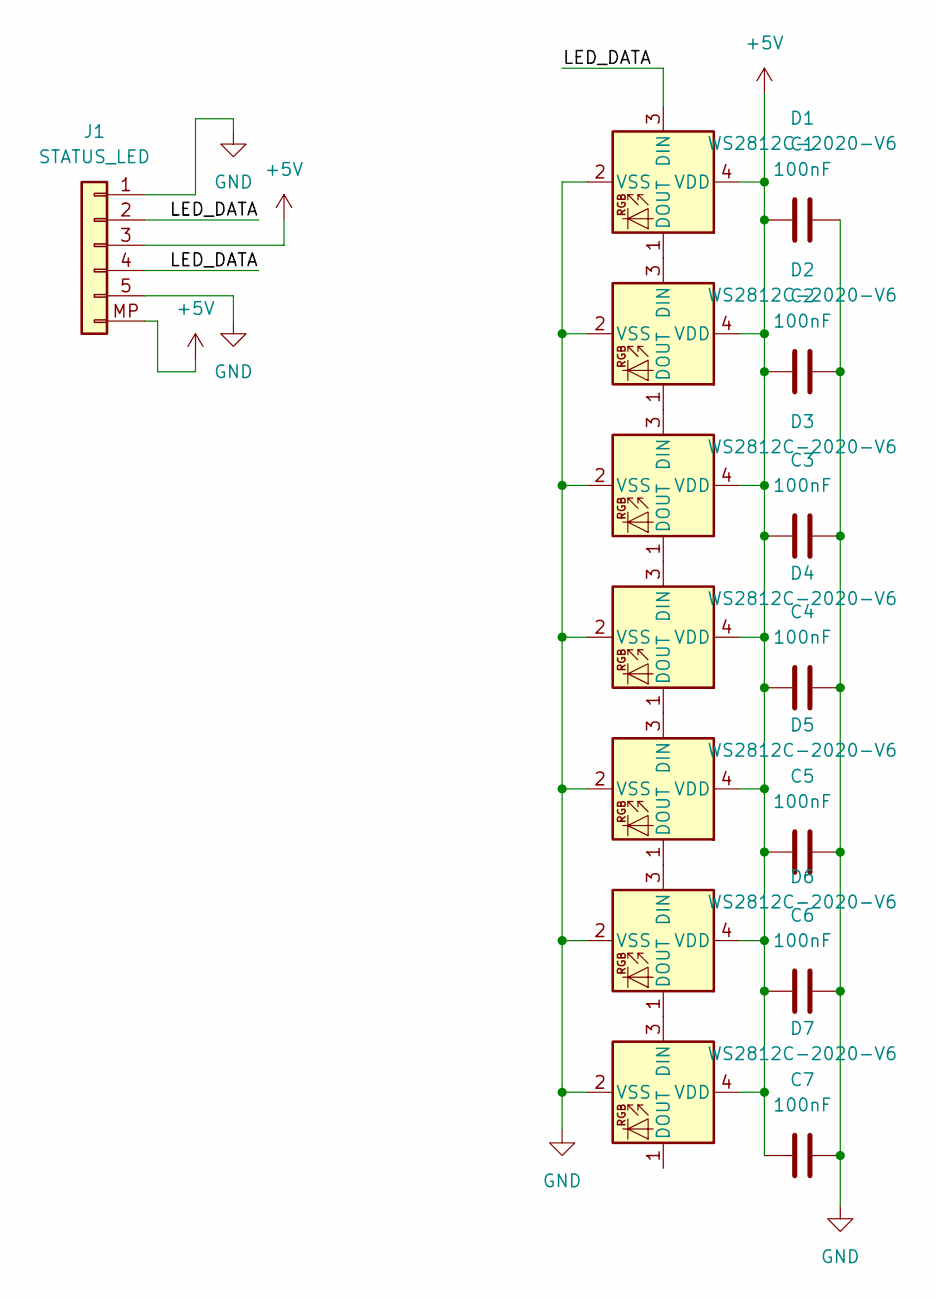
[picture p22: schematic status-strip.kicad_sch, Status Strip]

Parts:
C1, C2, C3, C4, C5, C6, C7: 100nF; C_0402_1005Metric; LCSC C307331
D1, D2, D3, D4, D5, D6, D7: WS2812C-2020-V6; LED_WS2812B-2020_PLCC4_2.0x2.0mm; LCSC C55109522
J1: STATUS_LED; JST_SH_BM05B-SRSS-TB_1x05-1MP_P1.00mm_Vertical; LCSC C160391

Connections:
+5V: C1.1, C2.1, C3.1, C4.1, C5.1, C6.1, C7.1, D1.4 (VDD), D2.4 (VDD), D3.4 (VDD), D4.4 (VDD), D5.4 (VDD), D6.4 (VDD), D7.4 (VDD), J1.3, J1.MP (Pin_6)
/LED_DATA: D1.3 (DIN), J1.2, J1.4
GND: C1.2, C2.2, C3.2, C4.2, C5.2, C6.2, C7.2, D1.2 (VSS), D2.2 (VSS), D3.2 (VSS), D4.2 (VSS), D5.2 (VSS), D6.2 (VSS), D7.2 (VSS), J1.1, J1.5
unnamed: D1.1 (DOUT), D2.3 (DIN)
unnamed: D2.1 (DOUT), D3.3 (DIN)
unnamed: D3.1 (DOUT), D4.3 (DIN)
unnamed: D4.1 (DOUT), D5.3 (DIN)
unnamed: D5.1 (DOUT), D6.3 (DIN)
unnamed: D6.1 (DOUT), D7.3 (DIN)

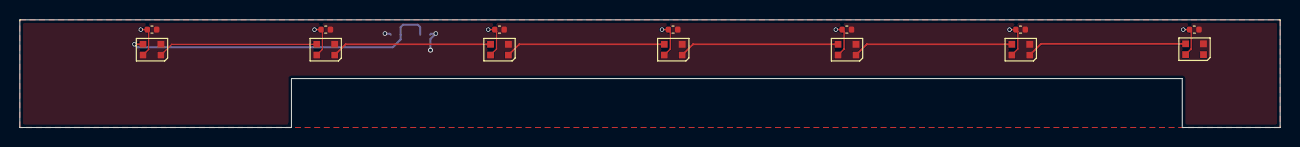
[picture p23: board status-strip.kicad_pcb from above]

Board: 2 copper layers, 128.8 x 11.0 mm, 15 parts (1 on the bottom side), 9 nets.

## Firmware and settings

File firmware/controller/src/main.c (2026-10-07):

#include <stdio.h>

#include "hardware/watchdog.h"
#include "pico/multicore.h"
#include "pico/stdlib.h"

#include "boot_reason_hw.h"
#include "bus_cap.h"
#include "button.h"
#include "cli.h"
#include "engine/engine.h"
#include "fault_log.h"
#include "flash_map.h"
#include "health.h"
#include "ipc.h"
#include "led_sched.h"
#include "log_sink.h"
#include "manifold.h"
#include "net/http.h"
#include "net/https.h"
#include "net/improv.h"
#include "net/mqtt.h"
#include "net/net.h"
#include "net/update_check.h"
#include "settings.h"
#include "stack_probe.h"
#include "update.h"
#include "ups/ups.h"
#include "vin.h"

#define WATCHDOG_TIMEOUT_MS 5000

// Try-before-you-buy: a trial image commits itself once the engine heartbeat
// has been fresh for this long without a break and, when WiFi is configured,
// the network has come up at least once since boot. A link that came up at
// all proves the image's network stack works; one that flaps afterwards is
// the environment's doing and must not revert a good image. If the trial
// never gets there, reboot; the bootrom then falls back to the previous
// image, since an uncommitted trial is skipped on a normal boot.
#define UPDATE_HEALTH_MS   (10 * 1000)
#define UPDATE_DEADLINE_MS (10 * 60 * 1000)

// A blade is being taken through its ROM bootloader (blade_update.h). The
// bootloader resets the blade when the controller goes quiet in the middle
// of a command (AN2606: 1 s), and a blade that is not yet set to boot
// through its bootloader then starts on a half-written flash and stays
// there until it is reseated. A restart of our own choosing waits the few
// seconds for the trip to end.
static bool blade_trip_running(void) {
    if (!ipc_engine_alive()) return false; // nothing is being written, and the restart may be the cure
    telemetry_t t;
    ipc_snapshot_read(&t);
    for (unsigned i = 0; i < NUM_PORTS; i++)
        if (t.port[i].state == PORT_STATE_UPDATE) return true;
    return false;
}

// The button held to the end: back to factory settings. The chain is all
// red by now (CMD_LED_HOLD 255 went out first); give it and the console
// line a moment, then wipe and restart. Never returns.
static void factory_reset(void) {
    printf("button: factory reset — restoring defaults and rebooting\n");
    sleep_ms(300);
    if (!settings_wipe()) printf("settings: wipe failed\n");
    if (!https_wipe()) printf("https: wipe failed\n");
    fault_log_clear();
    sleep_ms(20);
    boot_reason_mark(BOOT_REQUESTED, 0, 0, 0, 0);
    watchdog_reboot(0, 0, 0);
    for (;;) tight_loop_contents();
}

int main(void) {
    stack_probe_paint(); // before anything deepens the stack
    boot_reason_read();  // before anything else can touch the watchdog scratch
    stdio_init_all();
    log_sink_init(); // from here on the console is mirrored for syslog / the API
    flash_map_init();
    settings_load();
    update_auto_settle(); // a trial that was rolled back is not installed again by itself
    fault_log_init();
    ipc_init();

    // The bus voltage is read once before the engine starts: a chassis that
    // powers up on a sagging bus then brings its first blade up under the
    // 3 A cap (bus_cap.h). The command waits in the queue for the engine's
    // first pass, which dispatches commands before it touches a port.
    vin_init(); // the bus-voltage divider, where the board has one
    vin_poll(to_ms_since_boot(get_absolute_time()));
    bus_cap_init();
    if (bus_cap_poll(to_ms_since_boot(get_absolute_time()), vin_mv())) {
        engine_cmd_t c = {.op = CMD_SET_CEILING, .arg = bus_cap_ma()};
        ipc_cmd_push(&c);
        printf("bus: %s at power-up, ports capped at %u A\n", vin_status_str(), BUS_CAP_MA / 1000);
    }

    // Core 1: charger management engine (sole owner of I2C/expander/LEDs).
    // Launched before any networking so power supervision never waits on it.
    multicore_launch_core1(engine_main);

    cli_init();
    net_init();
    http_init();
    ups_init(); // probes the UPS header; harmless with nothing plugged in
    button_init(); // the front-panel button (GP22)

    if (!update_key_count())
        printf("update: no signing keys in this build; unsigned images install from the network\n");

    char boot_text[80];
    boot_reason_text(boot_reason_last(), boot_text, sizeof(boot_text));
    printf("power-manifold controller %s (slot %s%s, boot: %s; 'help' for console)\n> ",
           FW_VERSION, flash_map_slot_name(),
           flash_map_update_pending() ? ", TRIAL" : "", boot_text);

    // Arm the watchdog only once the engine has proven alive; afterwards it is
    // fed only while BOTH cores make progress (this loop running + engine
    // heartbeat fresh), so either core stalling reboots the system.
    bool wd_armed = false;
    bool boot_logged = false; // one fault-log record per boot, once flash writes are safe
    bool trial = flash_map_update_pending();
    uint32_t healthy_since = 0;
    bool net_seen = false; // the network has been up at some point since boot
    uint8_t led_flags_sent = 0; // engine's view starts with no chassis overlay
    uint8_t led_level_sent = g_settings.led_brightness; // what the engine applied at init
    uint8_t led_base_seen = g_settings.led_brightness;
    bool ups_seen = false; // Home Assistant learns about the UPS when it shows up
    bool bus_low_seen = false; // the bus low flag as last recorded in the fault log
    uint8_t hold_sent = 0; // button hold progress the chain is showing

    for (;;) {
        uint32_t now_ms = to_ms_since_boot(get_absolute_time());

        cli_poll();
        improv_poll(now_ms); // before net_poll: sees a join result before the retry
        net_poll(now_ms);
        mqtt_poll(now_ms);
        update_check_poll(now_ms);
        update_auto_poll(now_ms);
        log_sink_poll(now_ms);
        ups_poll(now_ms);
        vin_poll(now_ms);
        if (bus_cap_poll(now_ms, vin_mv())) {
            engine_cmd_t c = {.op = CMD_SET_CEILING, .arg = bus_cap_ma()};
            ipc_cmd_push(&c);
            if (bus_cap_on()) printf("bus: %s, ports capped at %u A\n", vin_status_str(), BUS_CAP_MA / 1000);
            else printf("bus: %s for %u s, port cap lifted\n", vin_status_str(), BUS_CAP_HOLD_MS / 1000);
        }
        if (ups_present() != ups_seen) {
            ups_seen = ups_present();
            mqtt_names_changed(); // re-run discovery: the UPS entities come and go with it
        }

        // chassis conditions shown on the chassis light (led_pattern.h)
        uint8_t led_flags = (uint8_t)((improv_active() ? LED_CHASSIS_BLE_OPEN : 0) |
                                      (http_setup_open(now_ms) ? LED_CHASSIS_SETUP_OPEN : 0) |
                                      (net_up() || now_ms < NET_START_GRACE_MS ? 0 : LED_CHASSIS_NET_DOWN) |
                                      (vin_low() || vin_high() ? LED_CHASSIS_BUS_FAULT : 0));
        if (led_flags != led_flags_sent) {
            engine_cmd_t c = {.op = CMD_LED_CHASSIS, .arg = led_flags};
            if (ipc_cmd_push(&c)) led_flags_sent = led_flags;
        }

        // LED schedule: night window / idle dimming, re-pushed whenever the
        // effective level or the base brightness moved (a direct `led N`
        // from any surface shows at once, then the schedule has its say)
        led_mode_t lm = led_sched_update(&g_settings, net_epoch(), now_ms);
        uint8_t led_level = led_sched_level(&g_settings, lm);
        if (led_level != led_level_sent || g_settings.led_brightness != led_base_seen) {
            engine_cmd_t c = {.op = CMD_LED_BRIGHTNESS, .arg = led_level};
            if (ipc_cmd_push(&c)) {
                led_level_sent = led_level;
                led_base_seen = g_settings.led_brightness;
            }
        }

        // front-panel button: a short press wakes a dimmed chain (and is
        // answered with a flash) and restarts the Ethernet setup hour while
        // no API token is stored, a long press opens the BLE provisioning
        // window, holding it until the chain has filled and turned red
        // restores factory settings (button.h)
        switch (button_poll(now_ms)) {
        case BUTTON_SHORT: {
            printf("button: wake\n");
            http_setup_window_restart(now_ms);
            if (!g_settings.api_token[0]) printf("setup: settings open over Ethernet for an hour\n");
            led_sched_wake(now_ms); // the schedule block above pushes the level next pass
            engine_cmd_t c = {.op = CMD_LED_ACK, .arg = 200};
            ipc_cmd_push(&c);
            break;
        }
        case BUTTON_LONG:
            printf(improv_open(IMPROV_WINDOW_MS, "button")
                       ? "button: Wi-Fi setup window open\n"
                       : "button: Wi-Fi setup unavailable on this build\n");
            break;
        case BUTTON_VERY_LONG: {
            engine_cmd_t c = {.op = CMD_LED_HOLD, .arg = 255};
            ipc_cmd_push(&c);
            factory_reset();
            break;
        }
        default:
            break;
        }
        // the fill on the chain follows the hold in coarse steps; 0 and 255
        // (nothing / the reset firing) always go out exactly
        uint8_t hold = button_hold_progress();
        if (hold && hold != 255) hold = (uint8_t)((hold & ~7u) | 1u);
        if (hold != hold_sent) {
            engine_cmd_t c = {.op = CMD_LED_HOLD, .arg = hold};
            if (ipc_cmd_push(&c)) hold_sent = hold;
        }

        // engine events: log faults durably first, then publish (best-effort)
        engine_evt_t evt;
        while (ipc_evt_pop(&evt)) {
            if (evt.type == EVT_STATE_CHANGE) led_sched_activity(now_ms); // wakes the LEDs
            if (evt.type == EVT_UPDATE)
                printf("port %u: blade firmware %lu.%lu.%lu %s\n", evt.port + 1,
                       (unsigned long)(evt.arg >> 16), (unsigned long)((evt.arg >> 8) & 0xFF),
                       (unsigned long)(evt.arg & 0xFF),
                       evt.code == UPDATE_WRITTEN ? "written and started"
                       : evt.code == UPDATE_BOOT_OPT ? "set to boot through the bootloader" : "started");
            fault_log_event(&evt);
            mqtt_event(&evt);
            // a port that switched itself off is administratively off now:
            // the "last" boot policy records it like a switch from any surface
            if (evt.type == EVT_CHARGE && evt.code == CHARGE_AUTO_OFF && evt.port < NUM_PORTS &&
                settings_port_admin_note(evt.port, false))
                settings_save_later();
        }

        if (http_reboot_due(now_ms) && !blade_trip_running()) {
            // asked for from the web UI after a settings change; the CLI's
            // 'reboot' is immediate for the same watchdog reason
            if (settings_save_pending()) settings_save();
            printf("http: rebooting\n");
            sleep_ms(20);
            boot_reason_mark(BOOT_REQUESTED, 0, 0, 0, 0);
            watchdog_reboot(0, 0, 0);
        }
        if (update_reboot_due() && !blade_trip_running()) {
            // scheduled by the OTA endpoint once its 200 response is queued
            printf("update: rebooting into slot %s (trial)\n", update_slot_name());
            sleep_ms(20); // let the CDC console flush
            update_reboot_now();
        }

        if (ipc_engine_alive()) {
            if (!wd_armed) {
                watchdog_enable(WATCHDOG_TIMEOUT_MS, true);
                wd_armed = true;
            }
            watchdog_update();

            if (!boot_logged) {
                boot_logged = true;
                fault_log_boot(boot_reason_last());
                telemetry_t t;
                char start[64];
                ipc_snapshot_read(&t); // the heartbeat follows the first snapshot
                health_start_text(&t, start, sizeof(start));
                printf("engine: %s\n", start);
            }

            // The bus crossing its low flag goes into the fault log: the
            // backplane's under-voltage cut, a volt further down, restarts
            // the controller, so this record is what a brown-out leaves
            // behind. Written here, with the engine up, because flash
            // writes need core 1 parked.
            if (vin_low() != bus_low_seen) {
                bus_low_seen = vin_low();
                engine_evt_t e = {.type = EVT_BUS, .port = CHASSIS_EVT_PORT,
                                  .code = bus_low_seen ? BUS_LOW : BUS_RECOVERED, .arg = vin_mv()};
                fault_log_event(&e);
                mqtt_event(&e);
            }

            if (settings_migration_pending()) {
                printf(settings_migrate()
                           ? "settings: migrated into the data partition\n"
                           : "settings: migration save failed; still on legacy sectors\n");
            }

            int saved = settings_save_poll(now_ms);
            if (saved) {
                printf(saved > 0 ? "settings: saved\n"
                                 : "settings: save failed\n");
            }
        }

        if (trial) {
            if (net_up()) net_seen = true;
            bool healthy = ipc_engine_alive() &&
                           (!g_settings.wifi_ssid[0] || net_seen);
            if (!healthy) {
                healthy_since = 0;
            } else if (!healthy_since) {
                healthy_since = now_ms ? now_ms : 1;
            } else if (now_ms - healthy_since >= UPDATE_HEALTH_MS) {
                if (flash_map_commit_update()) {
                    printf("update: slot %s committed\n", flash_map_slot_name());
                    trial = false;
                    update_auto_settle();
                } else {
                    printf("update: commit failed, retrying\n");
                    healthy_since = 0;
                }
            }
            if (trial && now_ms >= UPDATE_DEADLINE_MS && !blade_trip_running()) {
                printf("update: never became healthy; reverting to previous image\n");
                sleep_ms(50);
                boot_reason_mark(BOOT_TRIAL_REVERT, 0, 0, 0, 0);
                watchdog_reboot(0, 0, 0);
            }
        }

        sleep_ms(2);
    }
}

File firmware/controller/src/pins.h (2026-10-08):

#pragma once

// Controller GPIO map. Two boards run this firmware:
//   - the production controller card, hardware/controller: the default
//     PICO_BOARD=pwrman_controller_card (boards/), which defines
//     PWRMAN_CONTROLLER_CARD;
//   - the Pico 2 W on the pcie-breakout, a development stand-in until the
//     card exists (also the W6100-EVB-Pico2 in the same socket):
//     PICO_BOARD=pico2_w.
// I2C, the Ethernet pins and the UPS link are common to both; the other
// backplane signals and the reset drivers differ.
//
// GP16-GP21 are RESERVED for the wired-Ethernet path. WIZnet's EVB-Pico2
// boards put the Ethernet chip on SPI0 GP16-19 with RSTn=GP20 / INTn=GP21, so
// a W6100-EVB-Pico2 drops into the dev socket unchanged, and the controller
// card copies the same mapping so firmware carries over.

#ifdef PWRMAN_CONTROLLER_CARD
// hardware/controller, from the KiCad netlist (2026-09-09)
#define PIN_EXP_RST_N   1  // TCA9539 reset, via Q1 (2N7002, 100k gate pull-down)
#define PIN_LED_DATA    2  // WS2812C light bar (7 pixels) through the backplane, via PIO
#define PIN_I2C_SDA     4  // I2C0 to backplane; 4.7k to 3.3 V on the card (R32)
#define PIN_I2C_SCL     5  // 4.7k to 3.3 V on the card (R41)
#define PIN_EXP_INT_N   6  // TCA9539 INT#: blade presence change (internal pull-up)
#define PIN_ALERT_N     7  // GLOBAL_ALERT#; 4.7k to 3.3 V on the card (R43)
#define PIN_MUX_RST_N   8  // TCA9548A reset, via Q2 (2N7002, 100k gate pull-down)
#define PIN_BUTTON      22 // front-panel button SW3 to GND (1k series, 100 nF), see button.h
#define PIN_VIN_SENSE   28 // ADC2: VIN through 120k / 10k (R13/R14), see vin.h
#define VIN_ADC_INPUT   2
// The reset lines are driven through N-channel FETs against the backplane's
// 10k pull-ups to 5 V: the GPIO drives a gate, so HIGH asserts the reset,
// and the RP2350's boot-time pad pull-down leaves both FETs off. A
// controller reboot therefore never resets the expander; the warm-start
// path (engine.c) relies on that.
#define RST_ASSERTED_LEVEL 1
#else
// Pico 2 W on the pcie-breakout: the breakout header's pins, push-pull
#define PIN_LED_DATA    2  // WS2812C light bar (7 pixels) through the backplane, via PIO
#define PIN_ALERT_N     3  // GLOBAL_ALERT#: wire-OR of all blade ALERT# lines
#define PIN_I2C_SDA     4  // I2C0 to backplane (TCA9548A + TCA9539 upstream side)
#define PIN_I2C_SCL     5
#define PIN_EXP_INT_N   6  // TCA9539 INT#: blade presence change
#define PIN_MUX_RST_N   7  // TCA9548A hardware reset
#define PIN_EXP_RST_N   8  // TCA9539 hardware reset
#define PIN_BUTTON      22 // no button on the carrier; a wire from GP22 to GND acts as one (button.h)
// The carrier drives the reset lines directly: LOW asserts. While the Pico
// itself is in reset, its pad pull-down against the backplane's 10k pull-up
// should still leave the line above the expander's input-high threshold
// (per datasheet; verify at bring-up), so a controller reboot does not
// reset the expander here either.
#define RST_ASSERTED_LEVEL 0
#endif

#define I2C_BUS         i2c0
#ifdef PWRMAN_INTERNAL_PULLUPS
// CARRIER_INTERNAL_PULLUPS: the RP2350 pad pull-ups (50-80k) stand in for the
// three 4.7k resistors on the breakout. Tens of kilohms into the bus
// capacitance is far too slow for 400 kHz; 100 kHz leaves the slow edges
// inside the low period, and once a mux channel is open that segment's 4.7k
// pull-ups stiffen the upstream side as well. Bench only, one or two blades
// (ran the 2026-09-23 bring-up).
#define I2C_BAUD        (100 * 1000)
#else
#define I2C_BAUD        (400 * 1000)
#endif

// Wired Ethernet: WIZnet W6100 on SPI0, the EVB-Pico2 mapping (NET_ETH)
#define PIN_ETH_MISO    16 // SPI0 RX
#define PIN_ETH_CS_N    17 // driven as a GPIO
#define PIN_ETH_SCK     18
#define PIN_ETH_MOSI    19 // SPI0 TX
#define PIN_ETH_RST_N   20
#define PIN_ETH_INT_N   21 // level-low while socket 0 has a frame waiting
#define ETH_SPI         spi0
#define ETH_SPI_HZ      (20 * 1000 * 1000)

// UPS serial link: a Mean Well LAD-xxxBU supply on the controller card's UPS
// header (JST SH: TX, GND, RX), 3.3 V TTL through 1k series resistors, the
// LAD's fixed 9600 8N1. The cable crosses: our TX lands on the LAD's UART_RX
// (CN2 pin 13), its UART_TX (pin 14) on our RX. Free pins on the Pico 2 W
// carrier too, so the same image probes for a supply on every board.
#define PIN_UPS_TX      12 // UART0 TX
#define PIN_UPS_RX      13 // UART0 RX
#define UPS_UART        uart0
#define UPS_UART_IRQ    UART0_IRQ
#define UPS_BAUD        9600

// I2C addresses, verified against the backplane netlist (2026-08-30):
// TCA9548A A0=A1=A2=GND, TCA9539 A0=A1=GND. Blade parts sit behind the mux,
// one blade per channel, so identical per-blade addresses never conflict.
#define ADDR_TCA9548A   0x70
#define ADDR_TCA9539    0x74
#define ADDR_INA226     0x40  // per blade
#define ADDR_MPQ4242    0x61  // per blade

// TCA9548A channel N carries slot N+1 (SC0/SD0 = SCL1/SDA1); channels 6-7 spare.
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

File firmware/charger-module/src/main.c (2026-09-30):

#include <stdint.h>

#include "usbpd_core.h"
#include "usbpd_dpm_conf.h"
#include "usbpd_dpm_core.h"
#include "usbpd_hw_if.h"

#include "adc.h"
#include "backplane.h"
#include "blade.h"
#include "console.h"
#include "dac.h"
#include "hw.h"
#include "port.h"
#include "power.h"
#include "private_bus.h"
#include "regmap.h"
#include "supervisor.h"

// The blade's firmware: ST's USB-PD stack as the port's policy engine, the
// supervisor as everything around it. The stack owns the main loop
// (USBPD_DPM_Run) and calls the supervisor once per turn.

void USBPD_PORT0_IRQHandler(void);

void UCPD1_2_IRQHandler(void) {
    USBPD_PORT0_IRQHandler();
}

static bool start_stack(void) {
    USBPD_HW_IF_GlobalHwInit();
    if (USBPD_DPM_InitCore() != USBPD_OK) return false;
    if (USBPD_DPM_UserInit() != USBPD_OK) return false;
    if (USBPD_VDM_UserInit(USBPD_PORT_0) != USBPD_OK) return false;
    if (USBPD_DPM_InitOS() != USBPD_OK) return false;
    hw_tick_hook = USBPD_DPM_TimerCounter;
    return true;
}

int main(void) {
    hw_init();
    regmap_init(hw_reset_cause());
    regmap_set_boot(hw_boot_via_loader() ? BLADE_BOOT_VIA_LOADER : 0);
    console_init();
    adc_init();
    dac_init();
    private_bus_init();
    backplane_init();

    console_str("\ncharger module " FW_VERSION ", reset cause ");
    console_hex(hw_reset_cause(), 2);
    console_str("\n");

    port_init();
    power_init();
    supervisor_init();

    if (start_stack()) USBPD_DPM_Run(); // does not return

    // Without the stack there is no port: the fault keeps it dark, and the
    // blade still answers the controller
    console_str("PD stack did not start\n");
    supervisor_stack_failed();
    for (;;) supervisor_run();
}

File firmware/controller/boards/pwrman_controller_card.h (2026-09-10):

// power-manifold controller card (hardware/controller): RP2350A with a
// W25Q128 (16 MB) flash, a WIZnet W6100-L on SPI0 GP16-21, a Raspberry Pi
// RM2 radio module on the Pico 2 W's CYW43 pin map, and a PCIe x1 card edge
// into the backplane's management slot. Select it with
//   -DPICO_BOARD=pwrman_controller_card
// (CMakeLists adds this directory to PICO_BOARD_HEADER_DIRS, and picks the
// 16 MB partition layout for it). The backplane signals sit on different
// GPIOs than on the Pico 2 W carrier and the two reset lines are driven
// through 2N7002 FETs, so src/pins.h keys its map off PWRMAN_CONTROLLER_CARD.
// Pins verified against the KiCad netlist, 2026-09-09.

#ifndef _BOARDS_PWRMAN_CONTROLLER_CARD_H
#define _BOARDS_PWRMAN_CONTROLLER_CARD_H

// pico_cmake_set PICO_PLATFORM=rp2350
pico_board_cmake_set(PICO_PLATFORM, rp2350)
// pico_cmake_set PICO_CYW43_SUPPORTED = 1
pico_board_cmake_set(PICO_CYW43_SUPPORTED, 1)

// For board detection
#define PWRMAN_CONTROLLER_CARD

// --- RP2350 VARIANT ---
#define PICO_RP2350A 1

// --- UART ---
// The only UART header is the UPS link (J5, JST SH: TX, GND, RX). Console
// output goes over USB (and RTT); this is where stdio_uart would land if it
// were ever enabled.
#ifndef PICO_DEFAULT_UART
#define PICO_DEFAULT_UART 0
#endif
#ifndef PICO_DEFAULT_UART_TX_PIN
#define PICO_DEFAULT_UART_TX_PIN 12
#endif
#ifndef PICO_DEFAULT_UART_RX_PIN
#define PICO_DEFAULT_UART_RX_PIN 13
#endif

// --- LED ---
// no PICO_DEFAULT_LED_PIN: the status LEDs are the backplane's WS2812 chain

// --- I2C (backplane, TCA9548A + TCA9539 upstream side) ---
#ifndef PICO_DEFAULT_I2C
#define PICO_DEFAULT_I2C 0
#endif
#ifndef PICO_DEFAULT_I2C_SDA_PIN
#define PICO_DEFAULT_I2C_SDA_PIN 4
#endif
#ifndef PICO_DEFAULT_I2C_SCL_PIN
#define PICO_DEFAULT_I2C_SCL_PIN 5
#endif

// --- SPI (the W6100) ---
#ifndef PICO_DEFAULT_SPI
#define PICO_DEFAULT_SPI 0
#endif
#ifndef PICO_DEFAULT_SPI_SCK_PIN
#define PICO_DEFAULT_SPI_SCK_PIN 18
#endif
#ifndef PICO_DEFAULT_SPI_TX_PIN
#define PICO_DEFAULT_SPI_TX_PIN 19
#endif
#ifndef PICO_DEFAULT_SPI_RX_PIN
#define PICO_DEFAULT_SPI_RX_PIN 16
#endif
#ifndef PICO_DEFAULT_SPI_CSN_PIN
#define PICO_DEFAULT_SPI_CSN_PIN 17
#endif

// --- FLASH ---
// W25Q128JVSIQ on the QSPI pins with the dedicated chip select. The generic
// Winbond second stage the Pico boards use (W25Q080 in name only) drives the
// whole W25Q family's quad read.
#define PICO_BOOT_STAGE2_CHOOSE_W25Q080 1

#ifndef PICO_FLASH_SPI_CLKDIV
#define PICO_FLASH_SPI_CLKDIV 2
#endif

// pico_cmake_set_default PICO_FLASH_SIZE_BYTES = (16 * 1024 * 1024)
pico_board_cmake_set_default(PICO_FLASH_SIZE_BYTES, (16 * 1024 * 1024))
#ifndef PICO_FLASH_SIZE_BYTES
#define PICO_FLASH_SIZE_BYTES (16 * 1024 * 1024)
#endif

// No PICO_VBUS_PIN / PICO_VSYS_PIN: USB VBUS is tied to the 5 V rail and GP29
// is the radio's clock, as on the Pico 2 W.

// pico_cmake_set_default PICO_RP2350_A2_SUPPORTED = 1
pico_board_cmake_set_default(PICO_RP2350_A2_SUPPORTED, 1)
#ifndef PICO_RP2350_A2_SUPPORTED
#define PICO_RP2350_A2_SUPPORTED 1
#endif

// --- RM2 radio (CYW43439), the Pico 2 W wiring ---
// cyw43 SPI pins can't be changed at runtime
#ifndef CYW43_PIN_WL_DYNAMIC
#define CYW43_PIN_WL_DYNAMIC 0
#endif

// gpio pin to power up the cyw43 chip (WL_ON and BT_ON tied together)
#ifndef CYW43_DEFAULT_PIN_WL_REG_ON
#define CYW43_DEFAULT_PIN_WL_REG_ON 23u
#endif

// gpio pin for spi data out to the cyw43 chip
#ifndef CYW43_DEFAULT_PIN_WL_DATA_OUT
#define CYW43_DEFAULT_PIN_WL_DATA_OUT 24u
#endif

// gpio pin for spi data in from the cyw43 chip
#ifndef CYW43_DEFAULT_PIN_WL_DATA_IN
#define CYW43_DEFAULT_PIN_WL_DATA_IN 24u
#endif

// gpio (irq) pin for the irq line from the cyw43 chip
#ifndef CYW43_DEFAULT_PIN_WL_HOST_WAKE
#define CYW43_DEFAULT_PIN_WL_HOST_WAKE 24u
#endif

// gpio pin for the spi clock line to the cyw43 chip
#ifndef CYW43_DEFAULT_PIN_WL_CLOCK
#define CYW43_DEFAULT_PIN_WL_CLOCK 29u
#endif

// gpio pin for the spi chip select to the cyw43 chip
#ifndef CYW43_DEFAULT_PIN_WL_CS
#define CYW43_DEFAULT_PIN_WL_CS 25u
#endif

#endif

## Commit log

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2024-07-07 fix: remove mosfet (#30)
    * fix: remove unused mosfet
    feat: add usb header
    chore: remove unneeded vbus-5v jumper
    * chore: add kiri diff action
    [charger-module.kicad_pcb, charger-module.kicad_sch]
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2024-07-08 fix: add decoupling caps to i2c and swd switches
    fix: add pullup resistor to i2c switch reset pin
    [backplane.kicad_pcb, backplane.kicad_sch]
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2024-07-15 chore: add component placement corrections
    chore: rotate uart header so ground is pin 1
    [esp32-mgmt-module.kicad_pcb, esp32-mgmt-module.kicad_sch]
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2024-07-24 fix: swap usb-serial tx/rx lines
    chore: update jumper pads to be easier to use
    [esp32-mgmt-module.kicad_pcb, esp32-mgmt-module.kicad_sch]
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2026-08-30 feat(controller): scaffold native RP2350 controller firmware
    Replace the V1 distributed firmware architecture with the V2 native
    pico-sdk controller for the Pico 2 W management module:
    - firmware/controller: dual-core scaffold — core 1 charger engine
    (TCA9548A/TCA9539/INA226/MPQ4242 drivers, per-port state machine,
    power budget arbiter, WS2812C PIO status LEDs), core 0 management
    (WiFi, MQTT + Home Assistant discovery, embedded web UI/REST API,
    USB CLI console), seqlock/queue IPC, dual-core watchdog; GP16-21
    reserved for the future W5500 wired Ethernet path
    - remove V1 esphome components, CircuitPython charger-module firmware,
    and obsolete esp32/pi-pico/rp2040 mgmt hardware mo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
    [HR911105A.step, esp32-mgmt-module.kicad_pcb, esp32-mgmt-module.kicad_sch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]
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2026-08-31 feat(controller): add OTA update endpoint writing the inactive A/B slot
    POST /api/v1/update streams a firmware image (release UF2 or raw .bin,
    auto-detected) into the inactive slot picked by
    rom_pick_ab_partition_during_update, then reboots into it via a bootrom
    flash-update boot so the existing TBYB trial/commit flow takes over.
    - update_image.c: pico-free UF2 framing + picobin IMAGE_DEF scanner/patcher
    (host-tested, static_asserted against SDK constants; validated against the
    real controller.bin/uf2, including picotool's E10 erratum marker block)
    - update.c: streaming writer with the slot's first sector erased first and
    written last (an interrupted transfer never leaves a bootable h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
    [cli.c, main.c]
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2026-08-31 feat(controller): per-port and chassis energy sensors
    The engine integrates delivered power at the tick rate; telemetry gains
    since-boot mWh per port and for the chassis, surfaced as kWh in the port
    telemetry ("e"), the status JSON ("energy_kwh"), the web UI table, and
    HA discovery as total_increasing energy sensors for the energy dashboard
    (reboots read as ordinary meter resets). Existing power/voltage/current
    sensors also gain state_class measurement for long-term statistics.
    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
    [engine.c]
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2026-08-31 feat(controller): persistent fault log in the data partition
    Faults and probe failures now survive reboots: a 64KB ring of one-record
    flash pages right after the settings pair (~256 records, oldest sector
    recycled on wrap, rate-limited appends). Each record keeps the event,
    the port's power/contract at that moment, uptime, and wall-clock time
    once SNTP has synced. `faults` lists the newest twenty on the CLI,
    `faults clear` wipes the ring.
    Engine events are now drained in the main loop — logged durably first,
    then published to MQTT best-effort — so fault capture no longer depends
    on broker health.
    Claude-Session: https://claude.ai/c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
    [cli.c, main.c]
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2026-09-02 feat(backplane): update connector to xt60
    fix(backplane): switch to lower emi ap64352 buck and 5V rail
    [backplane.kicad_pcb, backplane.kicad_sch]
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2026-09-02 fix(controller): core 0 stack overflow into the engine, plus bench diagnostics
    The default RP2350 layout put core 0's 4KB stack in SCRATCH_Y directly
    above core 1's stack in SCRATCH_X. A plain boot already used ~3.5KB of it,
    and the HTTP handler kept a 1.6KB JSON buffer on that stack inside the
    lwIP IRQ context, so concurrent fetches overflowed into the engine's
    topmost frame — the telemetry struct it publishes. Symptoms on the bench:
    garbage telemetry (hundreds of kW) in the status JSON under load, and
    core 1 corruption. memmap_bigstack.ld moves core 0's stack to the top of
    main SRAM at 16KB and the JSON buffer becomes static. Measured after the
    fix under 6-way concurrent load: core 0 pea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
    [cli.c, engine.c, main.c]
2026-09-02 feat(controller): Improv Wi-Fi BLE provisioning
    Provision WiFi credentials over Bluetooth LE using the Improv Wi-Fi
    standard (https://www.improv-wifi.com/ble/), so the Home Assistant
    companion app and the Web Bluetooth provisioner work unchanged. BTstack
    runs on the same CYW43 as WiFi.
    - src/net/improv.c: GATT service + state machine. A provisioning window
    opens by itself while the device has no credentials or has been off the
    network for 5 min, and on request for 10 min (CLI `improv on`, new HA
    "Open BLE provisioning" button); `improv off` closes it and holds the
    automatic windows until the next `improv on` or reboot. The BT
    controller is powered down outside a window. BLE carrie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
    [cli.c, engine.c, main.c]
2026-09-02 feat(controller): W6100 wired Ethernet as an lwIP netif
    Wired networking through a WIZnet W6100 on SPI0 GP16-21 (the EVB-Pico2
    mapping the production board copies), as a second lwIP netif beside the
    CYW43 WiFi one. The chip runs in MACRAW mode so its own TCP/IP offload
    goes unused and everything above the MAC (DHCP, mDNS, MQTT, HTTP, OTA
    pull) is the same code as over WiFi.
    - src/net/w6100.c: MACRAW driver behind a small bus seam (w6100_hw.h;
    w6100_hw_pico.c is SPI0 at 20 MHz plus CS/RST GPIOs). Hardware and
    software reset with the chip/net/PHY lock handshake, CIDR identity
    check, all 32 KB of socket memory to socket 0 after zeroing the other
    seven, MAC filter on, socket 0 RECV rout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
    [cli.c, pins.h]
2026-09-02 feat(controller): web UI settings panel with Improv setup secret
    Finish first-time setup from the phone that provisioned Wi-Fi: the
    status page gains a Settings panel for the device name, MQTT broker,
    chassis budget, fan policy and API token, backed by GET/POST
    /api/v1/settings and POST /api/v1/reboot.
    /settings always needs a bearer. Improv's success redirect carries a
    one-shot setup secret (http://<ip>/?s=...) while no API token is
    stored; it stands in for the token on /settings for 10 minutes, and a
    request on it must set a token, which retires it. Console-provisioned
    or wired-only boxes unlock the panel with a token set via `token`.
    Budget and fan changes apply live through the engine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
    [main.c]
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2026-09-04 feat(controller): report why the controller booted and surface crashes
    Every boot now says what caused it: on the banner, in `info`, in the
    status JSON (`boot`), on the page's chassis line, in the MQTT status
    with a diagnostic "Last boot reason" sensor, and as one fault-log record
    per boot (EVT_BOOT: code = reason | core << 8, arg = pc, lr and cfsr in
    the two mW fields).
    boot_reason.c is hardware-free: it decodes POWMAN CHIP_RESET, the
    watchdog reason register and four scratch registers. Deliberate reboots
    (console/web, OTA, trial revert) stamp a mark before resetting, and the
    HardFault handler stamps the core, PC, LR and CFSR so a crash is readable
    on the next boot without a probe. Measure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
    [cli.c, main.c]
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2026-09-04 feat(controller): per-port current limit on every surface, applied live
    The engine already enforced port_limit_ma (probe, throttle restore) but
    nothing let a user set it. It is the current field of every PDO the blade
    advertises, so the wattage ceiling scales with the voltage the sink picks.
    - CMD_PORT_LIMIT: a powered port reprograms the MPQ4242 ceiling and, with
    a sink attached, re-announces its capabilities so the contract shrinks
    at once; a throttled port keeps the tighter budget clamp and recovers to
    the new limit; unpowered ports pick it up at their next probe
    - the INA226 alert is the emergency trip and no longer tracks the setting:
    it is fixed at 125 % of the blade's 5 A cei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
    [cli.c]
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2026-09-04 feat(controller): aggregate problem indicator with a Home Assistant binary sensor
    One "needs attention" flag for the chassis, computed by the new health
    module on core 0 from the telemetry snapshot and the management plane:
    any port in FAULT (named), the engine stalled, a trial firmware image
    not yet committed, or the wired link down while WiFi carries the
    traffic. It comes with a short description, e.g.
    "faults: Port 2, Desk; trial firmware uncommitted".
    Surfaces: `problem` / `problems` in the status JSON and in the MQTT
    status payload, a `problems:` line in `info`, a red line under the
    chassis summary on the page, and a diagnostic *Problem* binary sensor
    (device class problem) in Home Ass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
    [cli.c]
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2026-09-05 feat(controller): console log ring with UDP syslog and GET /api/v1/log
    Diagnosing a box across the room meant a USB cable. Everything the
    firmware prints now also lands in a 4 KB ring (log_ring, hardware-free
    and host-tested: line extraction, an endless line split at 240 bytes,
    overflow resync with an exact count of the lines the reader lost, and
    the RFC 5424 formatter). A pico stdio driver feeds it under a critical
    section, since printf runs from the main loop and lwIP's worker alike.
    Settings layout v8 adds syslog_host / syslog_port (v7 payload pinned at
    552, port defaults to 514). When a host is set the main loop's
    log_sink_poll resolves it (re-resolved every 10 minutes, retried every
    mi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
    [cli.c, main.c]
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2026-09-05 fix(controller): bench findings for addressing output and the syslog backlog
    Three things the Pico 2 W showed that the host build could not:
    - `info` printed the gateway in the netmask slot, and the `static:` line
    showed one address three times: net_mask_str/net_gw_str both returned
    lwIP's single ip4addr_ntoa buffer, and net_ip4_str has one buffer of
    its own, so several in one printf collapsed to the last. Own buffers
    (ip4addr_ntoa_r) for the first two, one call per printf for the third.
    - After a power-up only the last early log line reached the syslog
    receiver. lwIP keeps one packet per unresolved ARP entry and drops the
    rest, so the first burst of datagrams died while the re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
    [cli.c]
2026-09-05 feat(controller): charge-complete detection with off-when-charged and a sleep timer
    While a sink is attached the engine now watches its measured draw. Once
    it has stayed under settings charged_mw (default 500 mW; a full phone
    trickles well under that) for charged_min (default 10 minutes) the port
    reads "charged". The verdict is symmetric — draw back above the floor
    for as long clears it — so a laptop draining while plugged in is not
    mistaken for full, and detach or re-attach starts the clock over.
    Two per-port auto-off policies build on it. "Off when charged"
    (port_auto_off bitmask) switches the port off the moment it reads
    charged. The sleep timer (port_sleep_min, up to 24 h) switches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
    [cli.c, main.c]
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2026-09-05 feat(controller): console fault injection for the simulated backplane
    FAKE_BLADES builds could only replay the demo script, so the fault
    paths — fault log, Problem sensor, events, auto-recovery, charge-complete
    — were exercised on a bare board only by waiting for the script's one
    over-current trip a minute. The console's `sim` command now drives the
    simulated blades directly: seat/unseat, attach (mV, mA), detach, load
    (measured draw as a percentage of the contract current), an INA226 OCP
    trip, each MPQ4242 fault bit (sticky until cleared), a silent chip on
    the next probes, and mux or expander failures the engine recovers from
    by resetting the bus. `sim pause` stops the script so injected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
    [cli.c, engine.c]
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2026-09-06 ci: stamp KiCad dates in one job instead of a racing matrix
    The date-update job fanned out over a matrix of changed files, and every
    matrix job committed and pushed to main from the same base. Only the first
    push could win; the rest were rejected with "cannot lock ref 'refs/heads/main'".
    The controller card's first push hit exactly that: the .kicad_pcb job landed
    2026-09-06 and the .kicad_sch job was rejected, leaving the two files with
    different dates on main.
    Stamp every changed file in a single job and a single commit. The file list
    now arrives as JSON and is read through jq, so paths with spaces survive and
    the filename is no longer interpolated into the shell. Also resync the
    controlle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
    [controller.kicad_sch]
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2026-09-07 feat(controller): per-port voltage cap on the advertised PDO set
    A port can now be capped at 5, 9, 12 or 15 V (20 V = the whole table):
    the MPQ4242's PDO enable mask withholds every fixed PDO above the cap and
    any PPS range whose maximum reaches past it, so a sink can never negotiate
    higher. Applied at probe (mpq4242_configure takes the cap alongside the
    current limit) and live through CMD_PORT_VOLT, which re-advertises at once
    when a sink is attached; a throttle keeps working on the new bus voltage.
    Settings layout v11 adds port_max_mv[6] (older records upgrade to 20 V).
    Surfaces: console `port <n> volt 5|9|12|15|20` and a `cap` column in
    `status`; status JSON and MQTT telemetry `max_v`; s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
    [cli.c]
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2026-09-08 feat(controller): add RPi RM2 and wire up remaining pins
    fix(controller): move rj45 jack inset 1mm
    [controller.kicad_pcb, controller.kicad_sch]
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2026-09-08 fix(controller): enable the internal pull-up on EXP_INT#
    EXP_INT# is an open-drain output from the TCA9539 and nothing pulls it up:
    the backplane's 10k to 5 V (R6) was removed from the design and the
    controller card has no resistor on it. The engine init left the RP2350 pad
    at its default pull-down, so the line would read permanently asserted and
    refresh_presence() would run every tick. ALERT#, SDA and SCL keep their
    external pull-ups on the controller card and get no on-chip pull.
    Claude-Session: https://claude.ai/code/session_019yyR59Vr6piBm8SYFASu6G
    [engine.c]
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2026-09-08 feat(controller): Mean Well LAD UPS supply on the card's UPS header
    A LAD-xxxU security/UPS supply talks a 9600 8N1 TTL UART with its own
    frame (read 0x55 / write 0xAA, length, 16-bit address, data, CRC-8), not
    Modbus. src/ups/ carries the protocol (builder, CRC, a parser that
    resynchronises through line noise), a UART0 seam with an interrupt-fed
    receive ring on GP12/GP13, and a poller that probes every 5 s until a
    supply answers, then reads status, mains voltage, load current and battery
    voltage at 1 Hz and the per-block voltages and undervoltage cutoff every
    10 s, spacing requests 20 ms apart and dropping back to probing after five
    missed replies.
    Surfaces: a `ups` object in the status JS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
    [cli.c, main.c, pins.h]
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2026-09-10 fix(controller-firmware): clear the pad pull-down on SDA, SCL and ALERT#
    Every RP2350 pad boots with its pull-down enabled and neither
    gpio_set_function nor gpio_init clears it, so the three lines with
    external 4.7k pull-ups (R32/R41/R43 on the controller card, or wired on
    the pcie-breakout) were sharing them with a 50-80k pull-down, dragging the
    idle high to ~3.0 V against the 5 V-powered mux and expander's 3.5 V VIH.
    Disable both pulls on those pins at engine init; EXP_INT# keeps its
    internal pull-up.
    Fix the GPIO-map rows in the README that placed the I2C pull-ups on the
    backplane (its upstream side has none) and copy it into the docs site.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
    [engine.c]
2026-09-10 feat(controller-firmware): warm start keeps port power across a controller reboot, plus the card's board header
    A controller reboot (firmware update, requested reboot, watchdog,
    HardFault) no longer cuts port power. The expander runs from the
    backplane's 5 V and neither board asserts its reset when the RP2350
    resets, so it keeps its registers: the engine now reads it first and,
    when it still holds this firmware's configuration, adopts the output
    register as it stands instead of pulsing EXP_RST# and driving every EN
    low. Only the power-on state gets the cold reset-and-configure path.
    Blades found powered are re-supervised in priority order, 50 ms apart,
    without touching EN: identify the INA2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
    [cli.c, engine.c, main.c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]
2026-09-10 feat(controller-firmware): DC bus voltage monitor on the controller card
    The card divides VIN by 13 (R13 120k / R14 10k, C18 across the bottom
    leg) into GP28/ADC2, so 3.3 V full scale reads 42.9 V and the bus clamp
    can never take the pin past the rail. Core 0 takes eight conversions
    every 100 ms and reports a one-second average, about 10 mV a count. The
    reference is the card's 3.3 V rail and the divider is 1 % parts, so a
    new vin_cal setting (permille, 900-1100; settings layout 12, exported and
    imported as vin_cal) trims the gain: `vin cal <volts>` on the console
    stores the trim that matches a meter, `vin cal reset` clears it. A bus
    under 19 V or over 29 V, half a volt of hysteresis either w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
    [cli.c, main.c, pins.h]
2026-09-10 feat(controller-firmware): front-panel button — wake the LEDs, open BLE, hold to factory-reset
    The controller card's SW3 (GP22 to ground through 1k, 100 nF across the
    input, the pad's pull-up) is polled from the main loop and debounced over
    30 ms. Three gestures:
    short press released within 3 s: wake. A chain dimmed by the night
    window or idle dimming, or blanked, comes up to full
    brightness for 30 s (a new wake on the LED schedule that
    outranks both, and restarts the idle clock), and the whole
    chain flashes white for 200 ms to say the press registered.
    Identify stays Improv's own pattern.
    long press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
    [cli.c, engine.c, main.c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]
2026-09-10 fix(backplane): switch TVS diode to bidirectional
    feat(backplane): swap fan FET for higher voltage spec
    [backplane.kicad_pcb, backplane.kicad_sch]
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2026-09-16 feat(backplane): LM74800 input stage with OVP and inrush limit, SMD fuse
    - Replace the LM74700 + IRFS7530 ideal diode with an LM74800-Q1 driving
    two BSC014N06NS in common drain: Q1 blocks reverse polarity and reverse
    current, Q2 cuts the bus above ~34 V (100 k / 3.74 k on OV, releasing
    below ~31 V) and ramps it up at power-on (1 k + 220 nF on HGATE, about
    0.5 A into the chassis capacitance) so the XT60 no longer sparks
    - 1 uF charge-pump capacitor, 100 nF at VS, 1 uF ceramic on the raw side
    beside the SMCJ33CA, Kelvin A sense to Q1's source
    - Replace the ATO blade holder, rated 30 A, with a soldered 40 A 2410 fuse (Reomax STS2400, 63 V DC, 500 A breaking capacity)
    - Layout: VIN_MID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
    [backplane.kicad_pcb, backplane.kicad_sch]
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2026-09-17 fix(backplane): C8 charge-pump capacitor to a 50 V X7R 0603
    The LM74800's CAP pin only ever sits 12-14 V above VS (charge pump
    turn-off 13.2 V typical, 15 V absolute maximum CAP to VS per datasheet),
    so the 100 V 0805 part on C8 was oversized. C8 is now a 1 uF 50 V X7R
    0603 (Samsung CL10B105KB8NQNC, LCSC C5199872); X7R rather than X5R
    because it sits beside the input FET island, which can run past 85 C.
    The pads shrank, the short tracks to it were redrawn and the copper
    zones refilled. No other schematic or layout change.
    Claude-Session: https://claude.ai/code/session_01RqsqYE269iTAiNYg5zHQ8L
    [backplane.kicad_pcb, backplane.kicad_sch]
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2026-09-17 feat(backplane): undervoltage cut-out on the LM74800 and a TPS16416 eFuse for the 5 V rail
    Input stage: the low-bus cut-out moves from the buck's enable pin to the
    LM74800's EN/UVLO (R7 100 k / R8 6.49 k from the common-drain mid-point,
    ~20.2 V on, ~18.6 V off), so a sagging supply now disconnects the entire
    bus through Q2 and the input draw drops to microamps. VSNS moves to the
    raw input and the OV ladder hangs off SW, as the datasheet draws it, so
    the ladder is de-powered in shutdown. Layout re-arranged around U2 to
    follow the TI example; the VIN_MID island is ~348 mm2 per outer layer
    with 84 stitching vias and solid tab connections.
    Logic rail: a TPS16416 eFuse (U5, VSON-10) sits between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
    [backplane.kicad_pcb, backplane.kicad_sch]
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2026-09-19 feat(controller): hold every PDO to 100 W, so the 21 V PPS range advertises 4.75 A
    The port current limit is written into the current field of every PDO,
    which let the 3.3-21 V PPS range promise 21 V x 5 A = 105 W. A new
    PORT_POWER_MAX_MW (100 W) ceiling now cuts a PDO's current back, rounded
    down to that PDO's step, wherever its top voltage times the current
    would pass it. With the present table only the 21 V PPS range is
    affected: it advertises 4.75 A (99.75 W) while the fixed 20 V PDO and
    everything below keep the full 5 A.
    The cap sits in mpq4242_set_max_current_ma (and the fixed/PPS setters),
    so a lower user limit still wins, the budget throttle path inherits it,
    and the warm-start che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
    [cli.c]
2026-09-24 fix(controller): release the reset lines to the backplane's 5 V pull-ups
    The Pico 2 W carrier drove MUX_RST# and EXP_RST# push-pull high at
    3.3 V against the backplane's 10 kΩ pull-ups to 5 V. The TCA9548A and
    TCA9539 want 0.7 × VCC = 3.5 V for a high, so on the first backplane
    bring-up the expander kept falling back to its power-on registers: every
    EN pin became an input, no blade ever saw EN high, each MPQ4242 stayed
    in shutdown, and a dark MPQ4242 clamps the I2C segment it shares with
    the INA226, so every probe failed behind the mux while the upstream
    parts still answered. Released now means a high-impedance input with
    pulls off, asserted drives low (src/engine/rst_line.h); the controll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
    [cli.c, engine.c, pins.h]
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2026-09-29 fix(controller): correct C6/C7 footprint name and assembly fields
    - Rename Local Library C_0805_Wide to C_0402_Wide; its pads were always
    an 0402 land, matching the C23733 (CL05A475MP5NRNC) part it carries
    - Drop stale RPI_DB manufacturer_pn/lcsc_pn fields from C6/C7/C9 that
    named a different part than the LCSC field
    - Mark J1 card edge DNP and out of the BOM/position files
    - Add 180 degree JLCPCB rotation correction for Q1/Q2
    [controller.kicad_pcb, controller.kicad_sch]
2026-09-29 fix(backplane): update assembly fields for JLCPCB
    - U2 LCSC C3215600 in the schematic (matches the PCB); rotation
    correction 0 degrees
    - Q1/Q2 JLCPCB correction -0.95 mm x, 270 degrees
    - F1 back in the BOM and position files
    - M1 fan header LCSC C234181
    - U1 alternative part SCT2432STER
    - U5 field renamed LCSC Part -> LCSC
    [backplane.kicad_pcb, backplane.kicad_sch]
2026-09-29 fix(charger-module): update assembly fields for JLCPCB
    - Mark J1/J5/J6 (TX/GND/RX test pads) DNP and out of the BOM and
    position files
    - Add JLCPCB rotation corrections: Q1-Q4 and U6 270 degrees, U2 180
    degrees
    [charger-module.kicad_pcb, charger-module.kicad_sch]
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
